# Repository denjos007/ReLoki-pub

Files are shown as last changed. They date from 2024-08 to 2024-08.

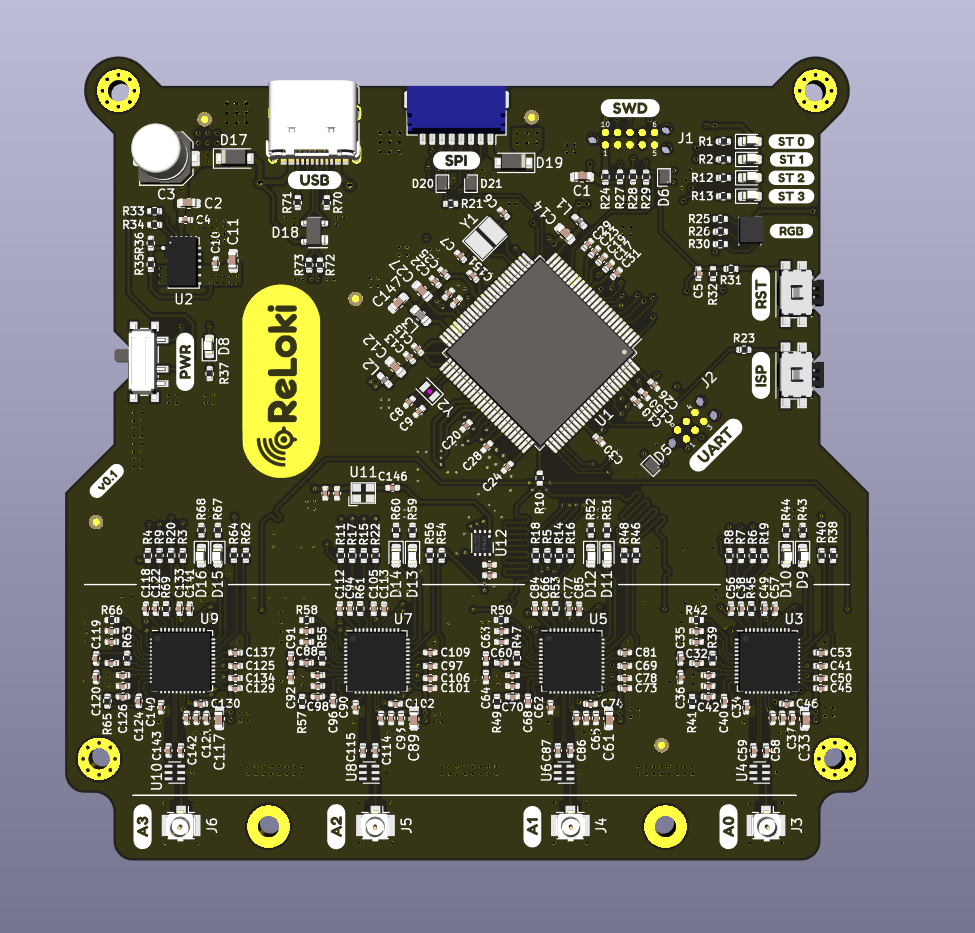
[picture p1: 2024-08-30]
hardware/ReLoki_ECAD/Print_OP/ReLoki_ECAD_PCB_3D-v0_1_0.png

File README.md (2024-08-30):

# ReLoki-pub

ReLoki  is a Infrastructre-free UWB based relative localization system. It uses a combination of TWR and Geometric AoA for full 3D localizattion and message transfer between participating agents. 

This repository will contain the hardware schematics to get ReLoki operational. 

# Hardware

The files to fabricate the PCB for ReLoki are in hardware folder.
1. ReLoki_ECAD: ReLoki Controller PCB 
2. UWB_Antenna_Circular: Individual circular antenna
3. UWB_Antenna_SqArray: UWB antenna in the uniform circular array configuration
4. 3D Parts: 3D printed parts for the RTA Antenna array.

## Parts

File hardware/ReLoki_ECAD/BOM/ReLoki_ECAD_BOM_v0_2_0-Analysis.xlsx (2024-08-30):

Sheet: ReLoki_ECAD_BOM_v0_2_0
Ref | Value | Footprint | Vendor | Link | Price/unit | Qnty | Buffer | N.boards | Total Qty | Total Price | Remarks | Received
C1, | 10u | Capacitor_SMD:C_0603_1608Metric | Taiyo Yuden | https://www.mouser.com/ProductDetail/Taiyo-Yuden/JMK107ABJ106MA-T?qs=vF%252B8ahGVilcKzRI4EvLHOA%3D%3D | $0.11 | 1 |  | 1 | 1 | $0.11
C2, | 4u7 35V | Capacitor_SMD:C_0603_1608Metric | Murata Electronics | https://www.mouser.com/ProductDetail/Murata-Electronics/GRM188R6YA475KE15D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 | $0.33 | 1 |  | 1 | 1 | $0.33
C3, | 47uF 35V | Capacitor_SMD:C_Elec_5x5.8 | United Chemi Con | https://www.mouser.com/ProductDetail/United-Chemi-Con/EMZR350ARA470ME61G?qs=y6ZabgHbY%252BwapqGfn3nqNQ%3D%3D | $0.58 | 1 |  | 1 | 1 | $0.58
C4, | 10n 35V | Capacitor_SMD:C_0402_1005Metric | TDK | https://www.mouser.com/ProductDetail/TDK/CGA2B3X7R1V103K050BB?qs=NRhsANhppD9oCsWh2mTIKA%3D%3D | $0.10 | 1 |  | 1 | 1 | $0.10
C5, C10, C18, C21, C23, C28, C29, C31, C34, C62, C90, C118, C150, C151, C153, C154, | 10n | Capacitor_SMD:C_0402_1005Metric | TDK | https://www.mouser.com/ProductDetail/TDK/CGA2B3X7R1V103K050BB?qs=NRhsANhppD9oCsWh2mTIKA%3D%3D | $0.10 | 16 |  | 1 | 16 | $1.60
C6, C7, | 8p | Capacitor_SMD:C_0402_1005Metric | Kemet | https://www.mouser.com/ProductDetail/KEMET/CBR04C809B3GAC?qs=kpVq%2FgIAs518pFNfJF4O5w%3D%3D | $0.21 | 2 |  | 1 | 2 | $0.42
C8, C9, | 22p | Capacitor_SMD:C_0402_1005Metric | Kemet | https://www.mouser.com/ProductDetail/KEMET/CBR04C220J5GACAUTO?qs=By6Nw2ByBD1qU5yzrYCnBg%3D%3D | $0.21 | 2 |  | 1 | 2 | $0.42
C11, C12, C147, | 22u | Capacitor_SMD:C_0603_1608Metric | Murata Electronics | https://www.mouser.com/ProductDetail/Murata-Electronics/GRM188R61A226ME15D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 | $0.22 | 3 |  | 1 | 3 | $0.66
C13, C16, C19, C20, C24, C25, C26, C30, C36, C37, C38, C41, C44, C45, C46, C47, C48, C49, C50, C51, C53, C54, C56, C57, C64, C65, C66, C69, C72, C73, C74, C75, C76, C77, C78, C79, C81, C82, C84, C85, C92, C93, C94, C97, C100, C101, C102, C103, C104, C105, C106, C107, C109, C110, C112, C113, C120, C121, C122, C125, C128, C129, C130, C131, C132, C133, C134, C135, C137, C138, C140, C141, C144, C148, C149, C152, | 0u1 | Capacitor_SMD:C_0402_1005Metric | Kemet | https://www.mouser.com/ProductDetail/KEMET/C0402C104K4RACTU?qs=DBJr%252BvBUjU54jK7d4uAeew%3D%3D | $0.11 | 76 |  | 1 | 76 | $8.36
C14, | 4u7 | Capacitor_SMD:C_0603_1608Metric | Taiyo Yuden | https://www.mouser.com/ProductDetail/Taiyo-Yuden/LMK107BJ475KA-T?qs=PzICbMaShUfCoRlxZeLF0g%3D%3D | $0.19 | 1 |  | 1 | 1 | $0.19
C15, C17, C22, | 47p | Capacitor_SMD:C_0402_1005Metric | Kemet | https://www.mouser.com/ProductDetail/KEMET/C0402C470K3RACAUTO?qs=gt1LBUVyoHlYXEU%252BlOISDw%3D%3D | $0.12 | 3 |  | 1 | 3 | $0.36
C27, | 2u2 | Capacitor_SMD:C_0603_1608Metric | Taiyo Yuden | https://www.mouser.com/ProductDetail/Taiyo-Yuden/EMK107ABJ225KA8T?qs=hWgE7mdIu5Tcg5OpvamJ9g%3D%3D | $0.18 | 1 |  | 1 | 1 | $0.18
C32, C60, C88, C116, | 1p2 | Capacitor_SMD:C_0402_1005Metric | Kemet | https://www.mouser.com/ProductDetail/KEMET/CBR04C129B5GACAUTO?qs=By6Nw2ByBD1LE0W42y%2F8KA%3D%3D | $0.19 | 4 |  | 1 | 4 | $0.76 | PLL capacitor; Use C0G as dielectric
C33, C61, C89, C117, | 47u | Capacitor_SMD:C_0603_1608Metric | Murata Electronics | https://www.mouser.com/ProductDetail/Murata-Electronics/GRM188R60J476ME01D?qs=pUKx8fyJudCK31TI9jwJqA%3D%3D | $0.46 | 4 |  | 1 | 4 | $1.84
C35, C63, C91, C119, | 27p | Capacitor_SMD:C_0402_1005Metric | Murata Electronics | https://www.mouser.com/ProductDetail/Murata-Electronics/GJM1555C1H270FB01D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 | $0.17 | 4 |  | 1 | 4 | $0.68 | PLL capacitor; Use C0G as dielectric
C39, C52, C67, C80, C95, C108, C123, C136, | 10p | Capacitor_SMD:C_0402_1005Metric | Kemet | https://www.mouser.com/ProductDetail/KEMET/C0402C100K5RACAUTO?qs=hzBznG4dWXWvk2ClWTGJYg%3D%3D | $0.10 | 8 |  | 1 | 8 | $0.80
C40, C68, C96, C124, | 18p | Capacitor_SMD:C_0402_1005Metric | Murata Electronics | https://www.mouser.com/ProductDetail/Murata-Electronics/GJM1555C1H180FB01D?qs=pwh76yelNxAjV3lxNx675g%3D%3D | $0.17 | 4 |  | 1 | 4 | $0.68 | PLL capacitor; Use C0G as dielectric
C42, C70, C98, C126, | 820p | Capacitor_SMD:C_0402_1005Metric | Murata Electronics | https://www.mouser.com/ProductDetail/Murata-Electronics/GRT1555C1H821FA02D?qs=hd1VzrDQEGhtXTRtEGJzcQ%3D%3D | $0.10 | 4 |  | 1 | 4 | $0.40 | PLL capacitor; Use C0G as dielectric
C43, C55, C71, C83, C99, C111, C127, C139, | 330p | Capacitor_SMD:C_0402_1005Metric | Taiyo Yuden | https://www.mouser.com/ProductDetail/Taiyo-Yuden/HMR105B7331MV-F?qs=DPoM0jnrROXTQ7AM%2FqSNWQ%3D%3D | $0.11 | 8 |  | 1 | 8 | $0.88
C58, C59, C86, C87, C114, C115, C142, C143, | 12p | Capacitor_SMD:C_0402_1005Metric | Kemet | https://www.mouser.com/ProductDetail/KEMET/CBR04C120J5GACAUTO?qs=By6Nw2ByBD1Q0psqJYzcFg%3D%3D | $0.21 | 8 |  | 1 | 8 | $1.68 | RF Capacitor; Use High Q capacitor
C145, | 0n1 | Capacitor_SMD:C_0402_1005Metric | Kemet | https://www.mouser.com/ProductDetail/KEMET/C0402C101K3RACAUTO?qs=DuoOggApuK%2FQ6tIpLsntww%3D%3D | $0.04 | 1 |  | 1 | 1 | $0.04
C146, | 1n | Capacitor_SMD:C_0402_1005Metric | Murata Electronics | https://www.mouser.com/ProductDetail/Murata-Electronics/GCM1555C1H102FA16D?qs=QzBtWTOodeXpE1CTmLdqWQ%3D%3D | $0.17 | 1 |  | 1 | 1 | $0.17 | Clock DC reject capacitor; Use C0G as dielectric
D1, D2, D3, D4, D9, D11, D13, D15, | LED_G | LED_SMD:LED_0603_1608Metric | Wurth Elektronik | https://www.mouser.com/ProductDetail/Wurth-Elektronik/150060VS75000?qs=LlUlMxKIyB1Q1Bi5mQ%2FKLw%3D%3D | $0.16 | 8 |  | 1 | 8 | $1.28
D5, D6, D20, D21, | PESD3V3L4UF | Package_TO_SOT_SMD:SOT-886 | Nexperia | https://www.mouser.com/ProductDetail/Nexperia/PESD3V3L4UF115?qs=LOCUfHb8d9tNJS4807IAKw%3D%3D | $0.48 | 4 |  | 1 | 4 | $1.92
D7, | LED_ABGR | LED_SMD:LED_Cree-PLCC4_2x2mm_CW | Cree | https://www.mouser.com/ProductDetail/Cree-LED/CLMVC-FKA-CLBDGL7LBB79353?qs=fSnNYG2PaKLnACIKsEWrKA%3D%3D | $0.18 | 1 |  | 1 | 1 | $0.18
D8, | LED_R | LED_SMD:LED_0603_1608Metric | Wurth Elektronik | https://www.mouser.com/ProductDetail/Wurth-Elektronik/150060RS75000?qs=LlUlMxKIyB3QnmZ3fw%2FVCA%3D%3D | $0.16 | 1 |  | 1 | 1 | $0.16
D10, D12, D14, D16, | LED_Y | LED_SMD:LED_0603_1608Metric | Wurth Elektronik | https://www.mouser.com/ProductDetail/Wurth-Elektronik/150060YS75000?qs=LlUlMxKIyB0nKmwefHgtZw%3D%3D | $0.16 | 4 |  | 1 | 4 | $0.64
D17, D19, | D_Schottky | Diode_SMD:D_SOD-123F | Nexperia | https://www.mouser.com/ProductDetail/Nexperia/PMEG3020EH115?qs=LOCUfHb8d9sEqW1%2FaaOfTw%3D%3D | $0.44 | 2 |  | 1 | 2 | $0.88
D18, | PRTR5V0U2X | Package_TO_SOT_SMD:SOT-143 | Nexperia | https://www.mouser.com/ProductDetail/Nexperia/PRTR5V0U2X215?qs=LOCUfHb8d9sDkgY4cRj8Lw%3D%3D | $0.53 | 1 |  | 1 | 1 | $0.53
J3, J4, J5, J6, | Uf.l | Connector_Coaxial:U.FL_Hirose_U.FL-R-SMT-1_Vertical | Hirose | https://www.mouser.com/ProductDetail/Hirose-Connector/U.FL-R-SMT-140?qs=PABxe4V6HDrVNWAmh6WKgw%3D%3D | $1.04 | 8 |  | 1 | 8 | $8.32
J7, | USB_C_Receptacle_USB2.0 | Connector_USB:USB_C_Receptacle_XKB_U262-16XN-4BVC11 | GCT | https://www.mouser.com/ProductDetail/GCT/USB4105-GF-A?qs=KUoIvG%2F9IlY%2FMLlBMpStpA%3D%3D | $0.81 | 1 |  | 1 | 1 | $0.81
J8, | JST_SH_SM08B | Connector_JST:JST_SH_SM08B-SRSS-TB_1x08-1MP_P1.00mm_Horizontal | JST | DNP (Local Stock Available) | $0.88 | 1 |  | 1 | 1 | $0.88
L1, L2, | Ferrite | Inductor_SMD:L_0402_1005Metric_Pad0.77x0.64mm_HandSolder | Laird | https://www.mouser.com/ProductDetail/Laird-Performance-Materials/MI0603J601R-10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 | $0.21 | 2 |  | 1 | 2 | $0.42 | Preferred MI0603J601R-10
L3, | 4.7u | Inductor_SMD:L_0603_1608Metric | Murata Electronics | https://www.mouser.com/ProductDetail/Murata-Electronics/LQM18PH4R7MFRL?qs=rkhjVJ6%2F3EI1lKcr9JG66A%3D%3D | $0.45 | 1 |  | 1 | 1 | $0.45
R1, R2, R12, R13, R25, R37, R43, R44, R51, R52, R59, R60, R67, R68, | 270R | Resistor_SMD:R_0402_1005Metric | Panasonic | https://www.mouser.com/ProductDetail/Panasonic/ERJ-2GEJ271X | $0.10 | 19 |  | 1 | 19 | $1.90
R3, R4, R5, R6, R7, R8, R9, R10, R11, R14, R15, R16, R17, R18, R19, R20, R21, R22, R24, | 0R | Resistor_SMD:R_0402_1005Metric | Panasonic | https://www.mouser.com/ProductDetail/Panasonic/ERJ-2GE0R00X?qs=sGAEpiMZZMvdGkrng054t8ugkoYZivkgZAstS7FxYdI%3D | $0.10 | 19 |  | 1 | 19 | $1.90
R23, | 2k2 | Resistor_SMD:R_0402_1005Metric | Panasonic | https://www.mouser.com/ProductDetail/Panasonic/ERJ-2RKF2201X?qs=sGAEpiMZZMvdGkrng054t8AJgcdMkx7xLDqgTrDrCxE%3D | $0.10 | 1 |  | 1 | 1 | $0.10
R26, | 80R | Resistor_SMD:R_0402_1005Metric | Panasonic | https://www.mouser.com/ProductDetail/Panasonic/ERJ-2RKF80R6X?qs=sGAEpiMZZMvdGkrng054t8AJgcdMkx7xczhHERSBWmA%3D | $0.10 | 1 |  | 1 | 1 | $0.10
R27, R28, R29, R38, R46, R54, R62, R76, R77, | 10K | Resistor_SMD:R_0402_1005Metric | Panasonic | https://www.mouser.com/ProductDetail/Panasonic/ERJ-2RKF1002X?qs=sGAEpiMZZMvdGkrng054t8ugkoYZivkgyTBPpPnizTM%3D | $0.10 | 9 |  | 1 | 9 | $0.90
R30, | 60R | Resistor_SMD:R_0402_1005Metric | Panasonic | https://www.mouser.com/ProductDetail/Panasonic/ERJ-2RKF60R4X?qs=sGAEpiMZZMvdGkrng054t8AJgcdMkx7xUvDRJja01bU%3D | $0.10 | 1 |  | 1 | 1 | $0.10
R31, | 100R | Resistor_SMD:R_0402_1005Metric | Panasonic | https://www.mouser.com/ProductDetail/Panasonic/ERJ-2RKF1000X | $0.10 | 1 |  | 1 | 1 | $0.10
R32, R74, R75, | 100K | Resistor_SMD:R_0402_1005Metric | Panasonic | https://www.mouser.com/ProductDetail/Panasonic/ERJ-2RKF1003X | $0.10 | 3 |  | 1 | 3 | $0.30
R33, | 55K | Resistor_SMD:R_0402_1005Metric | Panasonic | https://www.mouser.com/ProductDetail/Panasonic/ERJ-2RKF5492X?qs=sGAEpiMZZMvdGkrng054t8AJgcdMkx7x0kySjptXP2k%3D | $0.10 | 1 |  | 1 | 1 | $0.10
R34, | 62K | Resistor_SMD:R_0402_1005Metric | Panasonic | https://www.mouser.com/ProductDetail/Panasonic/ERA-2AED623X | $0.22 | 1 |  | 1 | 1 | $0.22
R35, | 75K | Resistor_SMD:R_0402_1005Metric | Panasonic | https://www.mouser.com/ProductDetail/Panasonic/ERA-2AED753X | $0.22 | 1 |  | 1 | 1 | $0.22
R36, | 24K | Resistor_SMD:R_0402_1005Metric | Panasonic | https://www.mouser.com/ProductDetail/Panasonic/ERA-2AED243X | $0.22 | 1 |  | 1 | 1 | $0.22
R41, R49, R57, R65, | 270R 1% | Resistor_SMD:R_0402_1005Metric | Panasonic | https://www.mouser.com/ProductDetail/Panasonic/ERA-2ARB271X | $0.82 | 4 |  | 1 | 4 | $3.28 | PLL Resistor; Use higher tolerence
R39, R47, R55, R63, | 16k 1% | Resistor_SMD:R_0402_1005Metric | Panasonic | https://www.mouser.com/ProductDetail/Panasonic/ERA-2ARB163X | $0.76 | 4 |  | 1 | 4 | $3.04 | PLL Resistor; Use higher tolerence
R42, R50, R58, R66, | 11K 1% | Resistor_SMD:R_0402_1005Metric | Panasonic | https://www.mouser.com/ProductDetail/Panasonic/ERA-2ARB113X | $0.82 | 4 |  | 1 | 4 | $3.28 | PLL Resistor; Use higher tolerence
R70, R71, | 5.1K | Resistor_SMD:R_0402_1005Metric | Panasonic | https://www.mouser.com/ProductDetail/Panasonic/ERJ-2RKF5101X?qs=sGAEpiMZZMvdGkrng054t8AJgcdMkx7xIXmurKOGv8o%3D | $0.10 | 2 |  | 1 | 2 | $0.20
R72, R73, | 33R | Resistor_SMD:R_0402_1005Metric | Panasonic | https://www.mouser.com/ProductDetail/Panasonic/ERJ-2RKF33R0X | $0.10 | 2 |  | 1 | 2 | $0.20
R78, R79, R80, R81, R82, | 30R | Resistor_SMD:R_0402_1005Metric | Panasonic | https://www.mouser.com/ProductDetail/Panasonic/ERJ-S02F30R0X?qs=Zyl8A9hlmJrZ4c5s5myrJA%3D%3D | $0.50 | 5 |  | 1 | 5 | $2.50
SW1, SW2, | SW_Push | Button_Switch_SMD:Panasonic_EVQPUL_EVQPUC | Panasonic | DNP (Local Stock Available) | DNP | 2 |  | 1 | 2 | $0.00
SW3, | SW_SPDT | Button_Switch_SMD:SW_SPDT_PCM12 | Panasonic | DNP (Local Stock Available) | DNP | 1 |  | 1 | 1 | $0.00
U1, | LPC55S69JBD100 | Package_QFP_U:HLQFP-100_14x14mm_P0.5mm | NXP | DNP (Local Stock Available) | $10.95 | 1 |  | 1 | 1 | $10.95
U2, | MPM3610 | Package_DFN_QFN_U:MPM3610_QFN-20_5x3mm | MPS | https://www.mouser.com/ProductDetail/Monolithic-Power-Systems-MPS/MPM3610AGQV-Z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 | $2.84 | 1 |  | 1 | 1 | $2.84
U3, U5, U7, U9, | DW1000 | Package_DFN_QFN:QFN-48-1EP_6x6mm_P0.4mm_EP4.2x4.2mm_ThermalVias | Decawave | DNP (Local Stock Available) | $8.78 | 4 |  | 1 | 4 | $35.12
U4, U6, U8, U10, | HHM1595A1 | RF_U:HHM1595A1 | TDK | https://www.mouser.com/ProductDetail/TDK/HHM1595A1?qs=CQ%2FIPMfstfij2T2%252BDRqDhg%3D%3D | $0.53 | 4 |  | 1 | 4 | $2.12
U11, | ATX-13 | Oscillator_U:Oscillator_SMD_Abracon_ATX13-4Pin_2.0x1.6mm | Abracon | https://www.mouser.com/ProductDetail/ABRACON/ATX-13-F-38.400MHz-F05-T?qs=iLbezkQI%252BshZJhENXwm%252B3g%3D%3D | $3.48 | 1 |  | 1 | 1 | $3.48
U12, | SN74AUP1G74RSER | Package_DFN_QFN_U:UQFN-8-1.55x1.55mm_P0.5mm | Texas Instruments | https://www.mouser.com/ProductDetail/Texas-Instruments/SN74AUP1G74RSER?qs=EuM%2FBx4ov4RGFdXbpZrTyw%3D%3D | $0.62 | 1 |  | 1 | 1 | $0.62
U13, U14, | PL133-37 | Package_TO_SOT_SMD:SOT-23-6 | Microchip | https://www.mouser.com/ProductDetail/Microchip-Technology-Atmel/PL133-37TC?qs=kh6iOki%2FeLHkQC7CE79YnA%3D%3D | $0.73 | 2 |  | 1 | 2 | $1.46
Y1, | 16MHz | Crystal_U:Crystal_SMD_Kyocera_CX3225G-2Pin_3.2x2.5mm | Kyocera | https://www.mouser.com/ProductDetail/KYOCERA-AVX/CX3225GA16000D0PTVCC?qs=k8ubvZJoN9Dbjg7lrNet2Q%3D%3D | $0.88 | 1 |  | 1 | 1 | $0.88
Y2, | 32.768kHz | Crystal:Crystal_SMD_2012-2Pin_2.0x1.2mm | ECS | https://www.mouser.com/ProductDetail/ECS/ECS-.327-12.5-12R-TR?qs=fAHHVMwC%252BbjIsh0rr7Av6w%3D%3D | $0.65 | 1 |  | 1 | 1 | $0.65
ANT1 | AH086M555003-T | ~ | Taiyo Yuden | https://www.mouser.com/ProductDetail/Taiyo-Yuden/AH086M555003-T?qs=I6KAKw0tg2yFCZ22SDTD%252Bg%3D%3D | $6.42 | 4 |  | 1 | 4 | $25.68
ANT2 | FXUWB20.07.0100C | ~ | TAOGLAS | https://www.mouser.com/ProductDetail/Taoglas/FXUWB20.07.0100C?qs=rrS6PyfT74cvleDgfnNojg%3D%3D | $7.95 | 4 |  | 1 | 4 | $31.80
J9, J10, J11, J12 | Uf.l Cable | ~ | Hirose | https://www.mouser.com/ProductDetail/Hirose-Connector/U.FL-2LPHF6-068N1T-A-120?qs=uwxL4vQweFN2eJ9voIBidg%3D%3D | $5.07 | 4 |  | 1 | 4 | $20.28
 |  |  |  |  | Total Parts |  |  |  |  | $192.25
 |  |  |  |  | PCB |  |  |  |  | 33.59
 | ` |  |  |  |  |  |  |  |  | $225.84

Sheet: 1 antenna
Ref | Value | Cmp name | Footprint | Description | Vendor | Link | Price/unit | Qnty | Buffer | N.boards | Total Qty | Total Price | Remarks | Received
C1, | 10u | C_Small | Capacitor_SMD:C_0603_1608Metric | Unpolarized capacitor, small symbol | Taiyo Yuden | https://www.mouser.com/ProductDetail/Taiyo-Yuden/JMK107ABJ106MA-T?qs=vF%252B8ahGVilcKzRI4EvLHOA%3D%3D | $0.11 | 1 |  | 1 | 1 | $0.11
C2, | 4u7 35V | C_Small | Capacitor_SMD:C_0603_1608Metric | Unpolarized capacitor, small symbol | Murata Electronics | https://www.mouser.com/ProductDetail/Murata-Electronics/GRM188R6YA475KE15D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 | $0.33 | 1 |  | 1 | 1 | $0.33
C3, | 47uF 35V | C_Polarized_Small | Capacitor_SMD:C_Elec_5x5.8 | Polarized capacitor, small symbol | United Chemi Con | https://www.mouser.com/ProductDetail/United-Chemi-Con/EMZR350ARA470ME61G?qs=y6ZabgHbY%252BwapqGfn3nqNQ%3D%3D | $0.58 | 1 |  | 1 | 1 | $0.58
C4, | 10n 35V | C_Small | Capacitor_SMD:C_0402_1005Metric | Unpolarized capacitor, small symbol | TDK | https://www.mouser.com/ProductDetail/TDK/CGA2B3X7R1V103K050BB?qs=NRhsANhppD9oCsWh2mTIKA%3D%3D | $0.10 | 1 |  | 1 | 1 | $0.10
C5, C10, C18, C21, C23, C28, C29, C31, C34, C62, C90, C118, C150, C151, C153, C154, | 10n | C_Small | Capacitor_SMD:C_0402_1005Metric | Unpolarized capacitor, small symbol | TDK | https://www.mouser.com/ProductDetail/TDK/CGA2B3X7R1V103K050BB?qs=NRhsANhppD9oCsWh2mTIKA%3D%3D | $0.10 | 10 |  | 1 | 10 | $1.00
C6, C7, | 8p | C_Small | Capacitor_SMD:C_0402_1005Metric | Unpolarized capacitor, small symbol | Kemet | https://www.mouser.com/ProductDetail/KEMET/CBR04C809B3GAC?qs=kpVq%2FgIAs518pFNfJF4O5w%3D%3D | $0.21 | 2 |  | 1 | 2 | $0.42
C8, C9, | 22p | C_Small | Capacitor_SMD:C_0402_1005Metric | Unpolarized capacitor, small symbol | Kemet | https://www.mouser.com/ProductDetail/KEMET/CBR04C220J5GACAUTO?qs=By6Nw2ByBD1qU5yzrYCnBg%3D%3D | $0.21 | 2 |  | 1 | 2 | $0.42
C11, C12, C147, | 22u | C_Small | Capacitor_SMD:C_0603_1608Metric | Unpolarized capacitor, small symbol | Murata Electronics | https://www.mouser.com/ProductDetail/Murata-Electronics/GRM188R61A226ME15D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 | $0.22 | 3 |  | 1 | 3 | $0.66
C13, C16, C19, C20, C24, C25, C26, C30, C36, C37, C38, C41, C44, C45, C46, C47, C48, C49, C50, C51, C53, C54, C56, C57, C64, C65, C66, C69, C72, C73, C74, C75, C76, C77, C78, C79, C81, C82, C84, C85, C92, C93, C94, C97, C100, C101, C102, C103, C104, C105, C106, C107, C109, C110, C112, C113, C120, C121, C122, C125, C128, C129, C130, C131, C132, C133, C134, C135, C137, C138, C140, C141, C144, C148, C149, C152, | 0u1 | C_Small | Capacitor_SMD:C_0402_1005Metric | Unpolarized capacitor, small symbol | Kemet | https://www.mouser.com/ProductDetail/KEMET/C0402C104K4RACTU?qs=DBJr%252BvBUjU54jK7d4uAeew%3D%3D | $0.11 | 25 |  | 1 | 25 | $2.75
C14, | 4u7 | C_Small | Capacitor_SMD:C_0603_1608Metric | Unpolarized capacitor, small symbol | Taiyo Yuden | https://www.mouser.com/ProductDetail/Taiyo-Yuden/LMK107BJ475KA-T?qs=PzICbMaShUfCoRlxZeLF0g%3D%3D | $0.19 | 1 |  | 1 | 1 | $0.19
C15, C17, C22, | 47p | C_Small | Capacitor_SMD:C_0402_1005Metric | Unpolarized capacitor, small symbol | Kemet | https://www.mouser.com/ProductDetail/KEMET/C0402C470K3RACAUTO?qs=gt1LBUVyoHlYXEU%252BlOISDw%3D%3D | $0.12 | 3 |  | 1 | 3 | $0.36
C27, | 2u2 | C_Small | Capacitor_SMD:C_0603_1608Metric | Unpolarized capacitor, small symbol | Taiyo Yuden | https://www.mouser.com/ProductDetail/Taiyo-Yuden/EMK107ABJ225KA8T?qs=hWgE7mdIu5Tcg5OpvamJ9g%3D%3D | $0.18 | 1 |  | 1 | 1 | $0.18
C32, C60, C88, C116, | 1p2 | C_Small | Capacitor_SMD:C_0402_1005Metric | Unpolarized capacitor, small symbol | Kemet | https://www.mouser.com/ProductDetail/KEMET/CBR04C129B5GACAUTO?qs=By6Nw2ByBD1LE0W42y%2F8KA%3D%3D | $0.19 | 1 |  | 1 | 1 | $0.19 | PLL capacitor; Use C0G as dielectric
C33, C61, C89, C117, | 47u | C_Small | Capacitor_SMD:C_0603_1608Metric | Unpolarized capacitor, small symbol | Murata Electronics | https://www.mouser.com/ProductDetail/Murata-Electronics/GRM188R60J476ME01D?qs=pUKx8fyJudCK31TI9jwJqA%3D%3D | $0.46 | 1 |  | 1 | 1 | $0.46
C35, C63, C91, C119, | 27p | C_Small | Capacitor_SMD:C_0402_1005Metric | Unpolarized capacitor, small symbol | Murata Electronics | https://www.mouser.com/ProductDetail/Murata-Electronics/GJM1555C1H270FB01D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 | $0.17 | 1 |  | 1 | 1 | $0.17 | PLL capacitor; Use C0G as dielectric
C39, C52, C67, C80, C95, C108, C123, C136, | 10p | C_Small | Capacitor_SMD:C_0402_1005Metric | Unpolarized capacitor, small symbol | Kemet | https://www.mouser.com/ProductDetail/KEMET/C0402C100K5RACAUTO?qs=hzBznG4dWXWvk2ClWTGJYg%3D%3D | $0.10 | 2 |  | 1 | 2 | $0.20
C40, C68, C96, C124, | 18p | C_Small | Capacitor_SMD:C_0402_1005Metric | Unpolarized capacitor, small symbol | Murata Electronics | https://www.mouser.com/ProductDetail/Murata-Electronics/GJM1555C1H180FB01D?qs=pwh76yelNxAjV3lxNx675g%3D%3D | $0.17 | 1 |  | 1 | 1 | $0.17 | PLL capacitor; Use C0G as dielectric
C42, C70, C98, C126, | 820p | C_Small | Capacitor_SMD:C_0402_1005Metric | Unpolarized capacitor, small symbol | Murata Electronics | https://www.mouser.com/ProductDetail/Murata-Electronics/GRT1555C1H821FA02D?qs=hd1VzrDQEGhtXTRtEGJzcQ%3D%3D | $0.10 | 1 |  | 1 | 1 | $0.10 | PLL capacitor; Use C0G as dielectric
C43, C55, C71, C83, C99, C111, C127, C139, | 330p | C_Small | Capacitor_SMD:C_0402_1005Metric | Unpolarized capacitor, small symbol | Taiyo Yuden | https://www.mouser.com/ProductDetail/Taiyo-Yuden/HMR105B7331MV-F?qs=DPoM0jnrROXTQ7AM%2FqSNWQ%3D%3D | $0.11 | 2 |  | 1 | 2 | $0.22
C58, C59, C86, C87, C114, C115, C142, C143, | 12p | C_Small | Capacitor_SMD:C_0402_1005Metric | Unpolarized capacitor, small symbol | Kemet | https://www.mouser.com/ProductDetail/KEMET/CBR04C120J5GACAUTO?qs=By6Nw2ByBD1Q0psqJYzcFg%3D%3D | $0.21 | 2 |  | 1 | 2 | $0.42 | RF Capacitor; Use High Q capacitor
C145, | 0n1 | C_Small | Capacitor_SMD:C_0402_1005Metric | Unpolarized capacitor, small symbol | Kemet | https://www.mouser.com/ProductDetail/KEMET/C0402C101K3RACAUTO?qs=DuoOggApuK%2FQ6tIpLsntww%3D%3D | $0.04 | 1 |  | 1 | 1 | $0.04
C146, | 1n | C_Small | Capacitor_SMD:C_0402_1005Metric | Unpolarized capacitor, small symbol | Murata Electronics | https://www.mouser.com/ProductDetail/Murata-Electronics/GCM1555C1H102FA16D?qs=QzBtWTOodeXpE1CTmLdqWQ%3D%3D | $0.17 | 1 |  | 1 | 1 | $0.17 | Clock DC reject capacitor; Use C0G as dielectric
D1, D2, D3, D4, D9, D11, D13, D15, | LED_G | LED_Small | LED_SMD:LED_0603_1608Metric | Light emitting diode, small symbol | Wurth Elektronik | https://www.mouser.com/ProductDetail/Wurth-Elektronik/150060VS75000?qs=LlUlMxKIyB1Q1Bi5mQ%2FKLw%3D%3D | $0.16 | 8 |  | 1 | 8 | $1.28
D5, D6, D20, D21, | PESD3V3L4UF | PESD3V3L4UF | Package_TO_SOT_SMD:SOT-886 | Low capacitance unidirectional quadruple ESD protection diode array, 3.3V, Common Anode, SOT-886 | Nexperia | https://www.mouser.com/ProductDetail/Nexperia/PESD3V3L4UF115?qs=LOCUfHb8d9tNJS4807IAKw%3D%3D | $0.48 | 4 |  | 1 | 4 | $1.92
D7, | LED_ABGR | LED_ABGR | LED_SMD:LED_Cree-PLCC4_2x2mm_CW | RGB LED, anode/blue/green/red | Cree | https://www.mouser.com/ProductDetail/Cree-LED/CLMVC-FKA-CLBDGL7LBB79353?qs=fSnNYG2PaKLnACIKsEWrKA%3D%3D | $0.18 | 1 |  | 1 | 1 | $0.18
D8, | LED_R | LED_Small | LED_SMD:LED_0603_1608Metric | Light emitting diode, small symbol | Wurth Elektronik | https://www.mouser.com/ProductDetail/Wurth-Elektronik/150060RS75000?qs=LlUlMxKIyB3QnmZ3fw%2FVCA%3D%3D | $0.16 | 1 |  | 1 | 1 | $0.16
D10, D12, D14, D16, | LED_Y | LED_Small | LED_SMD:LED_0603_1608Metric | Light emitting diode, small symbol | Wurth Elektronik | https://www.mouser.com/ProductDetail/Wurth-Elektronik/150060YS75000?qs=LlUlMxKIyB0nKmwefHgtZw%3D%3D | $0.16 | 4 |  | 1 | 4 | $0.64
D17, D19, | D_Schottky | D_Schottky | Diode_SMD:D_SOD-123F | Schottky diode | Nexperia | https://www.mouser.com/ProductDetail/Nexperia/PMEG3020EH115?qs=LOCUfHb8d9sEqW1%2FaaOfTw%3D%3D | $0.44 | 2 |  | 1 | 2 | $0.88
D18, | PRTR5V0U2X | PRTR5V0U2X | Package_TO_SOT_SMD:SOT-143 | Ultra low capacitance double rail-to-rail ESD protection diode, SOT-143 | Nexperia | https://www.mouser.com/ProductDetail/Nexperia/PRTR5V0U2X215?qs=LOCUfHb8d9sDkgY4cRj8Lw%3D%3D | $0.53 | 1 |  | 1 | 1 | $0.53
J3, J4, J5, J6, | Uf.l | Conn_Coaxial | Connector_Coaxial:U.FL_Hirose_U.FL-R-SMT-1_Vertical | coaxial connector (BNC, SMA, SMB, SMC, Cinch/RCA, LEMO, ...) | Hirose | https://www.mouser.com/ProductDetail/Hirose-Connector/U.FL-R-SMT-140?qs=PABxe4V6HDrVNWAmh6WKgw%3D%3D | $1.04 | 2 |  | 1 | 2 | $2.08
J7, | USB_C_Receptacle_USB2.0 | USB_C_Receptacle_USB2.0 | Connector_USB:USB_C_Receptacle_XKB_U262-16XN-4BVC11 | USB 2.0-only Type-C Receptacle connector | GCT | https://www.mouser.com/ProductDetail/GCT/USB4105-GF-A?qs=KUoIvG%2F9IlY%2FMLlBMpStpA%3D%3D | $0.81 | 1 |  | 1 | 1 | $0.81
J8, | JST_SH_SM08B | Conn_01x08 | Connector_JST:JST_SH_SM08B-SRSS-TB_1x08-1MP_P1.00mm_Horizontal | Generic connector, single row, 01x08, script generated (kicad-library-utils/schlib/autogen/connector/) | JST | DNP (Local Stock Available) | $0.88 | 1 |  | 1 | 1 | $0.88
L1, L2, | Ferrite | L_Small | Inductor_SMD:L_0402_1005Metric_Pad0.77x0.64mm_HandSolder | Inductor, small symbol | Laird | https://www.mouser.com/ProductDetail/Laird-Performance-Materials/MI0603J601R-10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 | $0.21 | 2 |  | 1 | 2 | $0.42 | Preferred MI0603J601R-10
L3, | 4.7u | L_Small | Inductor_SMD:L_0603_1608Metric | Inductor, small symbol | Murata Electronics | https://www.mouser.com/ProductDetail/Murata-Electronics/LQM18PH4R7MFRL?qs=rkhjVJ6%2F3EI1lKcr9JG66A%3D%3D | $0.45 | 1 |  | 1 | 1 | $0.45
R1, R2, R12, R13, R25, R37, R43, R44, R51, R52, R59, R60, R67, R68, | 270R | R_Small | Resistor_SMD:R_0402_1005Metric | Resistor, small symbol | Panasonic | https://www.mouser.com/ProductDetail/Panasonic/ERJ-2GEJ271X | $0.10 | 13 |  | 1 | 13 | $1.30
R3, R4, R5, R6, R7, R8, R9, R10, R11, R14, R15, R16, R17, R18, R19, R20, R21, R22, R24, | 0R | R_Small | Resistor_SMD:R_0402_1005Metric | Resistor, small symbol | Panasonic | https://www.mouser.com/ProductDetail/Panasonic/ERJ-2GE0R00X?qs=sGAEpiMZZMvdGkrng054t8ugkoYZivkgZAstS7FxYdI%3D | $0.10 | 19 |  | 1 | 19 | $1.90
R23, | 2k2 | R_Small | Resistor_SMD:R_0402_1005Metric | Resistor, small symbol | Panasonic | https://www.mouser.com/ProductDetail/Panasonic/ERJ-2RKF2201X?qs=sGAEpiMZZMvdGkrng054t8AJgcdMkx7xLDqgTrDrCxE%3D | $0.10 | 1 |  | 1 | 1 | $0.10
R26, | 80R | R_Small | Resistor_SMD:R_0402_1005Metric | Resistor, small symbol | Panasonic | https://www.mouser.com/ProductDetail/Panasonic/ERJ-2RKF80R6X?qs=sGAEpiMZZMvdGkrng054t8AJgcdMkx7xczhHERSBWmA%3D | $0.10 | 1 |  | 1 | 1 | $0.10
R27, R28, R29, R38, R46, R54, R62, R76, R77, | 10K | R_Small | Resistor_SMD:R_0402_1005Metric | Resistor, small symbol | Panasonic | https://www.mouser.com/ProductDetail/Panasonic/ERJ-2RKF1002X?qs=sGAEpiMZZMvdGkrng054t8ugkoYZivkgyTBPpPnizTM%3D | $0.10 | 5 |  | 1 | 5 | $0.50
R30, | 60R | R_Small | Resistor_SMD:R_0402_1005Metric | Resistor, small symbol | Panasonic | https://www.mouser.com/ProductDetail/Panasonic/ERJ-2RKF60R4X?qs=sGAEpiMZZMvdGkrng054t8AJgcdMkx7xUvDRJja01bU%3D | $0.10 | 1 |  | 1 | 1 | $0.10
R31, | 100R | R_Small | Resistor_SMD:R_0402_1005Metric | Resistor, small symbol | Panasonic | https://www.mouser.com/ProductDetail/Panasonic/ERJ-2RKF1000X | $0.10 | 1 |  | 1 | 1 | $0.10
R32, R74, R75, | 100K | R_Small | Resistor_SMD:R_0402_1005Metric | Resistor, small symbol | Panasonic | https://www.mouser.com/ProductDetail/Panasonic/ERJ-2RKF1003X | $0.10 | 3 |  | 1 | 3 | $0.30
R33, | 55K | R_Small | Resistor_SMD:R_0402_1005Metric | Resistor, small symbol | Panasonic | https://www.mouser.com/ProductDetail/Panasonic/ERJ-2RKF5492X?qs=sGAEpiMZZMvdGkrng054t8AJgcdMkx7x0kySjptXP2k%3D | $0.10 | 1 |  | 1 | 1 | $0.10
R34, | 62K | R_Small | Resistor_SMD:R_0402_1005Metric | Resistor, small symbol | Panasonic | https://www.mouser.com/ProductDetail/Panasonic/ERA-2AED623X | $0.22 | 1 |  | 1 | 1 | $0.22
R35, | 75K | R_Small | Resistor_SMD:R_0402_1005Metric | Resistor, small symbol | Panasonic | https://www.mouser.com/ProductDetail/Panasonic/ERA-2AED753X | $0.22 | 1 |  | 1 | 1 | $0.22
R36, | 24K | R_Small | Resistor_SMD:R_0402_1005Metric | Resistor, small symbol | Panasonic | https://www.mouser.com/ProductDetail/Panasonic/ERA-2AED243X | $0.22 | 1 |  | 1 | 1 | $0.22
R41, R49, R57, R65, | 270R 1% | R_Small | Resistor_SMD:R_0402_1005Metric | Resistor, small symbol | Panasonic | https://www.mouser.com/ProductDetail/Panasonic/ERA-2ARB271X | $0.82 | 1 |  | 1 | 1 | $0.82 | PLL Resistor; Use higher tolerence
R39, R47, R55, R63, | 16k 1% | R_Small | Resistor_SMD:R_0402_1005Metric | Resistor, small symbol | Panasonic | https://www.mouser.com/ProductDetail/Panasonic/ERA-2ARB163X | $0.76 | 1 |  | 1 | 1 | $0.76 | PLL Resistor; Use higher tolerence
R42, R50, R58, R66, | 11K 1% | R_Small | Resistor_SMD:R_0402_1005Metric | Resistor, small symbol | Panasonic | https://www.mouser.com/ProductDetail/Panasonic/ERA-2ARB113X | $0.82 | 1 |  | 1 | 1 | $0.82 | PLL Resistor; Use higher tolerence
R70, R71, | 5.1K | R_Small | Resistor_SMD:R_0402_1005Metric | Resistor, small symbol | Panasonic | https://www.mouser.com/ProductDetail/Panasonic/ERJ-2RKF5101X?qs=sGAEpiMZZMvdGkrng054t8AJgcdMkx7xIXmurKOGv8o%3D | $0.10 | 2 |  | 1 | 2 | $0.20
R72, R73, | 33R | R_Small | Resistor_SMD:R_0402_1005Metric | Resistor, small symbol | Panasonic | https://www.mouser.com/ProductDetail/Panasonic/ERJ-2RKF33R0X | $0.10 | 2 |  | 1 | 2 | $0.20
R78, R79, R80, R81, R82, | 30R | R_Small | Resistor_SMD:R_0402_1005Metric | Resistor, small symbol | Panasonic | https://www.mouser.com/ProductDetail/Panasonic/ERJ-S02F30R0X?qs=Zyl8A9hlmJrZ4c5s5myrJA%3D%3D | $0.50 | 5 |  | 1 | 5 | $2.50
SW1, SW2, | SW_Push | SW_Push | Button_Switch_SMD:Panasonic_EVQPUL_EVQPUC | Push button switch, generic, two pins | Panasonic | DNP (Local Stock Available) | DNP | 2 |  | 1 | 2 | $0.00
SW3, | SW_SPDT | SW_SPDT | Button_Switch_SMD:SW_SPDT_PCM12 | Switch, single pole double throw | Panasonic | DNP (Local Stock Available) | DNP | 1 |  | 1 | 1 | $0.00
U1, | LPC55S69JBD100 | LPC55S69JBD100 | Package_QFP_U:HLQFP-100_14x14mm_P0.5mm | ARM Cortex-M33 based microcontroller for embedded applications. 320 KB of on-chip SRAM, 640 KB on-chip flash. | NXP | DNP (Local Stock Available) | $10.95 | 1 |  | 1 | 1 | $10.95
U2, | MPM3610 | MPM3610 | Package_DFN_QFN_U:MPM3610_QFN-20_5x3mm | 4.5 - 21V Buck Converter with integrated inductor and capacitors | MPS | https://www.mouser.com/ProductDetail/Monolithic-Power-Systems-MPS/MPM3610AGQV-Z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 | $2.84 | 1 |  | 1 | 1 | $2.84
U3, U5, U7, U9, | DW1000 | DW1000 | Package_DFN_QFN:QFN-48-1EP_6x6mm_P0.4mm_EP4.2x4.2mm_ThermalVias | fully integrated single chip Ultra Wideband (UWB) low-power low-cost transceiver IC compliant to IEEE802.15.4-2011 | Decawave | DNP (Local Stock Available) | $8.78 | 1 |  | 1 | 1 | $8.78
U4, U6, U8, U10, | HHM1595A1 | HHM1595A1 | RF_U:HHM1595A1 |  | TDK | https://www.mouser.com/ProductDetail/TDK/HHM1595A1?qs=CQ%2FIPMfstfij2T2%252BDRqDhg%3D%3D | $0.53 | 4 |  | 1 | 4 | $2.12
U11, | ATX-13 | ATX-13 | Oscillator_U:Oscillator_SMD_Abracon_ATX13-4Pin_2.0x1.6mm |  | Abracon | https://www.mouser.com/ProductDetail/ABRACON/ATX-13-F-38.400MHz-F05-T?qs=iLbezkQI%252BshZJhENXwm%252B3g%3D%3D | $3.48 | 1 |  | 1 | 1 | $3.48
U12, | SN74AUP1G74RSER | SN74AUP1G74RSER | Package_DFN_QFN_U:UQFN-8-1.55x1.55mm_P0.5mm |  | Texas Instruments | https://www.mouser.com/ProductDetail/Texas-Instruments/SN74AUP1G74RSER?qs=EuM%2FBx4ov4RGFdXbpZrTyw%3D%3D | $0.62 | 1 |  | 1 | 1 | $0.62
U13, U14, | PL133-37 | PL133-37 | Package_TO_SOT_SMD:SOT-23-6 | Low-Power, 1.62V to 3.63V, 1 MHz to 150 MHz, Inverting 1:3 Fanout Buffer IC | Microchip | https://www.mouser.com/ProductDetail/Microchip-Technology-Atmel/PL133-37TC?qs=kh6iOki%2FeLHkQC7CE79YnA%3D%3D | $0.73 | 2 |  | 1 | 2 | $1.46
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

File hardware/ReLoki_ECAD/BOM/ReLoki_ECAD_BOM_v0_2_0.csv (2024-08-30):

Source: | /Users/joseph/Library/CloudStorage/OneDrive-GeorgeMasonUniversity-O365Production/Classwork/Research/Project_BlimpSquad/Projects/Multiagent_RelativeLocalization/hardware/ReLoki_ECAD/ReLoki_ECAD.kicad_sch
Date: | Thursday, November 17, 2022 at 06:54:04 PM
Tool: | Eeschema (6.0.8-1)-1
Generator: | /Applications/KiCad/KiCad.app/Contents/SharedSupport/plugins/bom_csv_grouped_by_value_with_fp.py
Component Count: | 338
Ref | Qnty | Value | Cmp name | Footprint | Description | Vendor
C1, | 1 | 10u | C_Small | Capacitor_SMD:C_0603_1608Metric | Unpolarized capacitor, small symbol
C2, | 1 | 4u7 35V | C_Small | Capacitor_SMD:C_0603_1608Metric | Unpolarized capacitor, small symbol
C3, | 1 | 47uF 35V | C_Polarized_Small | Capacitor_SMD:C_Elec_5x5.8 | Polarized capacitor, small symbol
C4, | 1 | 10n 35V | C_Small | Capacitor_SMD:C_0402_1005Metric | Unpolarized capacitor, small symbol
C5, C10, C18, C21, C23, C28, C29, C31, C34, C62, C90, C118, C150, C151, C153, C154, | 16 | 10n | C_Small | Capacitor_SMD:C_0402_1005Metric | Unpolarized capacitor, small symbol
C6, C7, | 2 | 8p | C_Small | Capacitor_SMD:C_0402_1005Metric | Unpolarized capacitor, small symbol
C8, C9, | 2 | 22p | C_Small | Capacitor_SMD:C_0402_1005Metric | Unpolarized capacitor, small symbol
C11, C12, C147, | 3 | 22u | C_Small | Capacitor_SMD:C_0603_1608Metric | Unpolarized capacitor, small symbol
C13, C16, C19, C20, C24, C25, C26, C30, C36, C37, C38, C41, C44, C45, C46, C47, C48, C49, C50, C51, C53, C54, C56, C57, C64, C65, C66, C69, C72, C73, C74, C75, C76, C77, C78, C79, C81, C82, C84, C85, C92, C93, C94, C97, C100, C101, C102, C103, C104, C105, C106, C107, C109, C110, C112, C113, C120, C121, C122, C125, C128, C129, C130, C131, C132, C133, C134, C135, C137, C138, C140, C141, C144, C148, C149, C152, | 76 | 0u1 | C_Small | Capacitor_SMD:C_0402_1005Metric | Unpolarized capacitor, small symbol
C14, | 1 | 4u7 | C_Small | Capacitor_SMD:C_0603_1608Metric | Unpolarized capacitor, small symbol
C15, C17, C22, | 3 | 47p | C_Small | Capacitor_SMD:C_0402_1005Metric | Unpolarized capacitor, small symbol
C27, | 1 | 2u2 | C_Small | Capacitor_SMD:C_0603_1608Metric | Unpolarized capacitor, small symbol
C32, C60, C88, C116, | 4 | 1p2 | C_Small | Capacitor_SMD:C_0402_1005Metric | Unpolarized capacitor, small symbol
C33, C61, C89, C117, | 4 | 47u | C_Small | Capacitor_SMD:C_0603_1608Metric | Unpolarized capacitor, small symbol
C35, C63, C91, C119, | 4 | 27p | C_Small | Capacitor_SMD:C_0402_1005Metric | Unpolarized capacitor, small symbol
C39, C52, C67, C80, C95, C108, C123, C136, | 8 | 10p | C_Small | Capacitor_SMD:C_0402_1005Metric | Unpolarized capacitor, small symbol
C40, C68, C96, C124, | 4 | 18p | C_Small | Capacitor_SMD:C_0402_1005Metric | Unpolarized capacitor, small symbol
C42, C70, C98, C126, | 4 | 820p | C_Small | Capacitor_SMD:C_0402_1005Metric | Unpolarized capacitor, small symbol
C43, C55, C71, C83, C99, C111, C127, C139, | 8 | 330p | C_Small | Capacitor_SMD:C_0402_1005Metric | Unpolarized capacitor, small symbol
C58, C59, C86, C87, C114, C115, C142, C143, | 8 | 12p | C_Small | Capacitor_SMD:C_0402_1005Metric | Unpolarized capacitor, small symbol
C145, | 1 | 0n1 | C_Small | Capacitor_SMD:C_0402_1005Metric | Unpolarized capacitor, small symbol
C146, | 1 | 1n | C_Small | Capacitor_SMD:C_0402_1005Metric | Unpolarized capacitor, small symbol
D1, D2, D3, D4, D9, D11, D13, D15, | 8 | LED_G | LED_Small | LED_SMD:LED_0603_1608Metric | Light emitting diode, small symbol
D5, D6, D20, D21, | 4 | PESD3V3L4UF | PESD3V3L4UF | Package_TO_SOT_SMD:SOT-886 | Low capacitance unidirectional quadruple ESD protection diode array, 3.3V, Common Anode, SOT-886
D7, | 1 | LED_ABGR | LED_ABGR | LED_SMD:LED_Cree-PLCC4_2x2mm_CW | RGB LED, anode/blue/green/red
D8, | 1 | LED_R | LED_Small | LED_SMD:LED_0603_1608Metric | Light emitting diode, small symbol
D10, D12, D14, D16, | 4 | LED_Y | LED_Small | LED_SMD:LED_0603_1608Metric | Light emitting diode, small symbol
D17, D19, | 2 | D_Schottky | D_Schottky | Diode_SMD:D_SOD-123F | Schottky diode
D18, | 1 | PRTR5V0U2X | PRTR5V0U2X | Package_TO_SOT_SMD:SOT-143 | Ultra low capacitance double rail-to-rail ESD protection diode, SOT-143
FID1, FID2, FID3, FID4, FID5, FID6, FID7, FID8, | 8 | Fiducial | Fiducial | Fiducial:Fiducial_0.75mm_Mask1.5mm | Fiducial Marker
H1, H2, H3, H4, | 4 | MountingHole | MountingHole | MountingHole:MountingHole_2.2mm_M2_Pad_Via | Mounting Hole without connection
H5, H6, | 2 | MountingHole | MountingHole | MountingHole:MountingHole_2.2mm_M2_Pad | Mounting Hole without connection
J1, | 1 | TC2050 | Conn_02x05_Odd_Even | Tag-Connect:TC2050-IDC-NL | Generic connector, double row, 02x05, odd/even pin numbering scheme (row 1 odd numbers, row 2 even numbers), script generated (kicad-library-utils/schlib/autogen/connector/)
J2, | 1 | TC2030 | Conn_02x03_Counter_Clockwise | Tag-Connect:TC2030-IDC-NL | Generic connector, double row, 02x03, counter clockwise pin numbering scheme (similar to DIP package numbering), script generated (kicad-library-utils/schlib/autogen/connector/)
J3, J4, J5, J6, | 4 | Uf.l | Conn_Coaxial | Connector_Coaxial:U.FL_Hirose_U.FL-R-SMT-1_Vertical | coaxial connector (BNC, SMA, SMB, SMC, Cinch/RCA, LEMO, ...)
J7, | 1 | USB_C_Receptacle_USB2.0 | USB_C_Receptacle_USB2.0 | Connector_USB:USB_C_Receptacle_XKB_U262-16XN-4BVC11 | USB 2.0-only Type-C Receptacle connector
J8, | 1 | JST_SH_SM08B | Conn_01x08 | Connector_JST:JST_SH_SM08B-SRSS-TB_1x08-1MP_P1.00mm_Horizontal | Generic connector, single row, 01x08, script generated (kicad-library-utils/schlib/autogen/connector/)
L1, L2, | 2 | Ferrite | L_Small | Inductor_SMD:L_0402_1005Metric_Pad0.77x0.64mm_HandSolder | Inductor, small symbol
L3, | 1 | 4.7u | L_Small | Inductor_SMD:L_0603_1608Metric | Inductor, small symbol
R1, R2, R12, R13, R37, R41, R43, R44, R49, R51, R52, R57, R59, R60, R65, R67, R68, | 17 | 270R | R_Small | Resistor_SMD:R_0402_1005Metric | Resistor, small symbol
R3, R4, R5, R6, R7, R8, R9, R10, R11, R14, R15, R16, R17, R18, R19, R20, R21, R22, R24, | 19 | 0R | R_Small | Resistor_SMD:R_0402_1005Metric | Resistor, small symbol
R23, | 1 | 2k2 | R_Small | Resistor_SMD:R_0402_1005Metric | Resistor, small symbol
R25, | 1 | 280R | R_Small | Resistor_SMD:R_0402_1005Metric | Resistor, small symbol
R26, | 1 | 80R | R_Small | Resistor_SMD:R_0402_1005Metric | Resistor, small symbol
R27, R28, R29, R38, R46, R54, R62, R76, R77, | 9 | 10K | R_Small | Resistor_SMD:R_0402_1005Metric | Resistor, small symbol
R30, | 1 | 60R | R_Small | Resistor_SMD:R_0402_1005Metric | Resistor, small symbol
R31, | 1 | 100R | R_Small | Resistor_SMD:R_0402_1005Metric | Resistor, small symbol
R32, R74, R75, | 3 | 100K | R_Small | Resistor_SMD:R_0402_1005Metric | Resistor, small symbol
R33, | 1 | 55K | R_Small | Resistor_SMD:R_0402_1005Metric | Resistor, small symbol
R34, | 1 | 62K | R_Small | Resistor_SMD:R_0402_1005Metric | Resistor, small symbol
R35, | 1 | 75K | R_Small | Resistor_SMD:R_0402_1005Metric | Resistor, small symbol
R36, | 1 | 24K | R_Small | Resistor_SMD:R_0402_1005Metric | Resistor, small symbol
R39, R47, R55, R63, | 4 | 16k | R_Small | Resistor_SMD:R_0402_1005Metric | Resistor, small symbol
R40, R45, R48, R53, R56, R61, R64, R69, | 8 | 10K DNP | R_Small | Resistor_SMD:R_0402_1005Metric | Resistor, small symbol
R42, R50, R58, R66, | 4 | 11K 1% | R_Small | Resistor_SMD:R_0402_1005Metric | Resistor, small symbol
R70, R71, | 2 | 5.1K | R_Small | Resistor_SMD:R_0402_1005Metric | Resistor, small symbol
R72, R73, | 2 | 33R | R_Small | Resistor_SMD:R_0402_1005Metric | Resistor, small symbol
R78, R79, R80, R81, R82, | 5 | 30R | R_Small | Resistor_SMD:R_0402_1005Metric | Resistor, small symbol
R83, R84, R85, R86, R87, | 5 | 0R DNP | R_Small | Capacitor_SMD:C_0805_2012Metric | Resistor, small symbol
SW1, SW2, | 2 | SW_Push | SW_Push | Button_Switch_SMD:Panasonic_EVQPUL_EVQPUC | Push button switch, generic, two pins
SW3, | 1 | SW_SPDT | SW_SPDT | Button_Switch_SMD:SW_SPDT_PCM12 | Switch, single pole double throw
TP1, TP2, TP3, TP4, TP5, TP6, TP7, TP8, TP9, TP10, TP11, TP12, TP13, TP14, TP15, TP16, TP17, TP18, TP19, TP20, TP21, TP22, TP23, TP24, TP25, TP26, TP27, TP28, TP29, TP30, TP31, TP32, | 32 | TestPoint | TestPoint | TestPoint:TestPoint_Pad_D1.0mm | test point
U1, | 1 | LPC55S69JBD100 | LPC55S69JBD100 | Package_QFP_U:HLQFP-100_14x14mm_P0.5mm | ARM Cortex-M33 based microcontroller for embedded applications. 320 KB of on-chip SRAM, 640 KB on-chip flash.
U2, | 1 | MPM3610 | MPM3610 | Package_DFN_QFN_U:MPM3610_QFN-20_5x3mm | 4.5 - 21V Buck Converter with integrated inductor and capacitors
U3, U5, U7, U9, | 4 | DW1000 | DW1000 | Package_DFN_QFN:QFN-48-1EP_6x6mm_P0.4mm_EP4.2x4.2mm_ThermalVias | fully integrated single chip Ultra Wideband (UWB) low-power low-cost transceiver IC compliant to IEEE802.15.4-2011
U4, U6, U8, U10, | 4 | HHM1595A1 | HHM1595A1 | RF_U:HHM1595A1
U11, | 1 | ATX-13 | ATX-13 | Oscillator_U:Oscillator_SMD_Abracon_ATX13-4Pin_2.0x1.6mm
U12, | 1 | SN74AUP1G74RSER | SN74AUP1G74RSER | Package_DFN_QFN_U:UQFN-8-1.55x1.55mm_P0.5mm
U13, U14, | 2 | PL133-37 | PL133-37 | Package_TO_SOT_SMD:SOT-23-6 | Low-Power, 1.62V to 3.63V, 1 MHz to 150 MHz, Inverting 1:3 Fanout Buffer IC
Y1, | 1 | 16MHz | Crystal_Small | Crystal_U:Crystal_SMD_Kyocera_CX3225G-2Pin_3.2x2.5mm | Two pin crystal, small symbol
Y2, | 1 | 32.768kHz | Crystal_Small | Crystal:Crystal_SMD_2012-2Pin_2.0x1.2mm | Two pin crystal, small symbol

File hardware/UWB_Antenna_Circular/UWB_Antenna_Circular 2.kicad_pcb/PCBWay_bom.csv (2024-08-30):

designator | quantity | value | pack | mpn | mount_type
TP1, TP2 | 2 | TestPoint | TestPoint_Pad_2.0x2.0mm |  | tht
TP3 | 1 | TestPoint | TestPoint_Pad_1.0x1.0mm |  | tht
kibuzzard-66101274 | 1 | G*** | kibuzzard-66101274 |  | tht

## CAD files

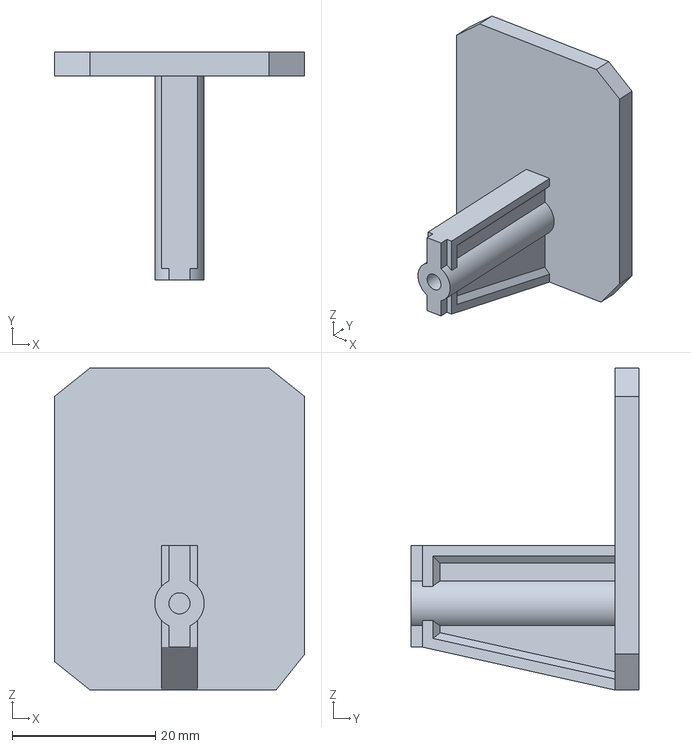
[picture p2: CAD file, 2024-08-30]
hardware/3D Parts/ReLoki_RTA_AntennaTopHolder.3mf
35.0 x 31.9 x 45.0 mm

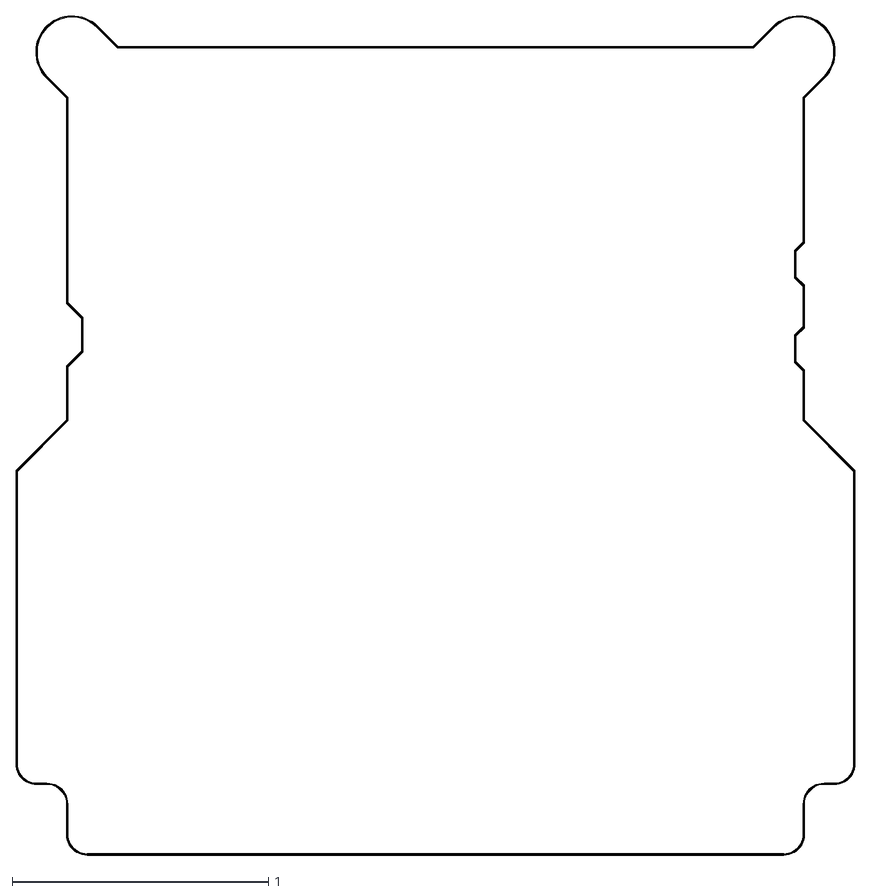
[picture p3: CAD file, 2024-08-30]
hardware/ReLoki_ECAD/FreeCad_OP/ReLoki_ECAD-Edge_Cuts.dxf
3.27 x 3.27

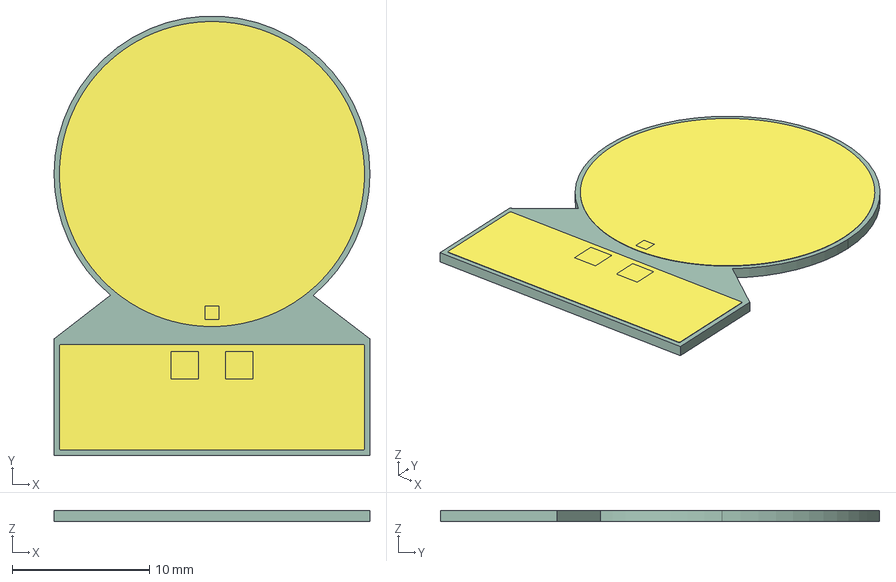
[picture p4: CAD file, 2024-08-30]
hardware/UWB_Antenna_Circular/UWB_Antenna_Circular.step
23.0 x 32.0 x 0.835 mm
UWB_Antenna_Circular_track_1
UWB_Antenna_Circular_track_2
UWB_Antenna_Circular_pad_1
UWB_Antenna_Circular_pad_2
UWB_Antenna_Circular_pad_3
UWB_Antenna_Circular_PCB

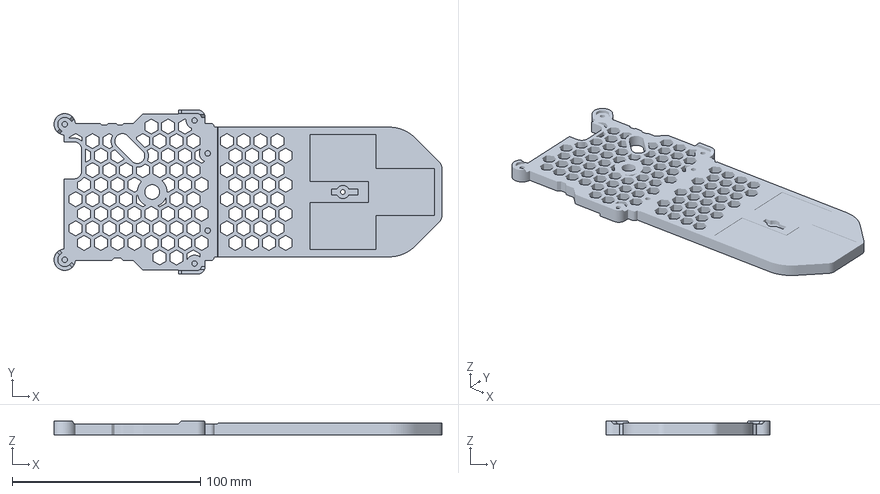
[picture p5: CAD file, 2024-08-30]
hardware/3D Parts/ReLoki_RTA_AntennaBase.3mf
206.2 x 87.3 x 7.60 mm

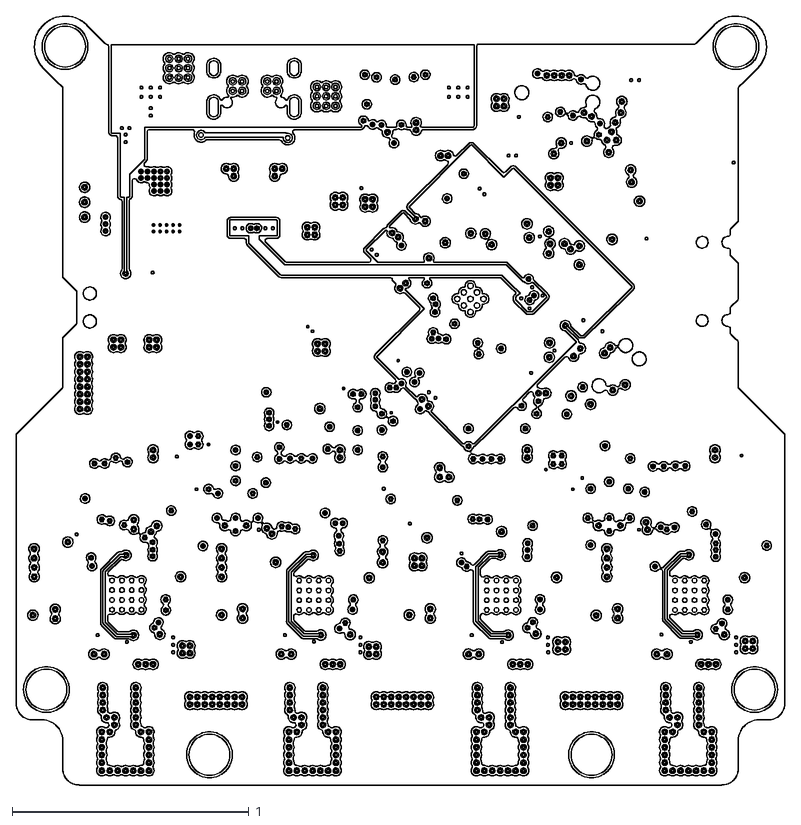
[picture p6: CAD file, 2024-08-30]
hardware/ReLoki_ECAD/FreeCad_OP/ReLoki_ECAD-In2_Cu.dxf
3.25 x 3.25

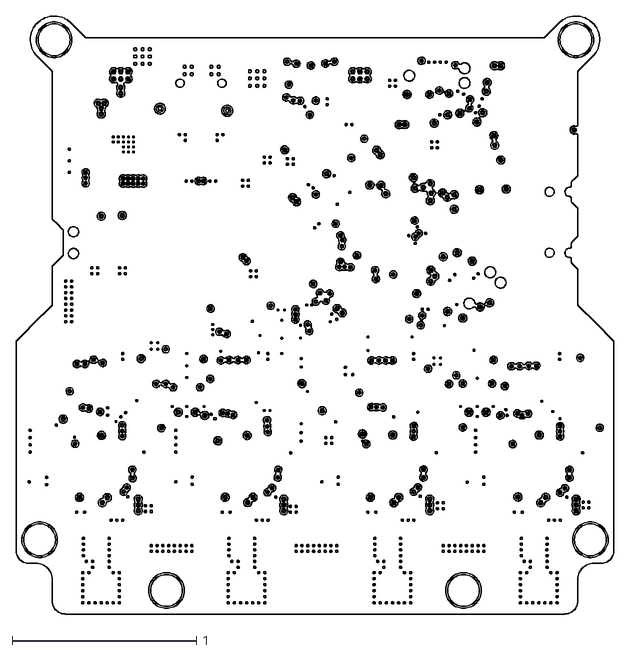
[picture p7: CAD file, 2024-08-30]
hardware/ReLoki_ECAD/FreeCad_OP/ReLoki_ECAD-In1_Cu.dxf
3.25 x 3.25

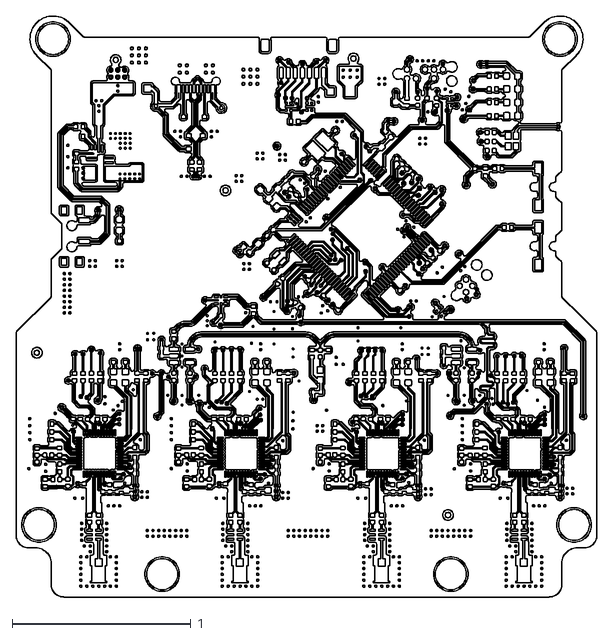
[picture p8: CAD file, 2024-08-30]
hardware/ReLoki_ECAD/FreeCad_OP/ReLoki_ECAD-F_Cu.dxf
3.25 x 3.25

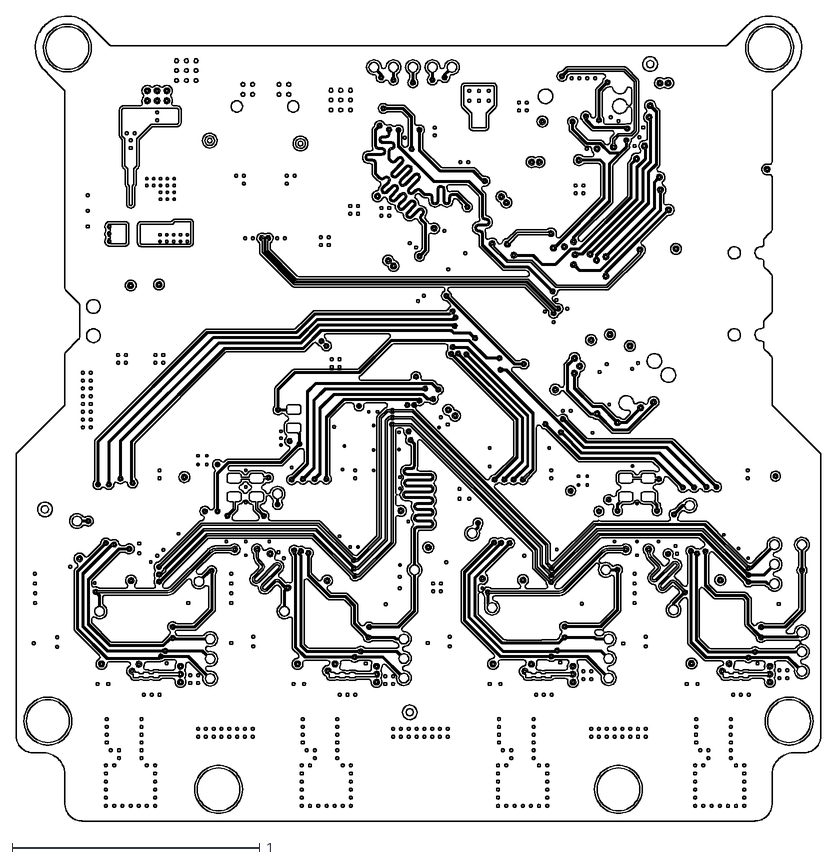
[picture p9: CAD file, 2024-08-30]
hardware/ReLoki_ECAD/FreeCad_OP/ReLoki_ECAD-B_Cu.dxf
3.25 x 3.25

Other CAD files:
hardware/ReLoki_ECAD/FreeCad_OP/ReLoki_ECAD-B_Mask.dxf
hardware/ReLoki_ECAD/FreeCad_OP/ReLoki_ECAD-B_Paste.dxf
hardware/ReLoki_ECAD/FreeCad_OP/ReLoki_ECAD-B_Silkscreen.dxf
hardware/ReLoki_ECAD/FreeCad_OP/ReLoki_ECAD-F_Mask.dxf
hardware/ReLoki_ECAD/FreeCad_OP/ReLoki_ECAD-F_Paste.dxf
hardware/ReLoki_ECAD/FreeCad_OP/ReLoki_ECAD-F_Silkscreen.dxf

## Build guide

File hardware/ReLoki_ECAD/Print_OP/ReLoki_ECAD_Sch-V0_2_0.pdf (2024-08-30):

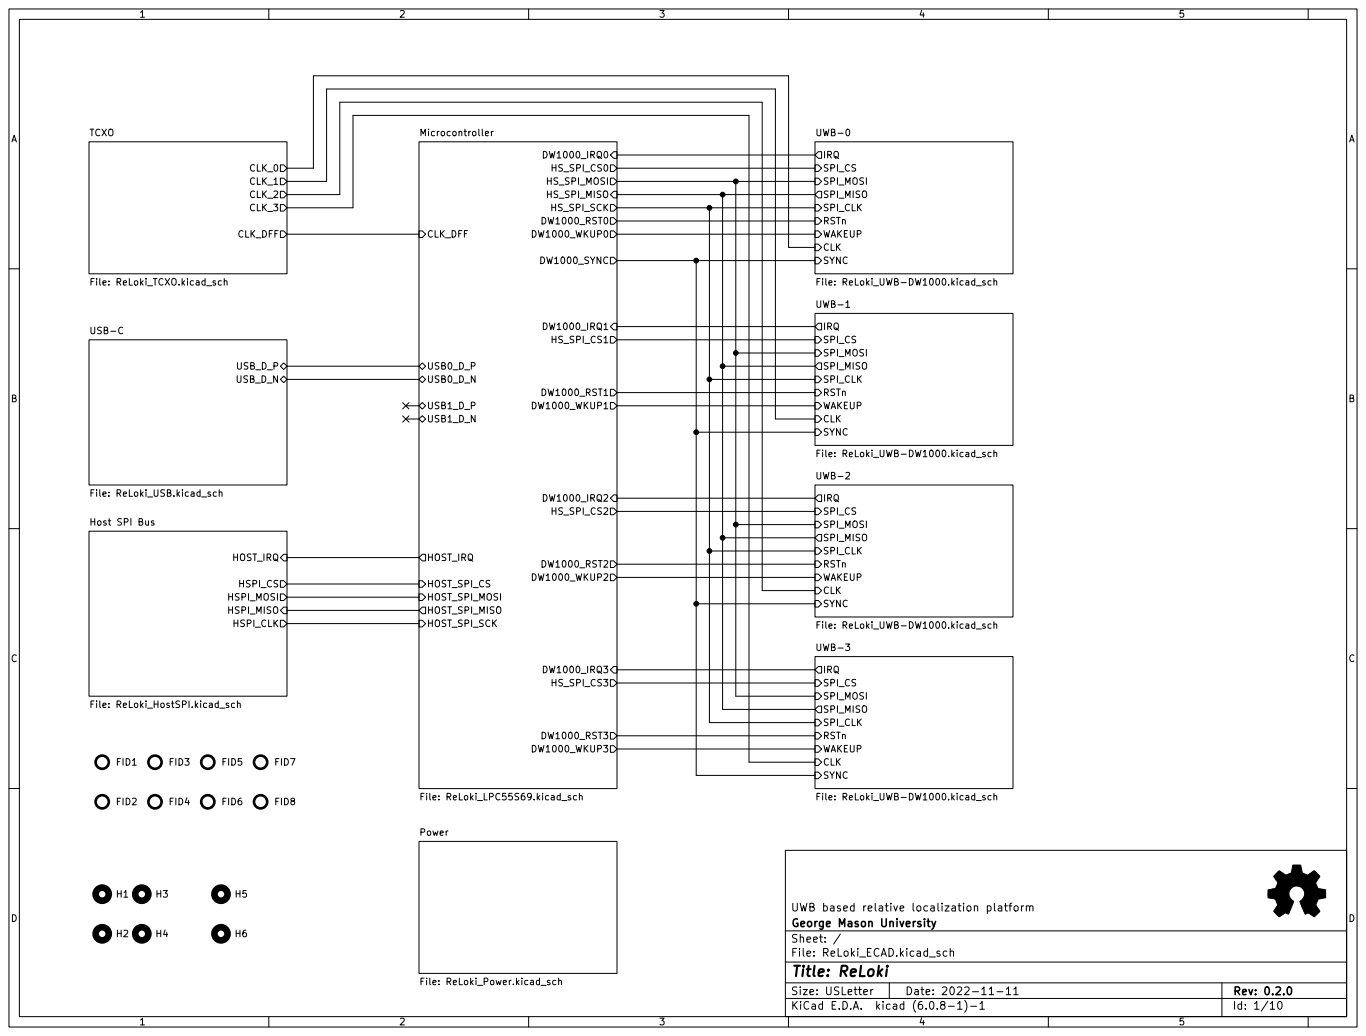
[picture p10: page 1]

IRQ
SPI_CS CLK RSTn SYNC WAKEUP

SPI_MOSI UWB-2 File: ReLoki_UWB-DW1000.kicad_sch

Host SPI Bus File: ReLoki_HostSPI.kicad_sch

SPI_MOSI UWB-3 File: ReLoki_UWB-DW1000.kicad_sch

UWB based relative localization platform
File: ReLoki_ECAD.kicad_sch Sheet: / George Mason University

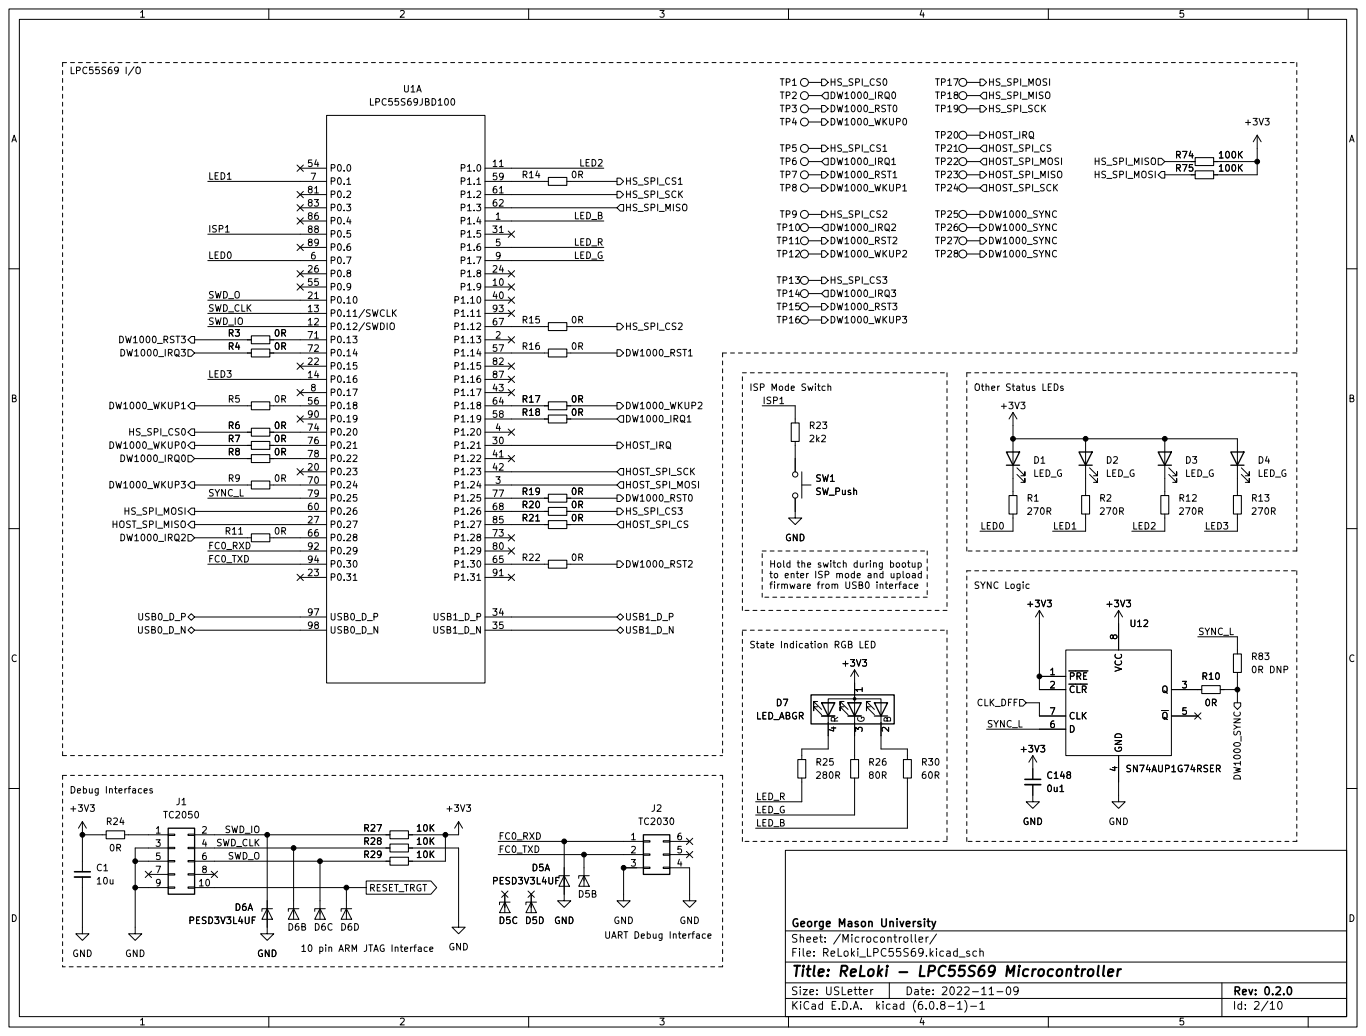
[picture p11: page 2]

Hold the switch during bootup
to enter ISP mode and upload
firmware from USB0 interface State Indication RGB LED

5 | | SWD_O 6

9 | PESD3V3L4UF GND | | 10 pin ARM JTAG Interface

File: ReLoki_LPC55S69.kicad_sch Sheet: /Microcontroller/ George Mason University

Id: 2/10 Title: ReLoki - LPC55S69 Microcontroller

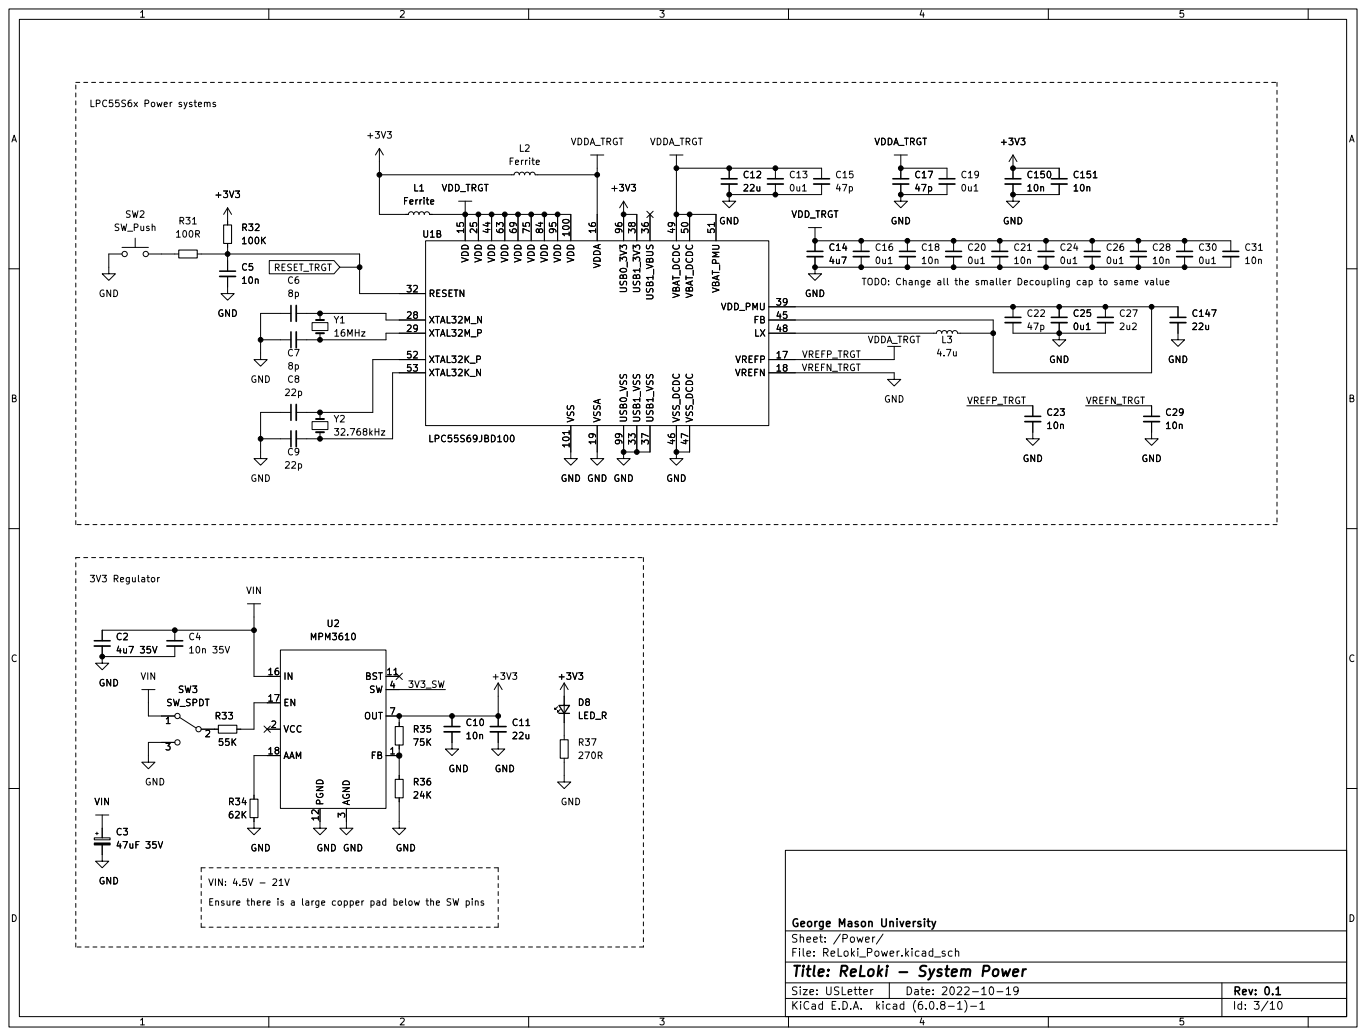
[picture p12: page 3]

TODO: Change all the smaller Decoupling cap to same value

3 SW 4 OUT 7 U2 MPM3610 GND GND GND

Ensure there is a large copper pad below the SW pins VIN: 4.5V - 21V

File: ReLoki_Power.kicad_sch Sheet: /Power/ George Mason University

Id: 3/10 Title: ReLoki - System Power

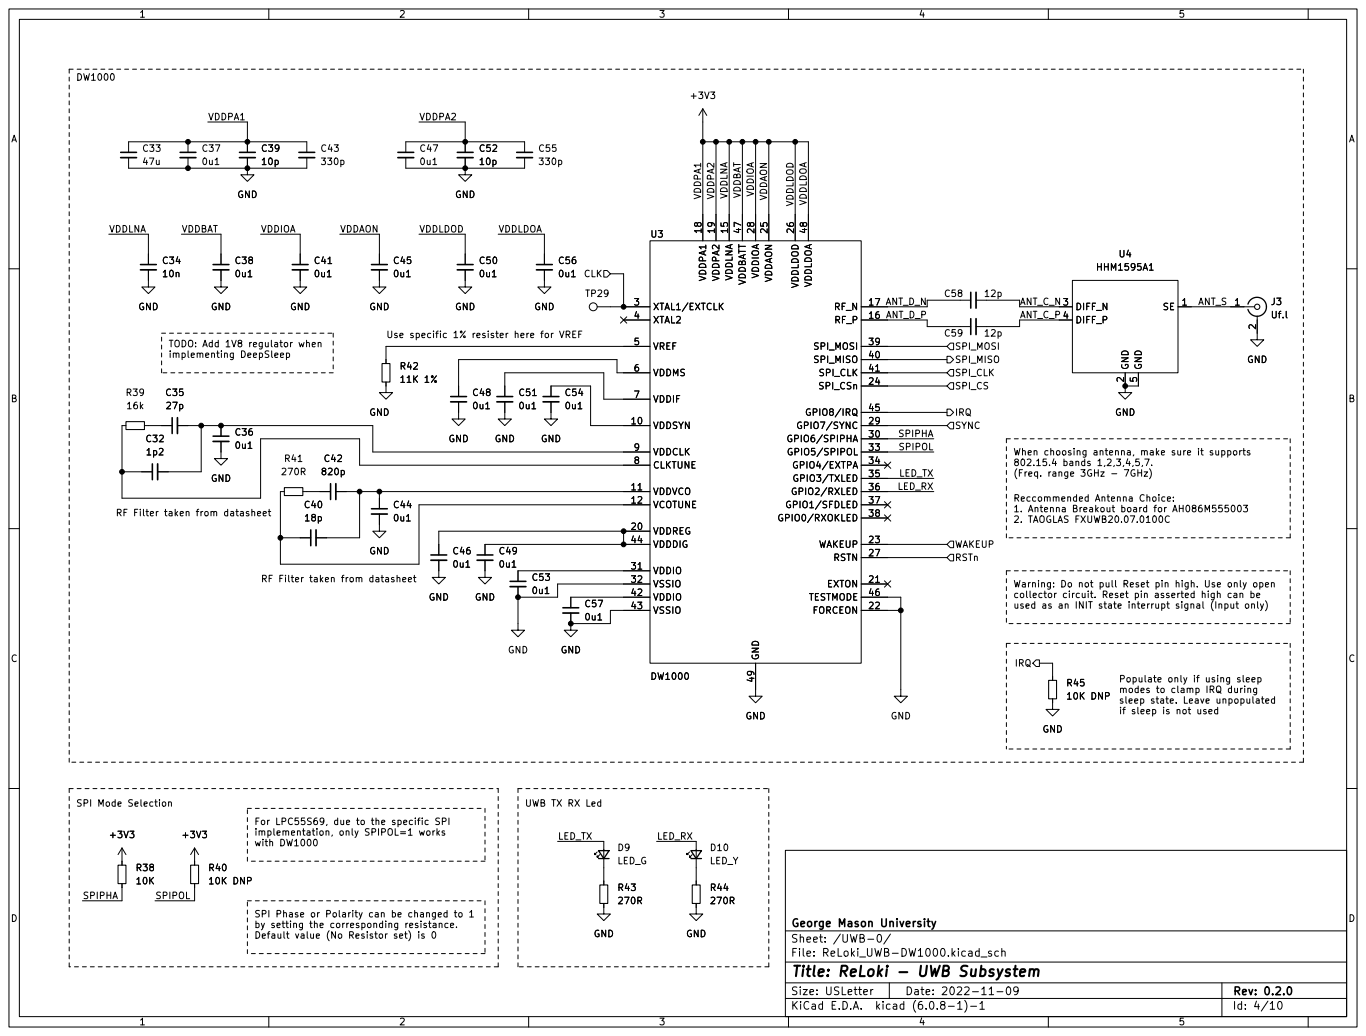
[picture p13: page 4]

Use specific 1% resister here for VREF UWB TX RX Led For LPC55S69, due to the specific SPI

TODO: Add 1V8 regulator when

When choosing antenna, make sure it supports 802.15.4 bands 1,2,3,4,5,7. (Freq. range 3GHz - 7GHz) C57

collector circuit. Reset pin asserted high can be
used as an INIT state interrupt signal (Input only)

modes to clamp IRQ during
sleep state. Leave unpopulated

implementation, only SPIPOL=1 works with DW1000

SPI Phase or Polarity can be changed to 1
by setting the corresponding resistance.
Default value (No Resistor set) is 0

File: ReLoki_UWB-DW1000.kicad_sch Sheet: /UWB-0/ George Mason University

Id: 4/10 Title: ReLoki - UWB Subsystem

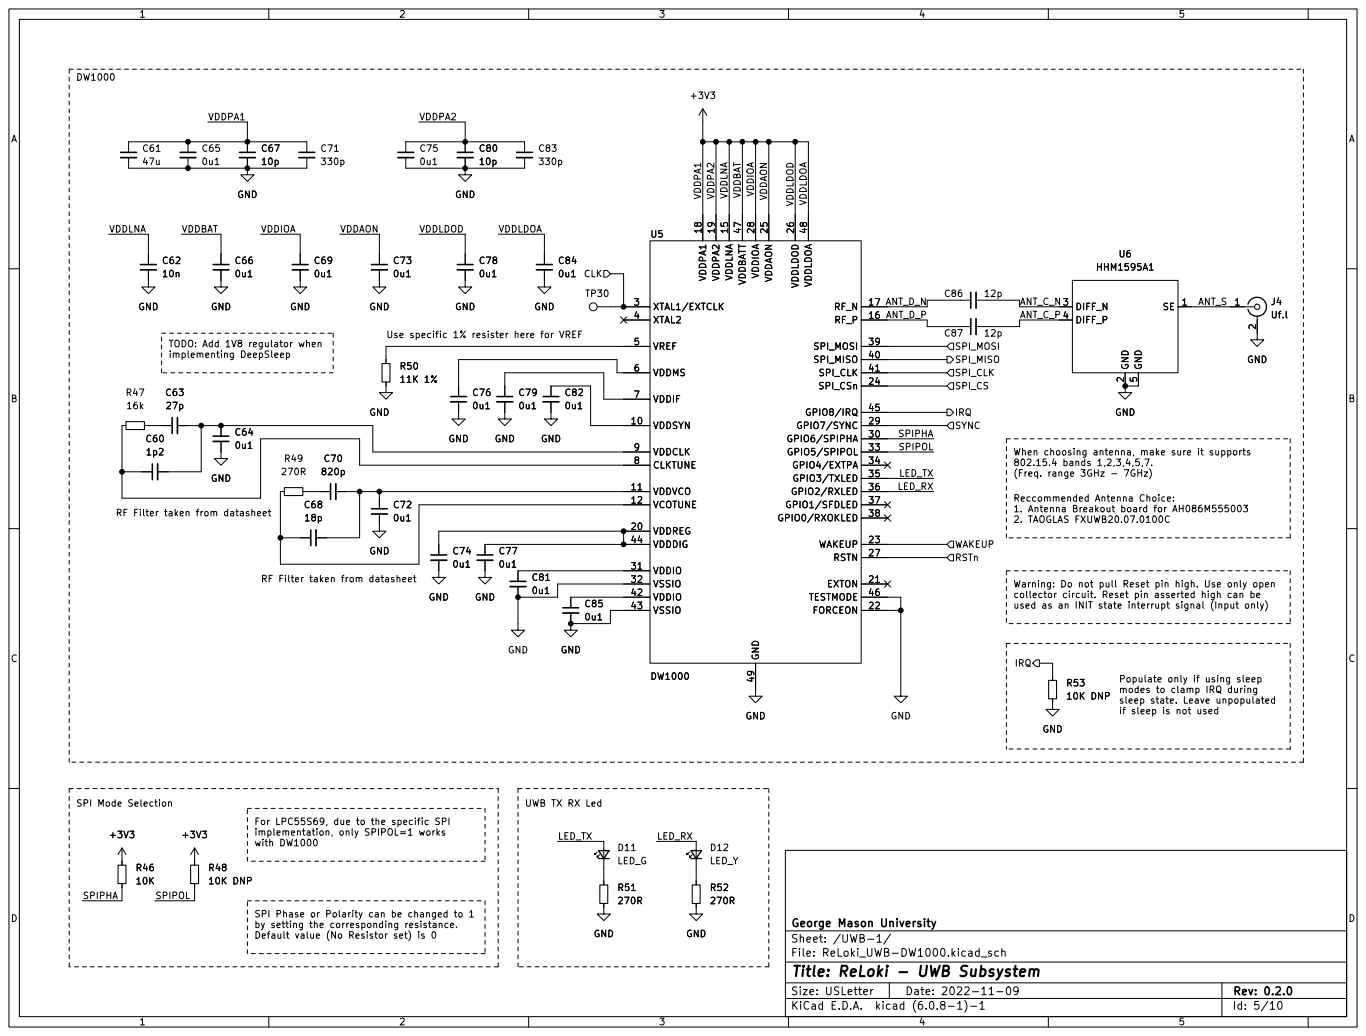
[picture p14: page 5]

Use specific 1% resister here for VREF UWB TX RX Led For LPC55S69, due to the specific SPI

When choosing antenna, make sure it supports 802.15.4 bands 1,2,3,4,5,7. (Freq. range 3GHz - 7GHz)

if sleep is not used RF Filter taken from datasheet

Warning: Do not pull Reset pin high. Use only open
collector circuit. Reset pin asserted high can be
used as an INIT state interrupt signal (Input only)

Populate only if using sleep
modes to clamp IRQ during
sleep state. Leave unpopulated

implementation, only SPIPOL=1 works with DW1000

SPI Phase or Polarity can be changed to 1
by setting the corresponding resistance.
Default value (No Resistor set) is 0

File: ReLoki_UWB-DW1000.kicad_sch Sheet: /UWB-1/ George Mason University

Id: 5/10 Title: ReLoki - UWB Subsystem

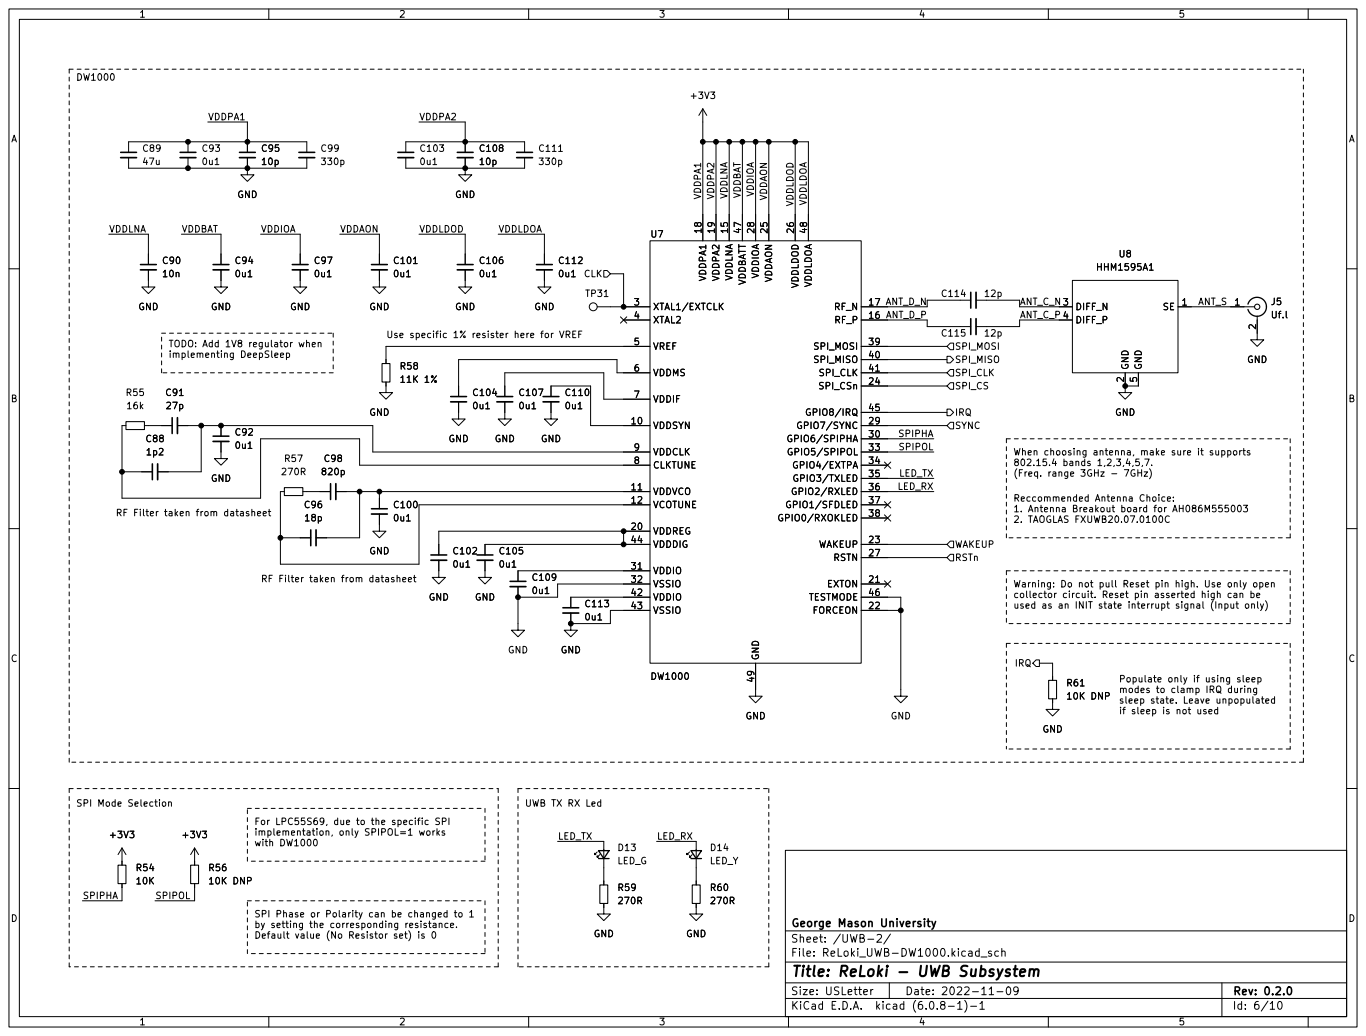
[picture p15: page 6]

Use specific 1% resister here for VREF UWB TX RX Led For LPC55S69, due to the specific SPI

When choosing antenna, make sure it supports 802.15.4 bands 1,2,3,4,5,7. (Freq. range 3GHz - 7GHz)

if sleep is not used RF Filter taken from datasheet

Warning: Do not pull Reset pin high. Use only open
collector circuit. Reset pin asserted high can be
used as an INIT state interrupt signal (Input only)

Populate only if using sleep
modes to clamp IRQ during
sleep state. Leave unpopulated

implementation, only SPIPOL=1 works with DW1000

SPI Phase or Polarity can be changed to 1
by setting the corresponding resistance.
Default value (No Resistor set) is 0

File: ReLoki_UWB-DW1000.kicad_sch Sheet: /UWB-2/ George Mason University

Id: 6/10 Title: ReLoki - UWB Subsystem

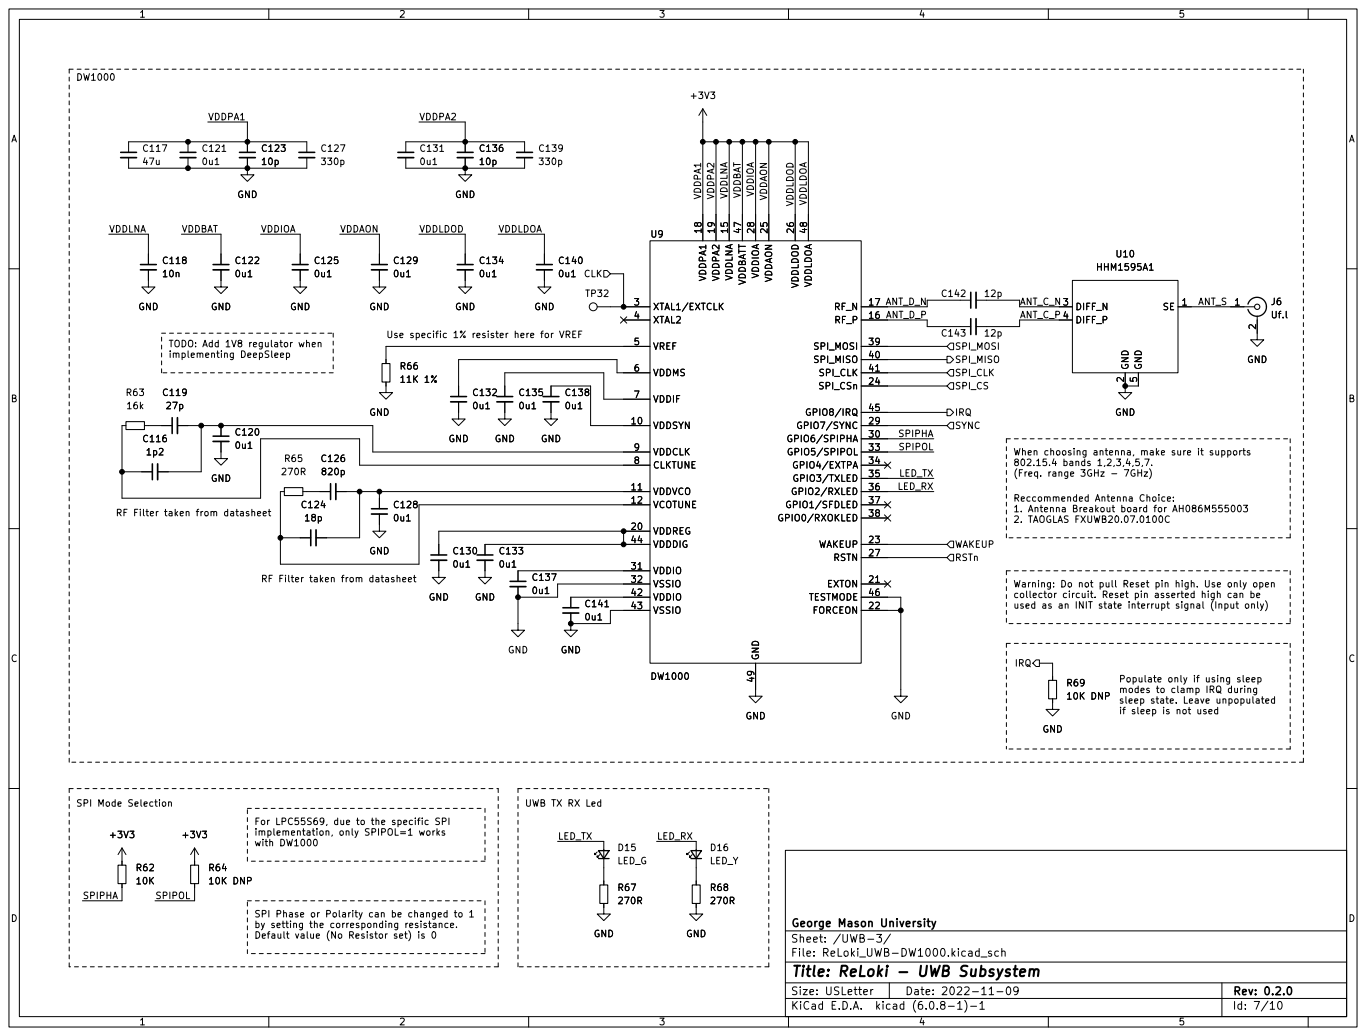
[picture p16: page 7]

Warning: Do not pull Reset pin high. Use only open
collector circuit. Reset pin asserted high can be
used as an INIT state interrupt signal (Input only)

Populate only if using sleep
modes to clamp IRQ during
sleep state. Leave unpopulated

implementation, only SPIPOL=1 works with DW1000 SPI Mode Selection

For LPC55S69, due to the specific SPI

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

File: ReLoki_UWB-DW1000.kicad_sch Sheet: /UWB-3/ George Mason University

Id: 7/10 Title: ReLoki - UWB Subsystem

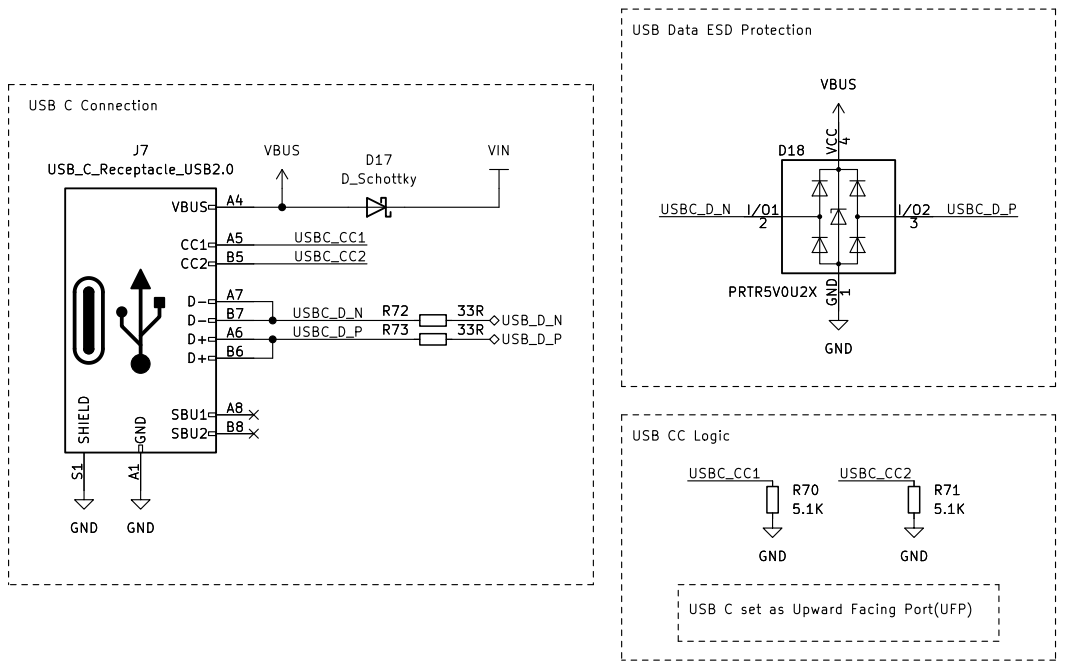
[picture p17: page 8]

3 VCC4 R70
File: ReLoki_USB.kicad_sch Sheet: /USB-C/ Geroge Mason University R70
5.1K GND

Id: 8/10 Title: ReLoki - USB Device Interface

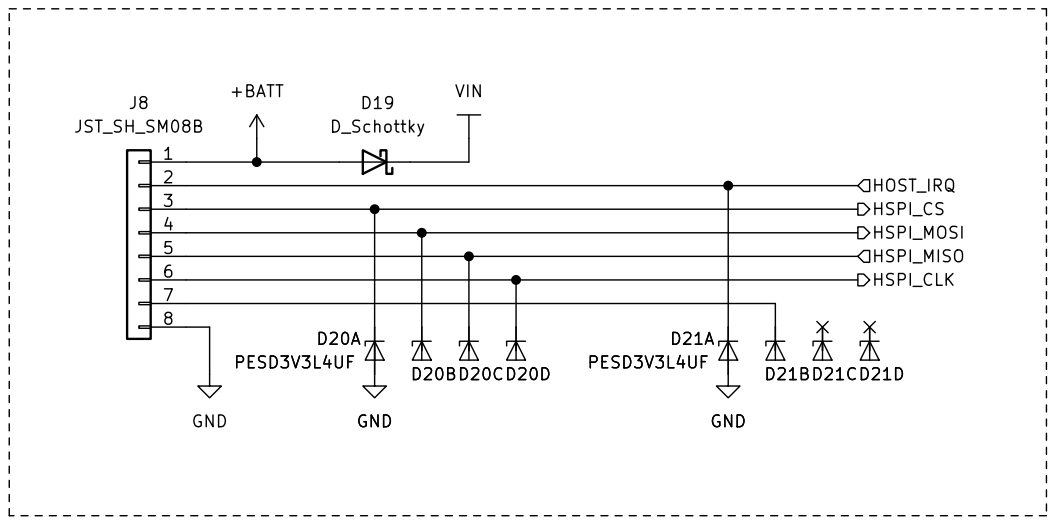
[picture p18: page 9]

5 | HSPI_CS D20A

7 | | | D21D GND
8 | | PESD3V3L4UF D20B D20C D20D | D21B D21C GND | D21D GND

File: ReLoki_HostSPI.kicad_sch Sheet: /Host SPI Bus/ George Mason University D20C

Id: 9/10 Title: ReLoki - Host SPI Slave Interface

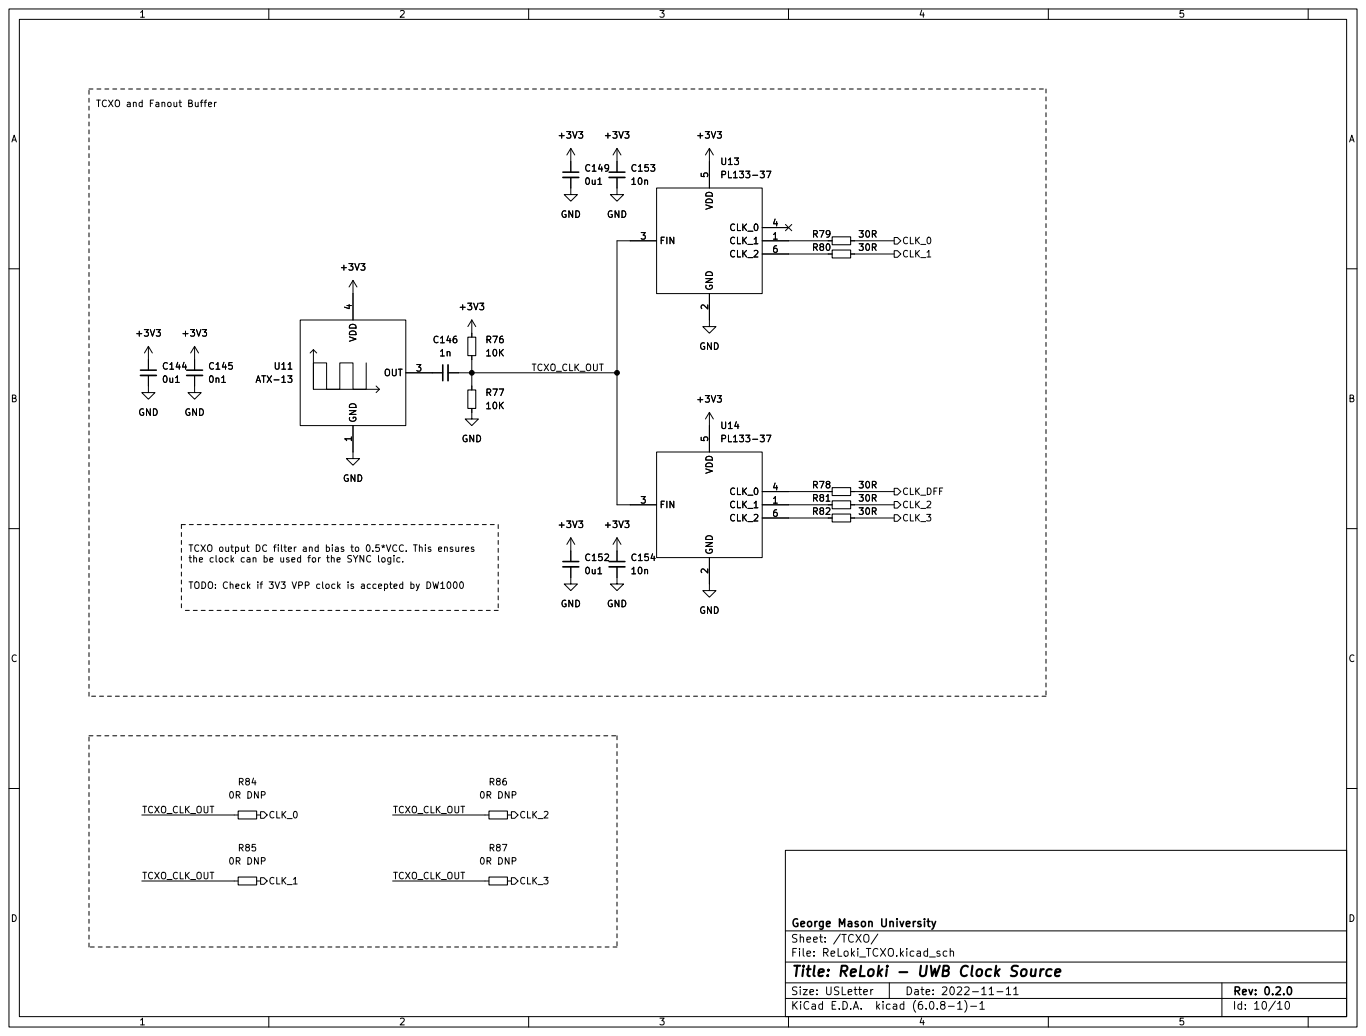
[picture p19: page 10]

TCXO output DC filter and bias to 0.5*VCC. This ensures
the clock can be used for the SYNC logic.

TODO: Check if 3V3 VPP clock is accepted by DW1000

File: ReLoki_TCXO.kicad_sch Sheet: /TCXO/ George Mason University

Id: 10/10 Title: ReLoki - UWB Clock Source

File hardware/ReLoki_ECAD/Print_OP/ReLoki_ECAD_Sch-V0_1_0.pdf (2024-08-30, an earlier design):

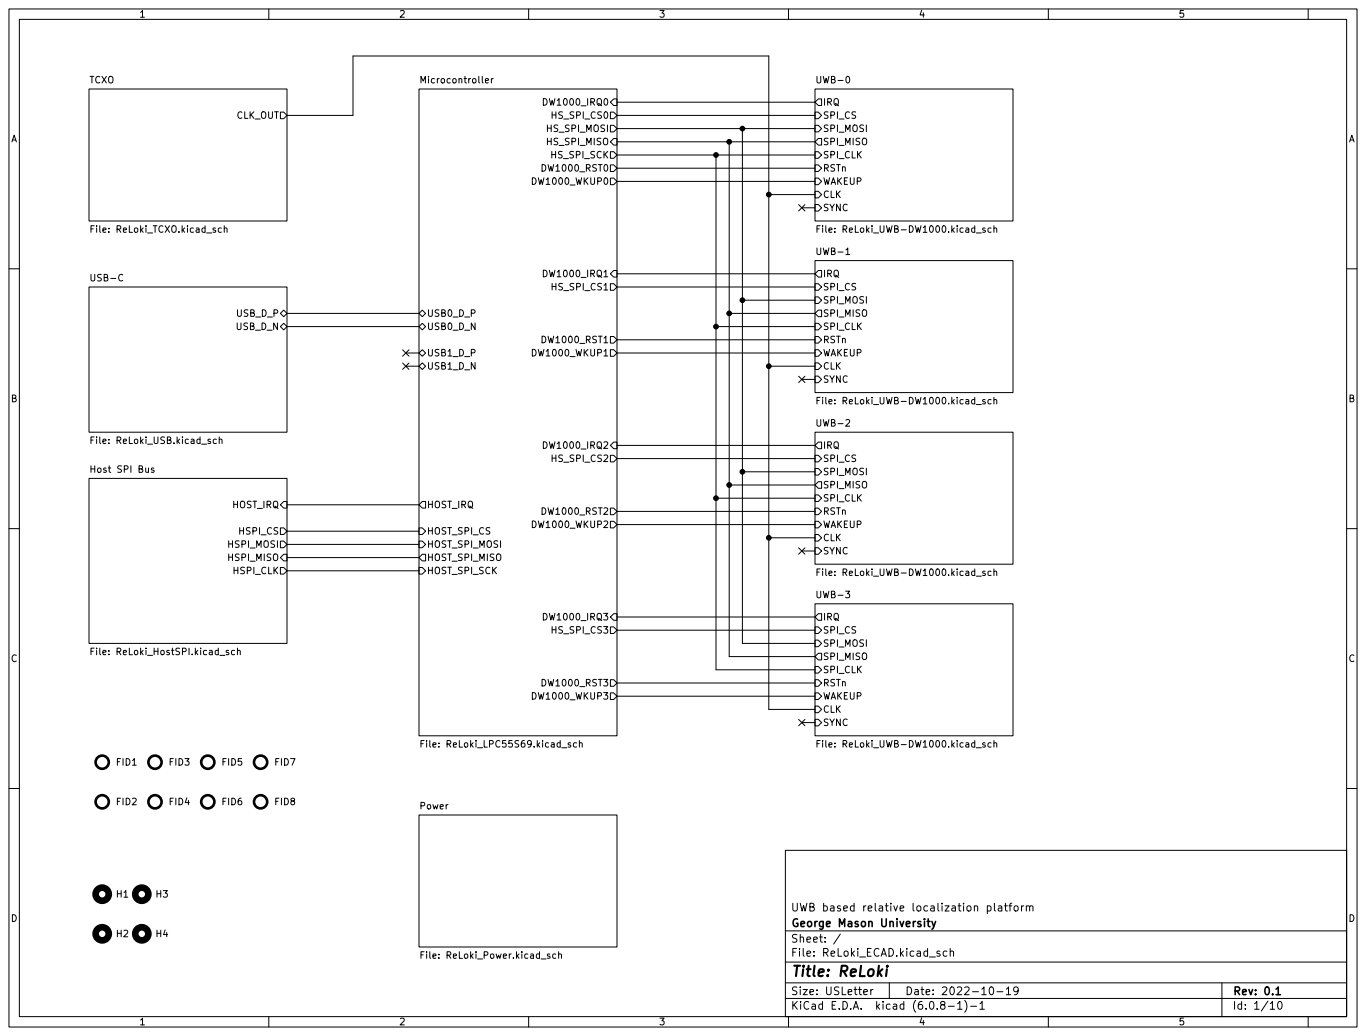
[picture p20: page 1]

UWB-0 File: ReLoki_UWB-DW1000.kicad_sch
SPI_CS CLK RSTn SYNC WAKEUP
SPI_MOSI SPI_MISO

IRQ

Host SPI Bus File: ReLoki_HostSPI.kicad_sch USB_D_P USB_D_N

SPI_MOSI UWB-2 File: ReLoki_UWB-DW1000.kicad_sch

SPI_MOSI UWB-3 File: ReLoki_UWB-DW1000.kicad_sch Power File: ReLoki_Power.kicad_sch

UWB based relative localization platform
File: ReLoki_ECAD.kicad_sch Sheet: / George Mason University

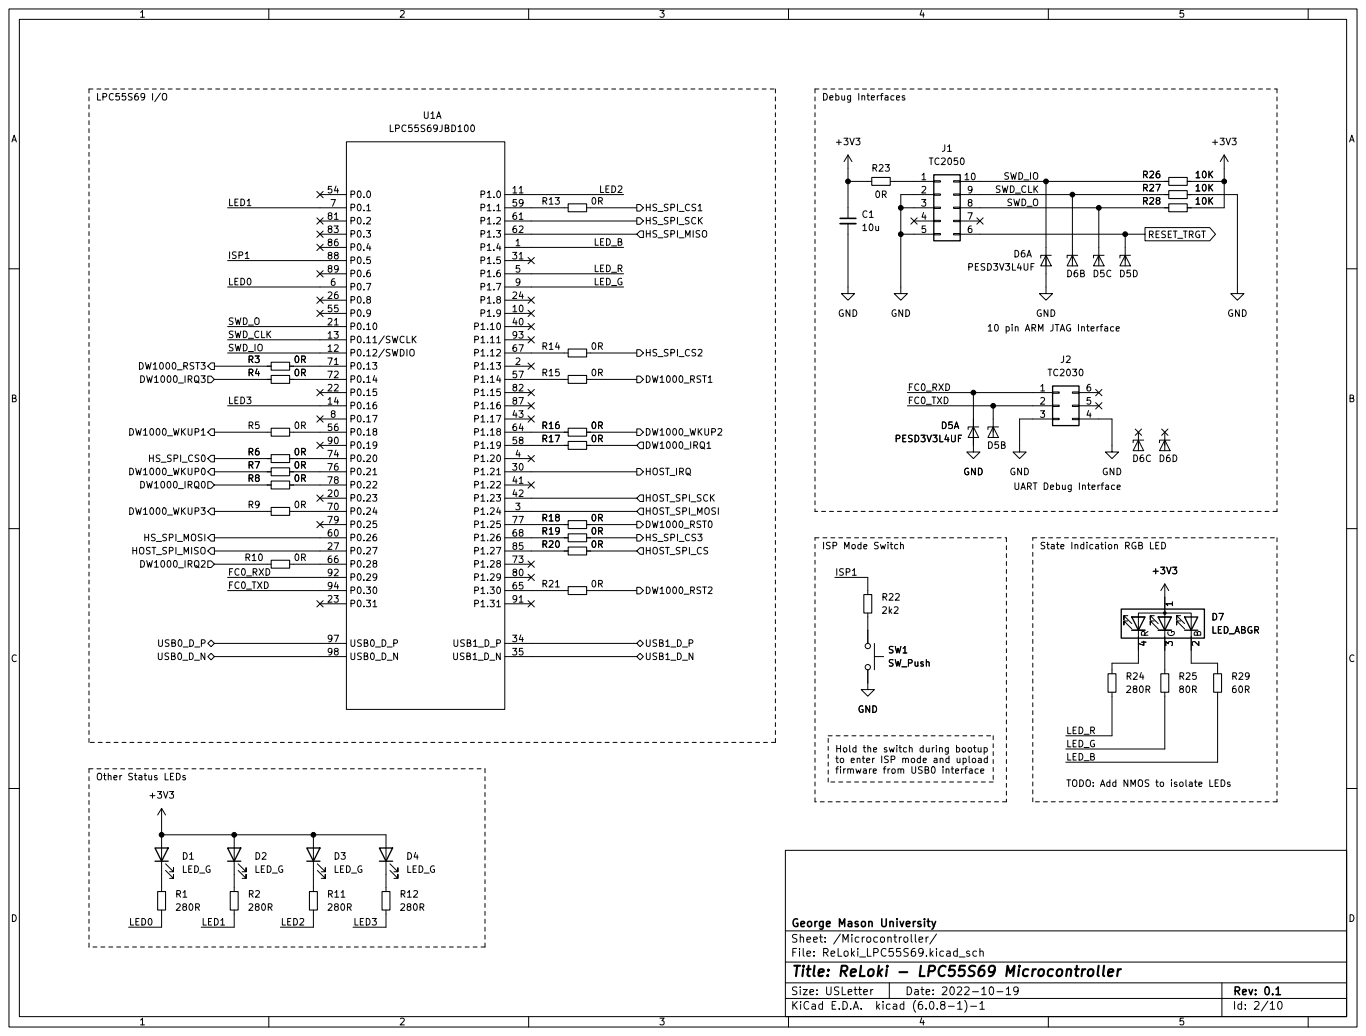
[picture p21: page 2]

Debug Interfaces Other Status LEDs

10 pin ARM JTAG Interface

Hold the switch during bootup
to enter ISP mode and upload

Id: 2/10 Title: ReLoki - LPC55S69 Microcontroller

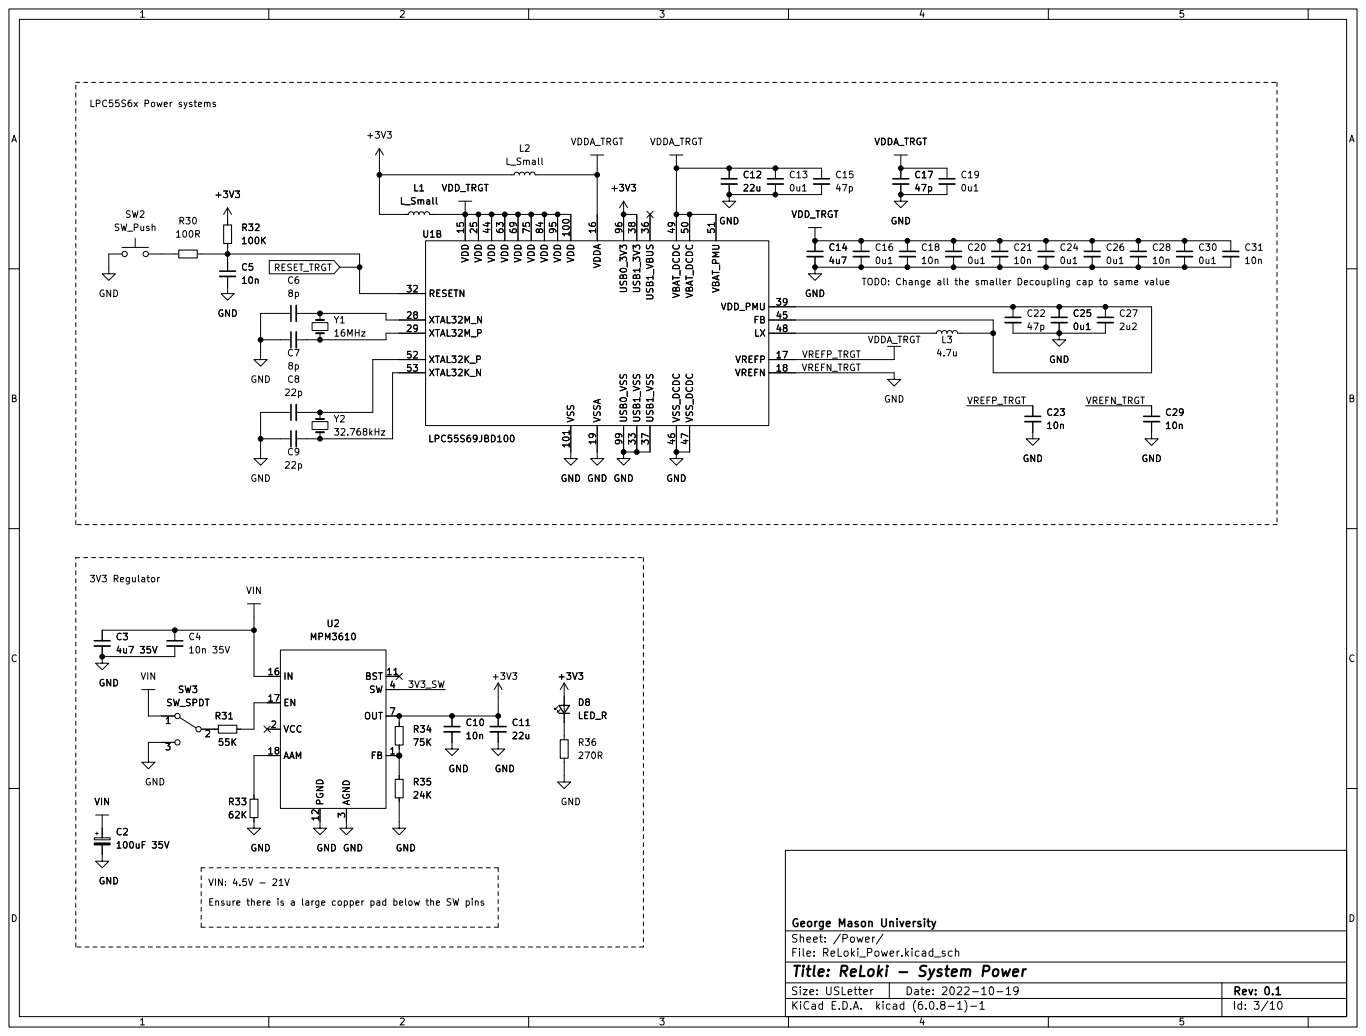
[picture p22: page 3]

TODO: Change all the smaller Decoupling cap to same value GND

File: ReLoki_Power.kicad_sch Sheet: /Power/ George Mason University VINGND

Ensure there is a large copper pad below the SW pins VIN: 4.5V - 21V

Id: 3/10 Title: ReLoki - System Power

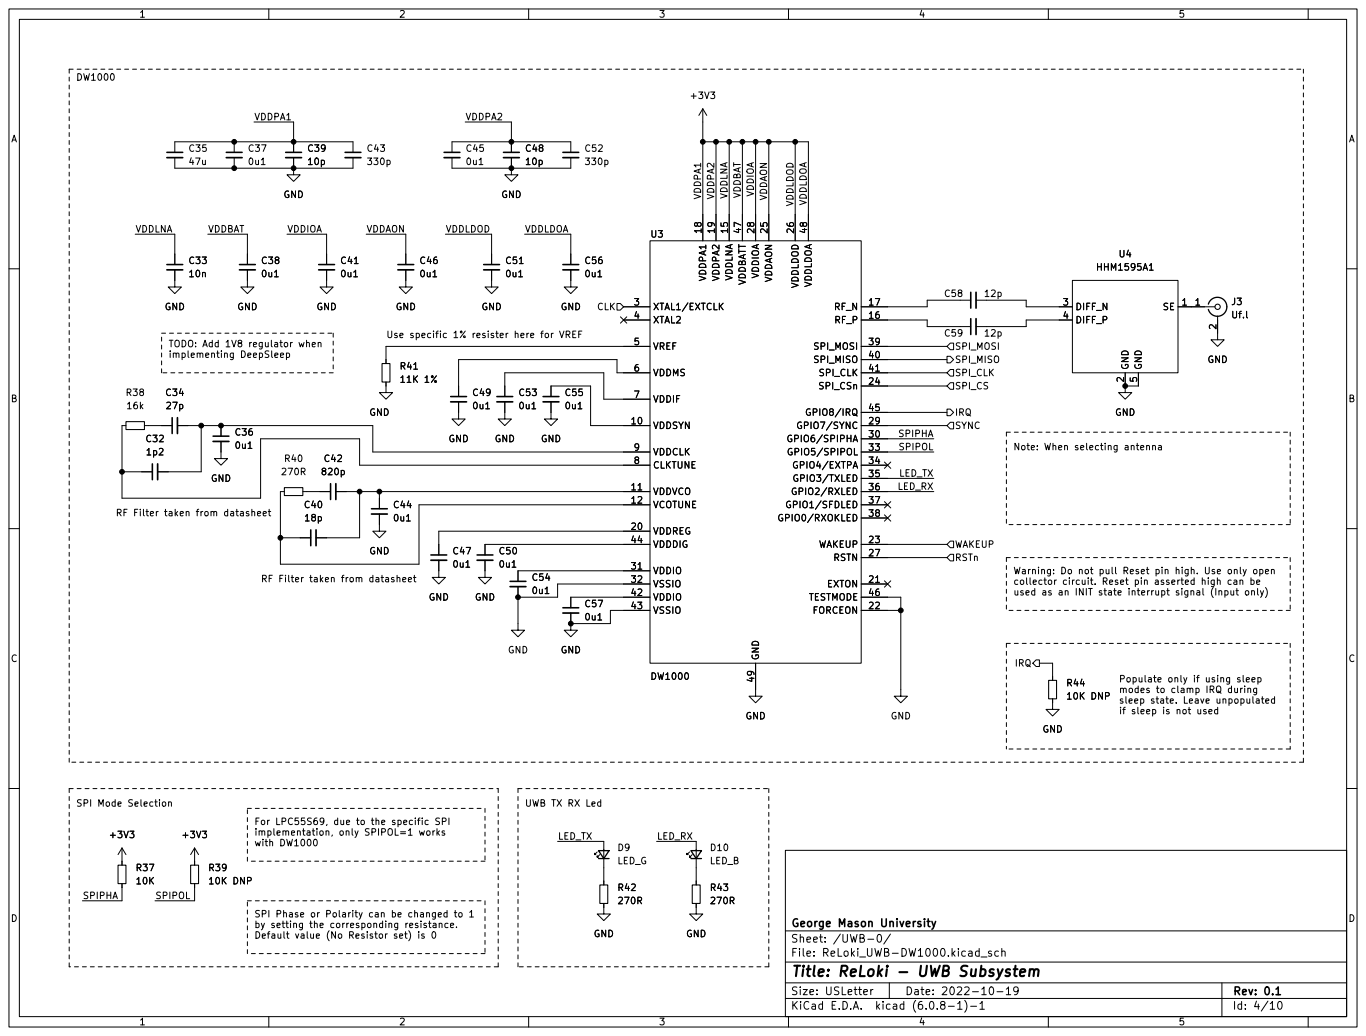
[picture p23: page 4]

TODO: Add 1V8 regulator when

Warning: Do not pull Reset pin high. Use only open
collector circuit. Reset pin asserted high can be

used as an INIT state interrupt signal (Input only) UWB TX RX Led

Populate only if using sleep
modes to clamp IRQ during
sleep state. Leave unpopulated
if sleep is not used

implementation, only SPIPOL=1 works with DW1000 SPI Mode Selection

For LPC55S69, due to the specific SPI

SPI Phase or Polarity can be changed to 1
by setting the corresponding resistance.
Default value (No Resistor set) is 0

File: ReLoki_UWB-DW1000.kicad_sch Sheet: /UWB-0/ George Mason University

Id: 4/10 Title: ReLoki - UWB Subsystem

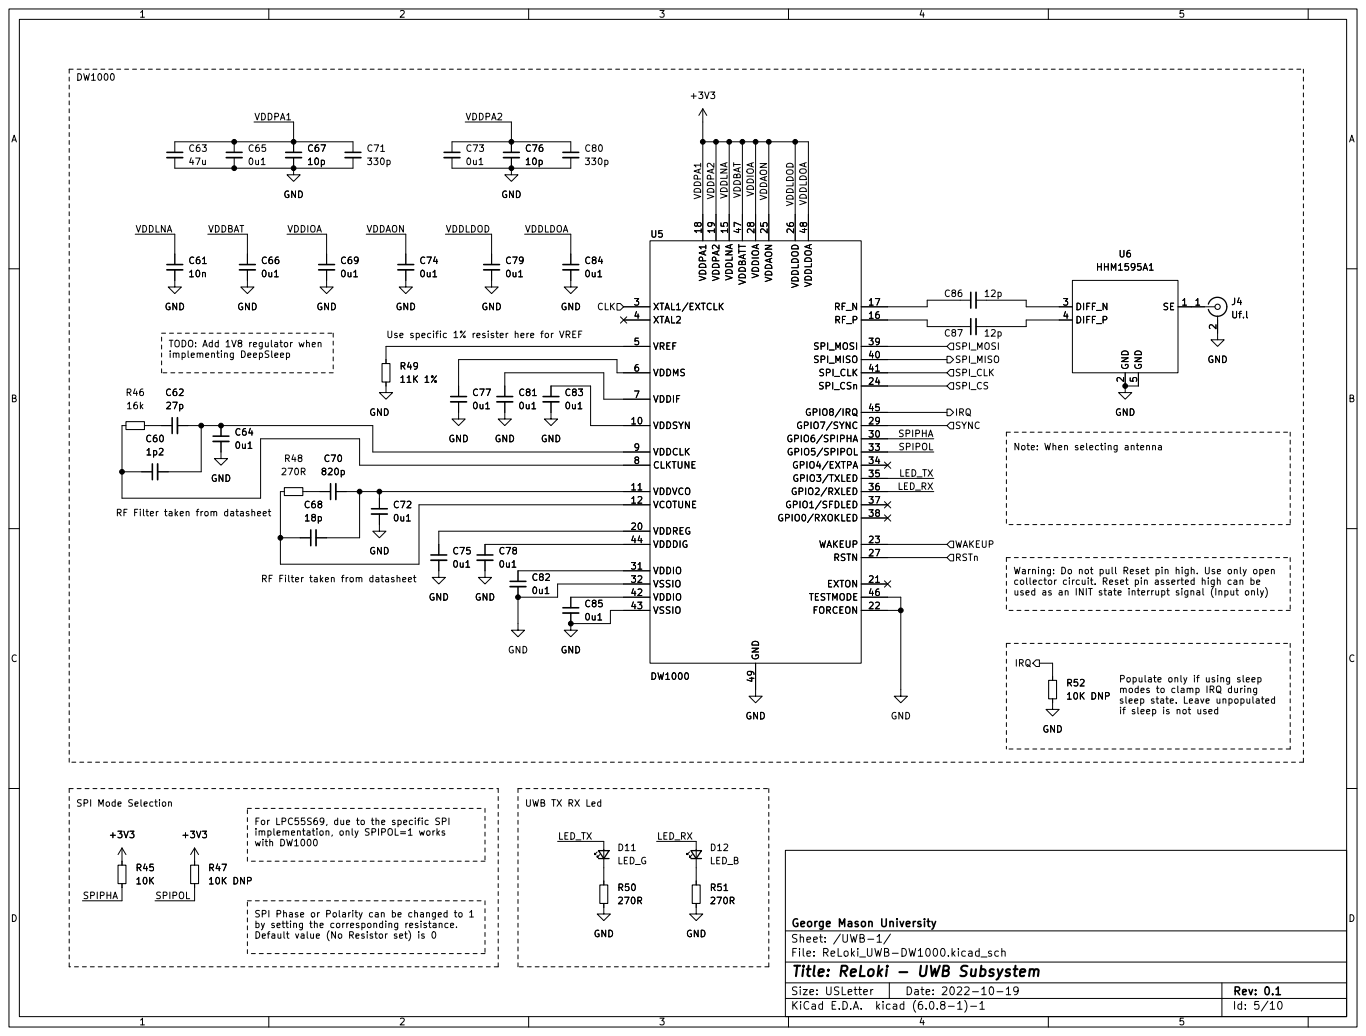
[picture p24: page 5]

TODO: Add 1V8 regulator when

Warning: Do not pull Reset pin high. Use only open
collector circuit. Reset pin asserted high can be

used as an INIT state interrupt signal (Input only) UWB TX RX Led

Populate only if using sleep
modes to clamp IRQ during
sleep state. Leave unpopulated
if sleep is not used

implementation, only SPIPOL=1 works with DW1000 SPI Mode Selection

For LPC55S69, due to the specific SPI

SPI Phase or Polarity can be changed to 1
by setting the corresponding resistance.
Default value (No Resistor set) is 0

File: ReLoki_UWB-DW1000.kicad_sch Sheet: /UWB-1/ George Mason University

Id: 5/10 Title: ReLoki - UWB Subsystem

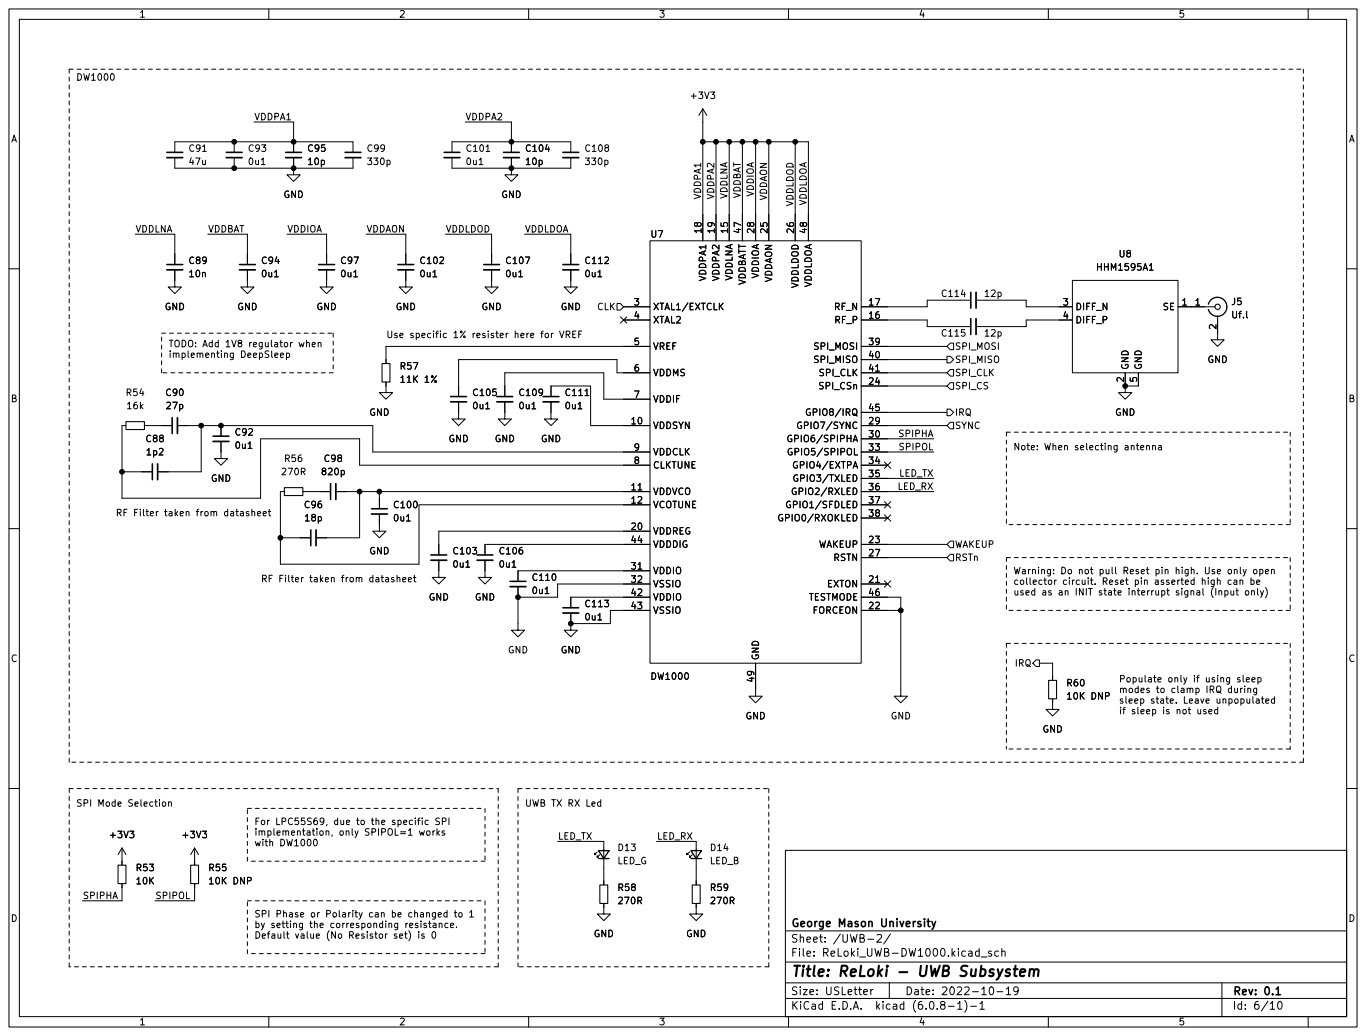
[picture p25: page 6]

TODO: Add 1V8 regulator when

Warning: Do not pull Reset pin high. Use only open
collector circuit. Reset pin asserted high can be

used as an INIT state interrupt signal (Input only) UWB TX RX Led

Populate only if using sleep
modes to clamp IRQ during
sleep state. Leave unpopulated
if sleep is not used

implementation, only SPIPOL=1 works with DW1000 SPI Mode Selection

For LPC55S69, due to the specific SPI

SPI Phase or Polarity can be changed to 1
by setting the corresponding resistance.
Default value (No Resistor set) is 0

File: ReLoki_UWB-DW1000.kicad_sch Sheet: /UWB-2/ George Mason University

Id: 6/10 Title: ReLoki - UWB Subsystem

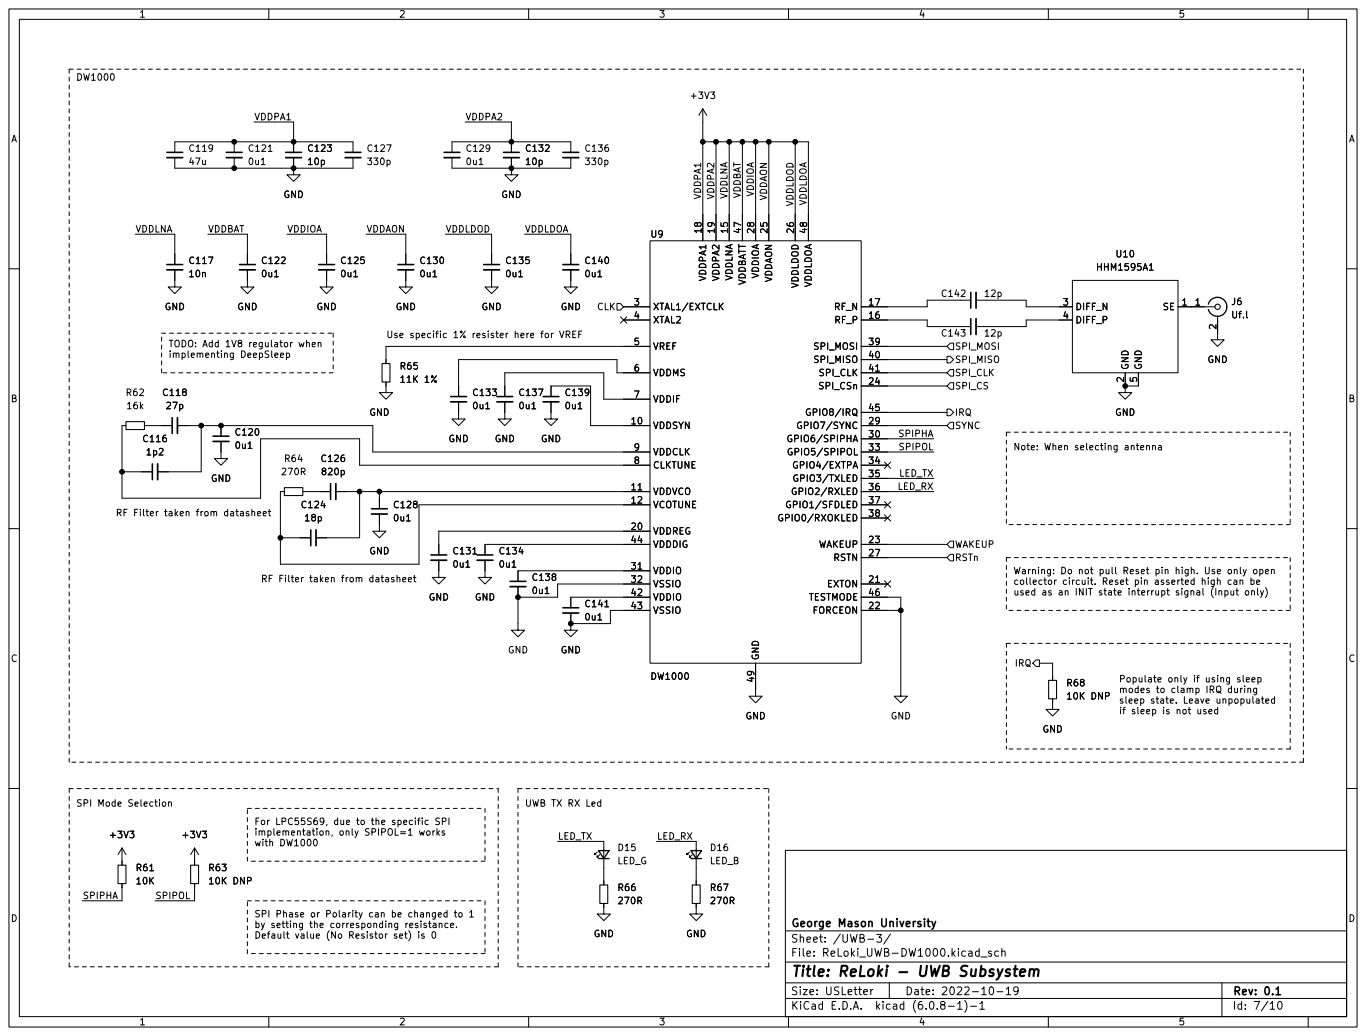
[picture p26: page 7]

TODO: Add 1V8 regulator when

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

used as an INIT state interrupt signal (Input only) UWB TX RX Led

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

implementation, only SPIPOL=1 works with DW1000 SPI Mode Selection

For LPC55S69, due to the specific SPI

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

File: ReLoki_UWB-DW1000.kicad_sch Sheet: /UWB-3/ George Mason University

Id: 7/10 Title: ReLoki - UWB Subsystem

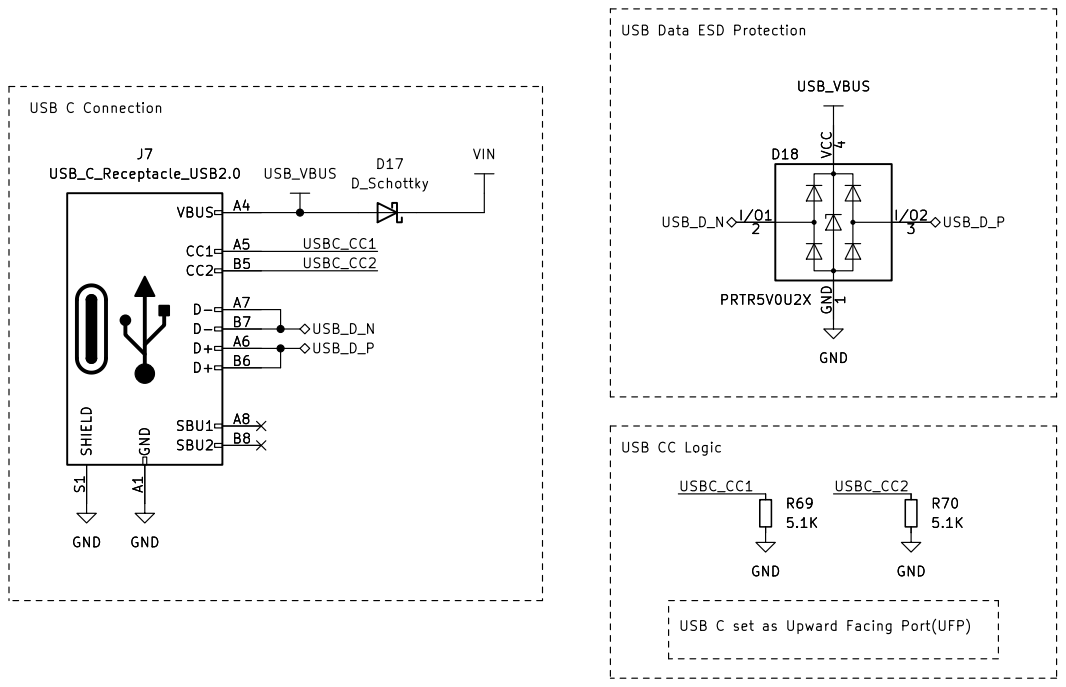
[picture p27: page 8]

File: ReLoki_USB.kicad_sch Sheet: /USB-C/ Geroge Mason University

Id: 8/10 Title: ReLoki - USB Device Interface


File: ReLoki_HostSPI.kicad_sch Sheet: /Host SPI Bus/ George Mason University D20A
PESD3V3L4UF D20B D20C GND

Id: 9/10 Title: ReLoki - Host SPI Slave Interface

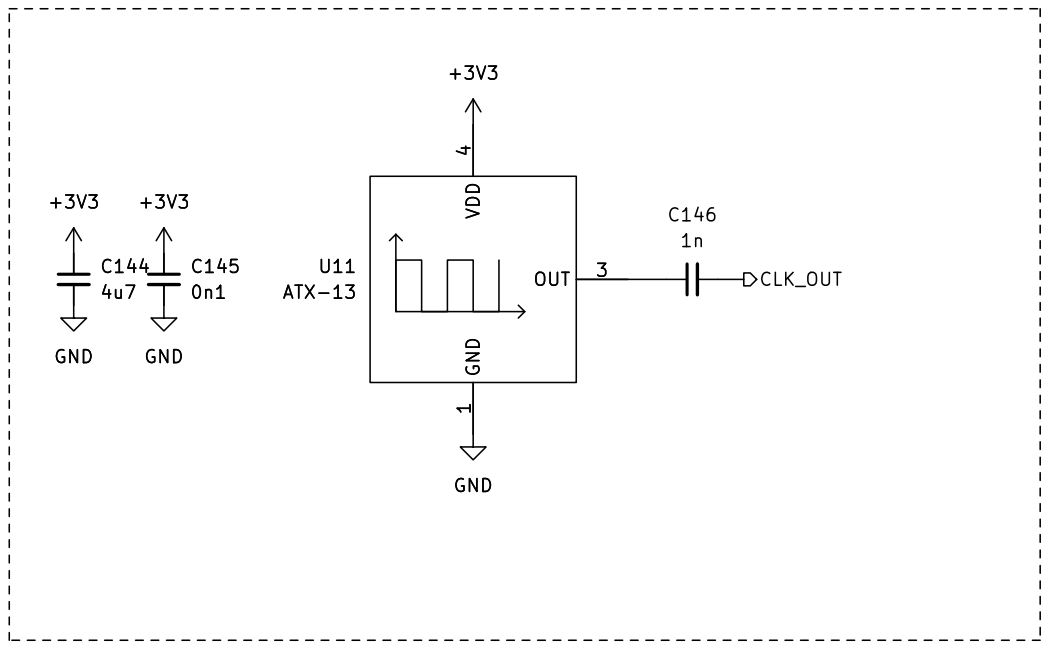
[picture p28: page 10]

4 U11 ATX-13 GND GND GND

File: ReLoki_TCXO.kicad_sch Sheet: /TCXO/ George Mason University GND

Id: 10/10 Title: ReLoki - UWB Clock Source

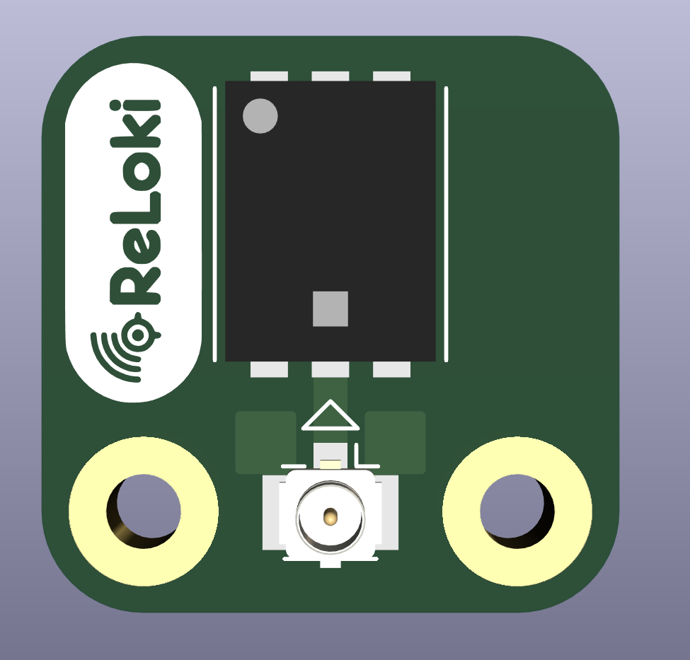
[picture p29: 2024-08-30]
hardware/ReLoki_ECAD/Print_OP/ReLoki_UWBBreakout_PCB.png

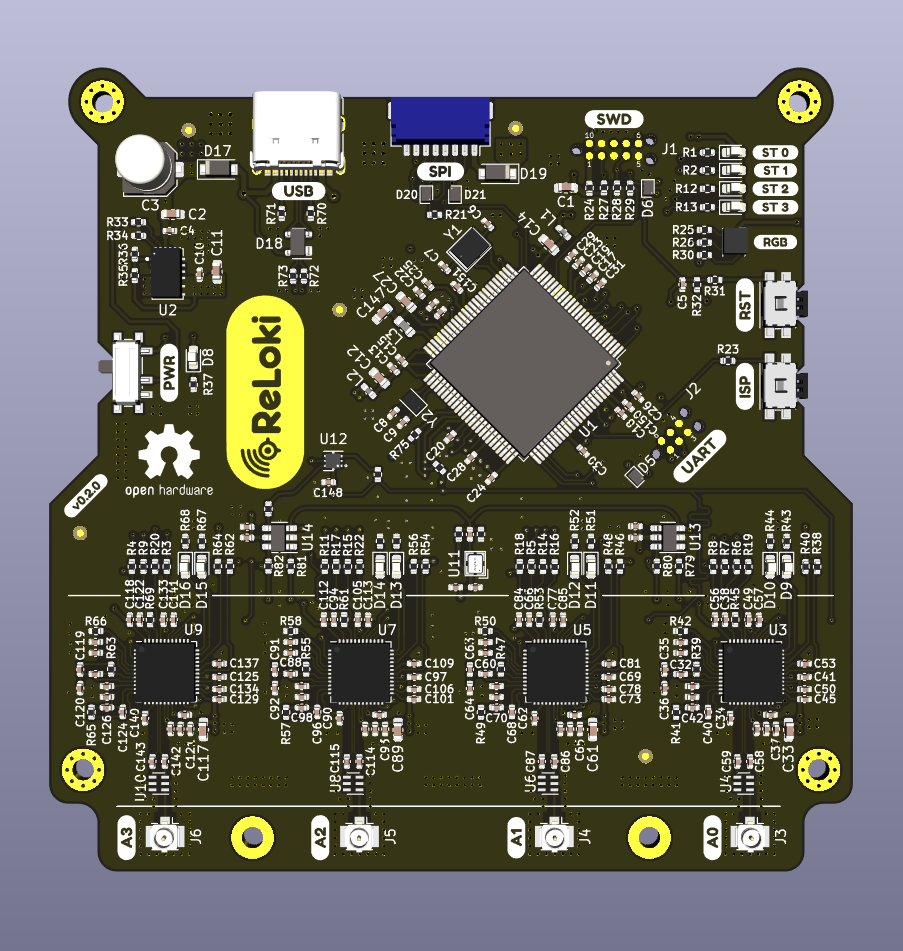
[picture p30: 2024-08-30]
hardware/ReLoki_ECAD/Print_OP/ReLoki_ECAD_PCB_3D-v0_2_0.png

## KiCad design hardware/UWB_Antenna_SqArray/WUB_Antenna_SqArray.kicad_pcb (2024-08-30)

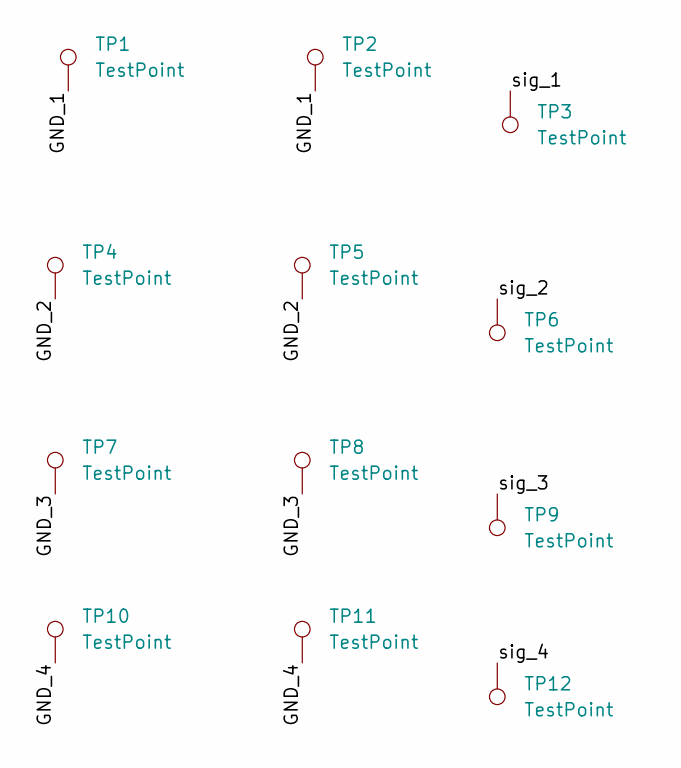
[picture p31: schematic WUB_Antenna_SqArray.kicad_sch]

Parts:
TP1, TP2, TP4, TP5, TP7, TP8, TP10, TP11: TestPoint; TestPoint_Pad_2.0x2.0mm
TP3, TP6, TP9, TP12: TestPoint; TestPoint_Pad_1.0x1.0mm

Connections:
/GND_1: TP1.1, TP2.1
/GND_2: TP4.1, TP5.1
/GND_3: TP7.1, TP8.1
/GND_4: TP10.1, TP11.1
/sig_1: TP3.1
/sig_2: TP6.1
/sig_3: TP9.1
/sig_4: TP12.1

Board: 2 copper layers, 16 parts (2 on the bottom side), 4 nets, no tracks yet.

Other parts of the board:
kibuzzard-664B60AC: G***; kibuzzard-664B60AC
kibuzzard-6643D5B9: G***; kibuzzard-6643D5B9
kibuzzard-6643D605: G***; kibuzzard-6643D605
kibuzzard-6643D800: G***; kibuzzard-6643D800

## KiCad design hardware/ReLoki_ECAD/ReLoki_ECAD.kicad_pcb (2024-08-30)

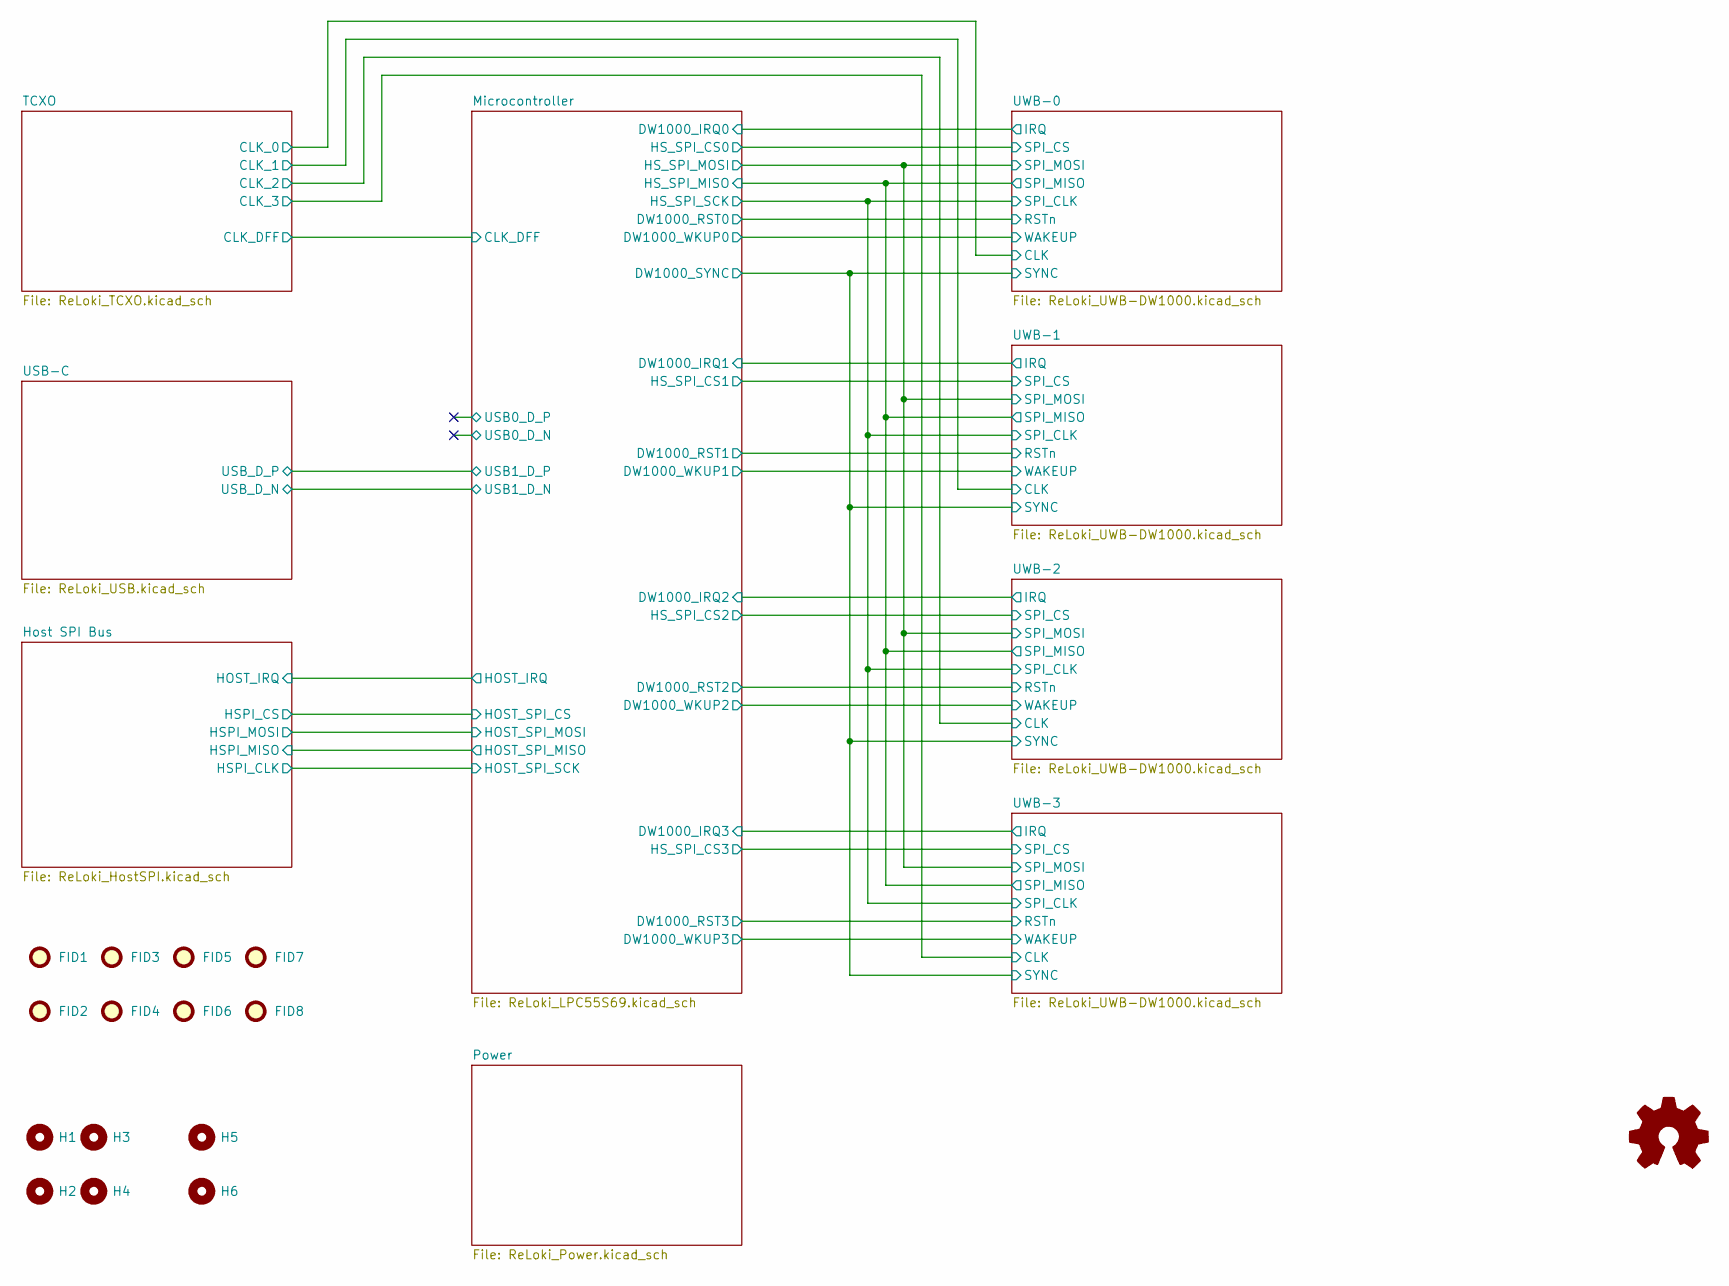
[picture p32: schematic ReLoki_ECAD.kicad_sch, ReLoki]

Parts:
FID1, FID2, FID3, FID4, FID5, FID6, FID7, FID8: Fiducial; Fiducial_0.75mm_Mask1.5mm
H1, H2, H3, H4: MountingHole; MountingHole_2.2mm_M2_Pad_Via
H5, H6: MountingHole; MountingHole_2.2mm_M2_Pad

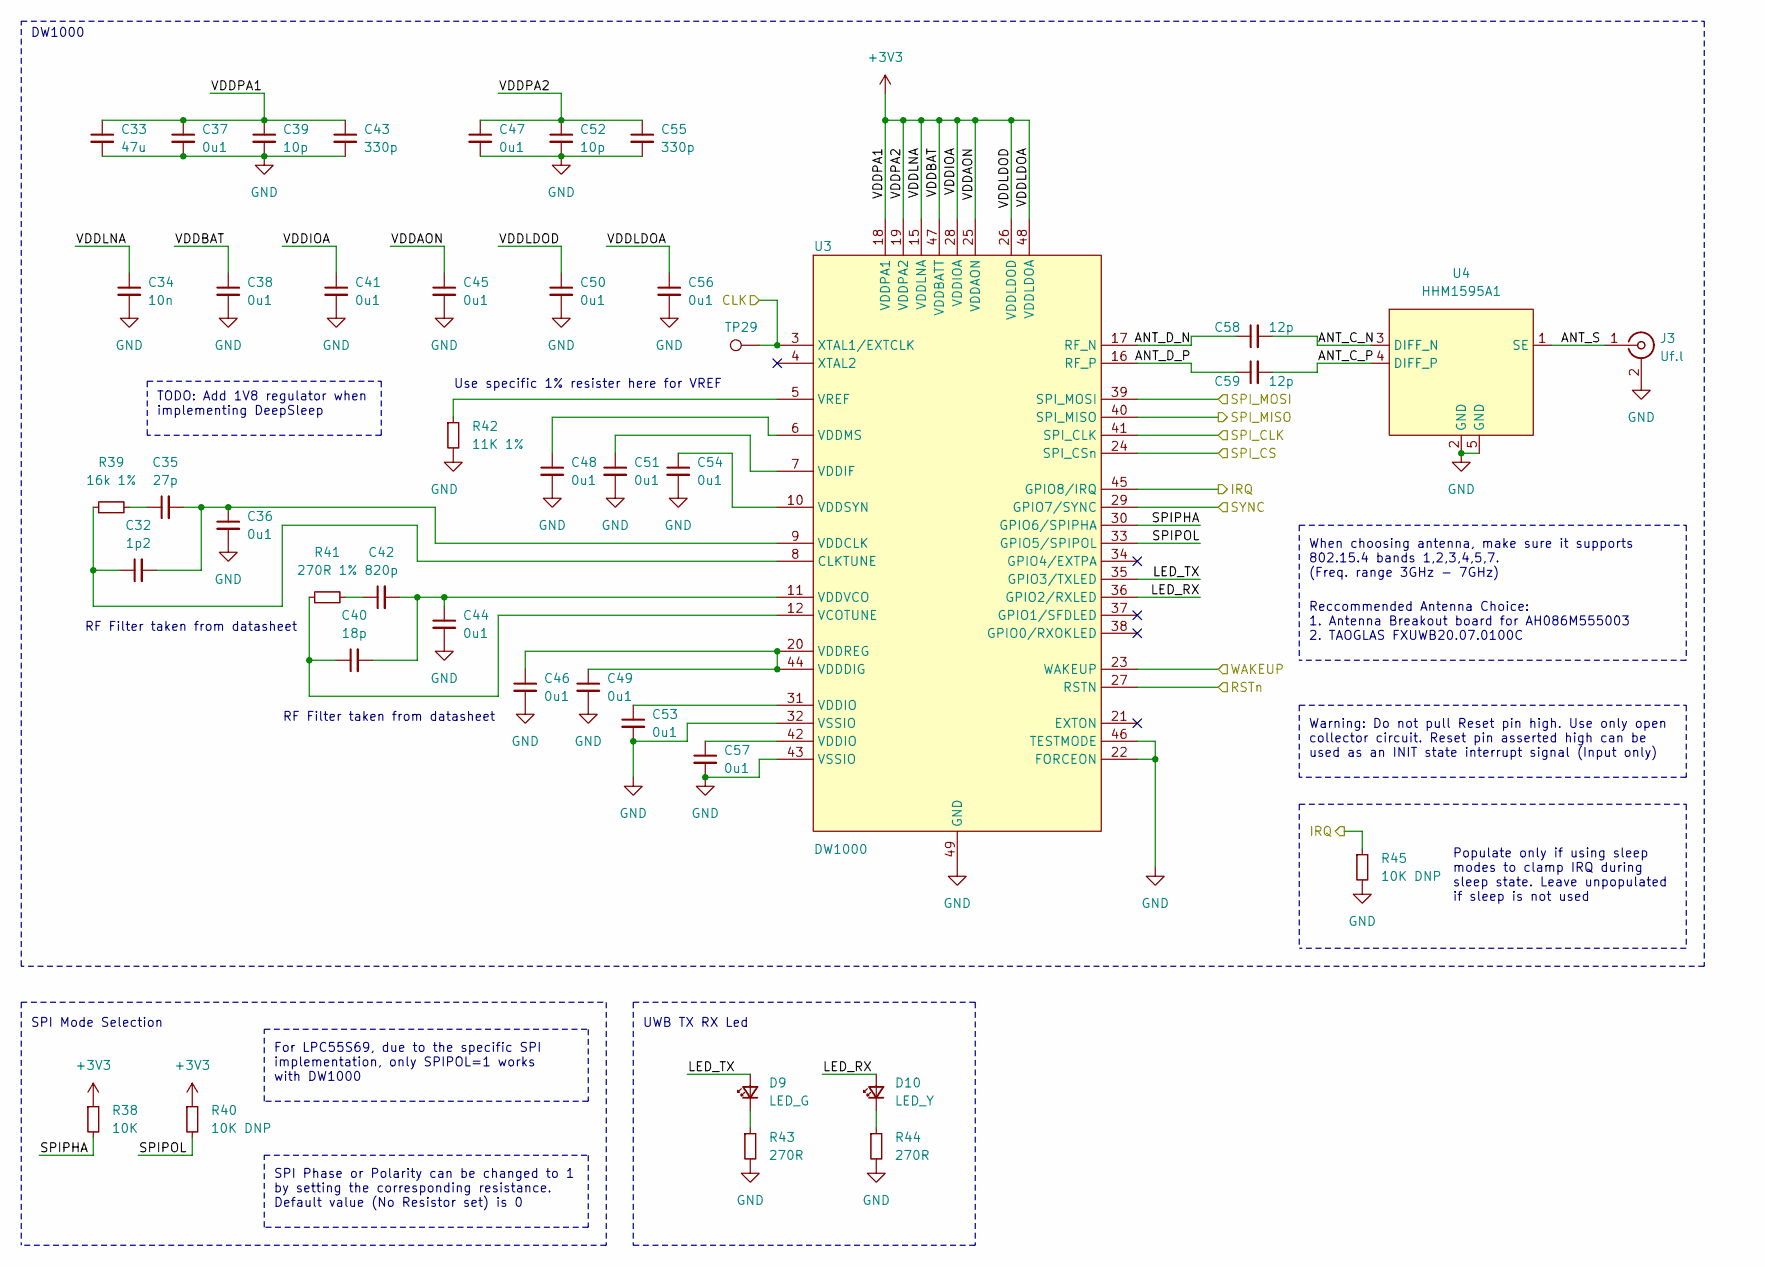
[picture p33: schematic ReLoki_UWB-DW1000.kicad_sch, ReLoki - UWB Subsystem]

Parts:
C32: 1p2; C_0402_1005Metric
C33: 47u; C_0603_1608Metric
C34: 10n; C_0402_1005Metric
C35: 27p; C_0402_1005Metric
C36, C37, C38, C41, C44, C45, C46, C47, C48, C49, C50, C51, C53, C54, C56, C57: 0u1; C_0402_1005Metric
C39, C52: 10p; C_0402_1005Metric
C40: 18p; C_0402_1005Metric
C42: 820p; C_0402_1005Metric
C43, C55: 330p; C_0402_1005Metric
C58, C59: 12p; C_0402_1005Metric
D9: LED_G; LED_0603_1608Metric
D10: LED_Y; LED_0603_1608Metric
J3: Uf.l; U.FL_Hirose_U.FL-R-SMT-1_Vertical
R38: 10K; R_0402_1005Metric
R39: 16k 1%; R_0402_1005Metric
R40, R45: 10K DNP; R_0402_1005Metric
R41: 270R 1%; R_0402_1005Metric
R42: 11K 1%; R_0402_1005Metric
R43, R44: 270R; R_0402_1005Metric
TP29: TestPoint; TestPoint_Pad_D1.0mm
U3: DW1000; QFN-48-1EP_6x6mm_P0.4mm_EP4.2x4.2mm_ThermalVias
U4: HHM1595A1

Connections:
+3V3: C33.1, C34.1, C37.1, C38.1, C39.1, C41.1, C43.1, C45.1, C47.1, C50.1, C52.1, C55.1, C56.1, R38.1, R40.1, U3.15 (VDDLNA), U3.18 (VDDPA1), U3.19 (VDDPA2), U3.25 (VDDAON), U3.26 (VDDLDOD), U3.28 (VDDIOA), U3.47 (VDDBATT), U3.48 (VDDLDOA); also elsewhere on the board
/Microcontroller/DW1000_IRQ0: R45.1, U3.45 (GPIO8/IRQ); also elsewhere on the board
/Microcontroller/DW1000_RST0: U3.27 (RSTN); also elsewhere on the board
/Microcontroller/DW1000_SYNC: U3.29 (GPIO7/SYNC); also elsewhere on the board
/Microcontroller/DW1000_WKUP0: U3.23 (WAKEUP); also elsewhere on the board
/Microcontroller/HS_SPI_CS0: U3.24 (SPI_CSn); also elsewhere on the board
/Microcontroller/HS_SPI_MISO: U3.40 (SPI_MISO); also elsewhere on the board
/Microcontroller/HS_SPI_MOSI: U3.39 (SPI_MOSI); also elsewhere on the board
/Microcontroller/HS_SPI_SCK: U3.41 (SPI_CLK); also elsewhere on the board
/TCXO/CLK_0: TP29.1, U3.3 (XTAL1/EXTCLK); also elsewhere on the board
/UWB-0/ANT_C_N: C58.2, U4.3 (DIFF_N)
/UWB-0/ANT_C_P: C59.2, U4.4 (DIFF_P)
/UWB-0/ANT_D_N: C58.1, U3.17 (RF_N)
/UWB-0/ANT_D_P: C59.1, U3.16 (RF_P)
/UWB-0/ANT_S: J3.1 (In), U4.1 (SE)
/UWB-0/LED_RX: D10.2 (A), U3.36 (GPIO2/RXLED)
/UWB-0/LED_TX: D9.2 (A), U3.35 (GPIO3/TXLED)
/UWB-0/SPIPHA: R38.2, U3.30 (GPIO6/SPIPHA)
/UWB-0/SPIPOL: R40.2, U3.33 (GPIO5/SPIPOL)
GND: C33.2, C34.2, C36.2, C37.2, C38.2, C39.2, C41.2, C43.2, C44.2, C45.2, C46.2, C47.2, C48.2, C49.2, C50.2, C51.2, C52.2, C53.2, C54.2, C55.2, C56.2, C57.2, J3.2 (Ext), R42.2, R43.2, R44.2, R45.2, U3.22 (FORCEON), U3.32 (VSSIO), U3.43 (VSSIO), U3.46 (TESTMODE), U3.49 (GND), U4.2 (GND), U4.5 (GND); also elsewhere on the board
unnamed: C32.1, R39.1, U3.8 (CLKTUNE)
unnamed: C32.2, C35.2, C36.1, U3.9 (VDDCLK)
unnamed: C35.1, R39.2
unnamed: C40.1, R41.1, U3.12 (VCOTUNE)
unnamed: C40.2, C42.2, C44.1, U3.11 (VDDVCO)
unnamed: C42.1, R41.2
unnamed: C46.1, C49.1, U3.20 (VDDREG), U3.44 (VDDDIG)
unnamed: C48.1, U3.6 (VDDMS)
unnamed: C51.1, U3.7 (VDDIF)
unnamed: C53.1, U3.31 (VDDIO)
unnamed: C54.1, U3.10 (VDDSYN)
unnamed: C57.1, U3.42 (VDDIO)
unnamed: D9.1 (K), R43.1
unnamed: D10.1 (K), R44.1
unnamed: R42.1, U3.5 (VREF)

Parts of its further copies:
C60, C88, C116: 1p2; C_0402_1005Metric
C61, C89, C117: 47u; C_0603_1608Metric
C62, C90, C118: 10n; C_0402_1005Metric
C63, C91, C119: 27p; C_0402_1005Metric
C64, C65, C66, C69, C72, C73, C74, C75, C76, C77, C78, C79, C81, C82, C84, C85, C92, C93, C94, C97, C100, C101, C102, C103, C104, C105, C106, C107, C109, C110, C112, C113, C120, C121, C122, C125, C128, C129, C130, C131, C132, C133, C134, C135, C137, C138, C140, C141: 0u1; C_0402_1005Metric
C67, C80, C95, C108, C123, C136: 10p; C_0402_1005Metric
C68, C96, C124: 18p; C_0402_1005Metric
C70, C98, C126: 820p; C_0402_1005Metric
C71, C83, C99, C111, C127, C139: 330p; C_0402_1005Metric
C86, C87, C114, C115, C142, C143: 12p; C_0402_1005Metric
D11, D13, D15: LED_G; LED_0603_1608Metric
D12, D14, D16: LED_Y; LED_0603_1608Metric
J4, J5, J6: Uf.l; U.FL_Hirose_U.FL-R-SMT-1_Vertical
R46, R54, R62: 10K; R_0402_1005Metric
R47, R55, R63: 16k 1%; R_0402_1005Metric
R48, R53, R56, R61, R64, R69: 10K DNP; R_0402_1005Metric
R49, R57, R65: 270R 1%; R_0402_1005Metric
R50, R58, R66: 11K 1%; R_0402_1005Metric
R51, R52, R59, R60, R67, R68: 270R; R_0402_1005Metric
TP30, TP31, TP32: TestPoint; TestPoint_Pad_D1.0mm
U5, U7, U9: DW1000; QFN-48-1EP_6x6mm_P0.4mm_EP4.2x4.2mm_ThermalVias
U6, U8, U10: HHM1595A1

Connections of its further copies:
+3V3: C61.1, C62.1, C65.1, C66.1, C67.1, C69.1, C71.1, C73.1, C75.1, C78.1, C80.1, C83.1, C84.1, C89.1, C90.1, C93.1, C94.1, C95.1, C97.1, C99.1, C101.1, C103.1, C106.1, C108.1, C111.1, C112.1, C117.1, C118.1, C121.1, C122.1, C123.1, C125.1, C127.1, C129.1, C131.1, C134.1, C136.1, C139.1, C140.1, R46.1, R48.1, R54.1, R56.1, R62.1, R64.1, U5.15 (VDDLNA), U5.18 (VDDPA1), U5.19 (VDDPA2), U5.25 (VDDAON), U5.26 (VDDLDOD), U5.28 (VDDIOA), U5.47 (VDDBATT), U5.48 (VDDLDOA), U7.15 (VDDLNA), U7.18 (VDDPA1), U7.19 (VDDPA2), U7.25 (VDDAON), U7.26 (VDDLDOD), U7.28 (VDDIOA), U7.47 (VDDBATT), U7.48 (VDDLDOA), U9.15 (VDDLNA), U9.18 (VDDPA1), U9.19 (VDDPA2), U9.25 (VDDAON), U9.26 (VDDLDOD), U9.28 (VDDIOA), U9.47 (VDDBATT), U9.48 (VDDLDOA); also elsewhere on the board
/Microcontroller/DW1000_IRQ1: R53.1, U5.45 (GPIO8/IRQ); also elsewhere on the board
/Microcontroller/DW1000_IRQ2: R61.1, U7.45 (GPIO8/IRQ); also elsewhere on the board
/Microcontroller/DW1000_IRQ3: R69.1, U9.45 (GPIO8/IRQ); also elsewhere on the board
/Microcontroller/DW1000_RST1: U5.27 (RSTN); also elsewhere on the board
/Microcontroller/DW1000_RST2: U7.27 (RSTN); also elsewhere on the board
/Microcontroller/DW1000_RST3: U9.27 (RSTN); also elsewhere on the board
/Microcontroller/DW1000_SYNC: U5.29 (GPIO7/SYNC), U7.29 (GPIO7/SYNC), U9.29 (GPIO7/SYNC); also elsewhere on the board
/Microcontroller/DW1000_WKUP1: U5.23 (WAKEUP); also elsewhere on the board
/Microcontroller/DW1000_WKUP2: U7.23 (WAKEUP); also elsewhere on the board
/Microcontroller/DW1000_WKUP3: U9.23 (WAKEUP); also elsewhere on the board
/Microcontroller/HS_SPI_CS1: U5.24 (SPI_CSn); also elsewhere on the board
/Microcontroller/HS_SPI_CS2: U7.24 (SPI_CSn); also elsewhere on the board
/Microcontroller/HS_SPI_CS3: U9.24 (SPI_CSn); also elsewhere on the board
/Microcontroller/HS_SPI_MISO: U5.40 (SPI_MISO), U7.40 (SPI_MISO), U9.40 (SPI_MISO); also elsewhere on the board
/Microcontroller/HS_SPI_MOSI: U5.39 (SPI_MOSI), U7.39 (SPI_MOSI), U9.39 (SPI_MOSI); also elsewhere on the board
/Microcontroller/HS_SPI_SCK: U5.41 (SPI_CLK), U7.41 (SPI_CLK), U9.41 (SPI_CLK); also elsewhere on the board
/TCXO/CLK_1: TP30.1, U5.3 (XTAL1/EXTCLK); also elsewhere on the board
/TCXO/CLK_2: TP31.1, U7.3 (XTAL1/EXTCLK); also elsewhere on the board
/TCXO/CLK_3: TP32.1, U9.3 (XTAL1/EXTCLK); also elsewhere on the board
/UWB-1/ANT_C_N: C86.2, U6.3 (DIFF_N)
/UWB-1/ANT_C_P: C87.2, U6.4 (DIFF_P)
/UWB-1/ANT_D_N: C86.1, U5.17 (RF_N)
/UWB-1/ANT_D_P: C87.1, U5.16 (RF_P)
/UWB-1/ANT_S: J4.1 (In), U6.1 (SE)
/UWB-1/LED_RX: D12.2 (A), U5.36 (GPIO2/RXLED)
/UWB-1/LED_TX: D11.2 (A), U5.35 (GPIO3/TXLED)
/UWB-1/SPIPHA: R46.2, U5.30 (GPIO6/SPIPHA)
/UWB-1/SPIPOL: R48.2, U5.33 (GPIO5/SPIPOL)
/UWB-2/ANT_C_N: C114.2, U8.3 (DIFF_N)
/UWB-2/ANT_C_P: C115.2, U8.4 (DIFF_P)
/UWB-2/ANT_D_N: C114.1, U7.17 (RF_N)
/UWB-2/ANT_D_P: C115.1, U7.16 (RF_P)
/UWB-2/ANT_S: J5.1 (In), U8.1 (SE)
/UWB-2/LED_RX: D14.2 (A), U7.36 (GPIO2/RXLED)
/UWB-2/LED_TX: D13.2 (A), U7.35 (GPIO3/TXLED)
/UWB-2/SPIPHA: R54.2, U7.30 (GPIO6/SPIPHA)
/UWB-2/SPIPOL: R56.2, U7.33 (GPIO5/SPIPOL)
/UWB-3/ANT_C_N: C142.2, U10.3 (DIFF_N)
/UWB-3/ANT_C_P: C143.2, U10.4 (DIFF_P)
/UWB-3/ANT_D_N: C142.1, U9.17 (RF_N)
/UWB-3/ANT_D_P: C143.1, U9.16 (RF_P)
/UWB-3/ANT_S: J6.1 (In), U10.1 (SE)
/UWB-3/LED_RX: D16.2 (A), U9.36 (GPIO2/RXLED)
/UWB-3/LED_TX: D15.2 (A), U9.35 (GPIO3/TXLED)
/UWB-3/SPIPHA: R62.2, U9.30 (GPIO6/SPIPHA)
/UWB-3/SPIPOL: R64.2, U9.33 (GPIO5/SPIPOL)
GND: C61.2, C62.2, C64.2, C65.2, C66.2, C67.2, C69.2, C71.2, C72.2, C73.2, C74.2, C75.2, C76.2, C77.2, C78.2, C79.2, C80.2, C81.2, C82.2, C83.2, C84.2, C85.2, C89.2, C90.2, C92.2, C93.2, C94.2, C95.2, C97.2, C99.2, C100.2, C101.2, C102.2, C103.2, C104.2, C105.2, C106.2, C107.2, C108.2, C109.2, C110.2, C111.2, C112.2, C113.2, C117.2, C118.2, C120.2, C121.2, C122.2, C123.2, C125.2, C127.2, C128.2, C129.2, C130.2, C131.2, C132.2, C133.2, C134.2, C135.2, C136.2, C137.2, C138.2, C139.2, C140.2, C141.2, J4.2 (Ext), J5.2 (Ext), J6.2 (Ext), R50.2, R51.2, R52.2, R53.2, R58.2, R59.2, R60.2, R61.2, R66.2, R67.2, R68.2, R69.2, U5.22 (FORCEON), U5.32 (VSSIO), U5.43 (VSSIO), U5.46 (TESTMODE), U5.49 (GND), U6.2 (GND), U6.5 (GND), U7.22 (FORCEON), U7.32 (VSSIO), U7.43 (VSSIO), U7.46 (TESTMODE), U7.49 (GND), U8.2 (GND), U8.5 (GND), U9.22 (FORCEON), U9.32 (VSSIO), U9.43 (VSSIO), U9.46 (TESTMODE), U9.49 (GND), U10.2 (GND), U10.5 (GND); also elsewhere on the board
unnamed: C60.1, R47.1, U5.8 (CLKTUNE)
unnamed: C60.2, C63.2, C64.1, U5.9 (VDDCLK)
unnamed: C63.1, R47.2
unnamed: C68.1, R49.1, U5.12 (VCOTUNE)
unnamed: C68.2, C70.2, C72.1, U5.11 (VDDVCO)
unnamed: C70.1, R49.2
unnamed: C74.1, C77.1, U5.20 (VDDREG), U5.44 (VDDDIG)
unnamed: C76.1, U5.6 (VDDMS)
unnamed: C79.1, U5.7 (VDDIF)
unnamed: C81.1, U5.31 (VDDIO)
unnamed: C82.1, U5.10 (VDDSYN)
unnamed: C85.1, U5.42 (VDDIO)
unnamed: C88.1, R55.1, U7.8 (CLKTUNE)
unnamed: C88.2, C91.2, C92.1, U7.9 (VDDCLK)
unnamed: C91.1, R55.2
unnamed: C96.1, R57.1, U7.12 (VCOTUNE)
unnamed: C98.1, R57.2
unnamed: C96.2, C98.2, C100.1, U7.11 (VDDVCO)
unnamed: C102.1, C105.1, U7.20 (VDDREG), U7.44 (VDDDIG)
unnamed: C104.1, U7.6 (VDDMS)
unnamed: C107.1, U7.7 (VDDIF)
unnamed: C109.1, U7.31 (VDDIO)
unnamed: C110.1, U7.10 (VDDSYN)
unnamed: C113.1, U7.42 (VDDIO)
unnamed: C116.1, R63.1, U9.8 (CLKTUNE)
unnamed: C116.2, C119.2, C120.1, U9.9 (VDDCLK)
unnamed: C119.1, R63.2
unnamed: C124.1, R65.1, U9.12 (VCOTUNE)
unnamed: C124.2, C126.2, C128.1, U9.11 (VDDVCO)
unnamed: C126.1, R65.2
unnamed: C130.1, C133.1, U9.20 (VDDREG), U9.44 (VDDDIG)
unnamed: C132.1, U9.6 (VDDMS)
unnamed: C135.1, U9.7 (VDDIF)
unnamed: C137.1, U9.31 (VDDIO)
unnamed: C138.1, U9.10 (VDDSYN)
unnamed: C141.1, U9.42 (VDDIO)
unnamed: D11.1 (K), R51.1
unnamed: D12.1 (K), R52.1
unnamed: D13.1 (K), R59.1
unnamed: D14.1 (K), R60.1
unnamed: D15.1 (K), R67.1
unnamed: D16.1 (K), R68.1
unnamed: R50.1, U5.5 (VREF)
unnamed: R58.1, U7.5 (VREF)
unnamed: R66.1, U9.5 (VREF)

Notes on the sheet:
Use specific 1% resister here for VREF
RF Filter taken from datasheet
DW1000
When choosing antenna, make sure it supports 802.15.4 bands 1,2,3,4,5,7. (Freq. range 3GHz - 7GHz)
UWB TX RX Led
Reccommended Antenna Choice: 1. Antenna Breakout board for AH086M555003 2. TAOGLAS FXUWB20.07.0100C
SPI Phase or Polarity can be changed to 1 by setting the corresponding resistance. Default value (No Resistor set) is 0
Populate only if using sleep modes to clamp IRQ during sleep state. Leave unpopulated if sleep is not used
SPI Mode Selection
For LPC55S69, due to the specific SPI implementation, only SPIPOL=1 works with DW1000
Warning: Do not pull Reset pin high. Use only open collector circuit. Reset pin asserted high can be used as an INIT state interrupt signal (Input only)
TODO: Add 1V8 regulator when implementing DeepSleep

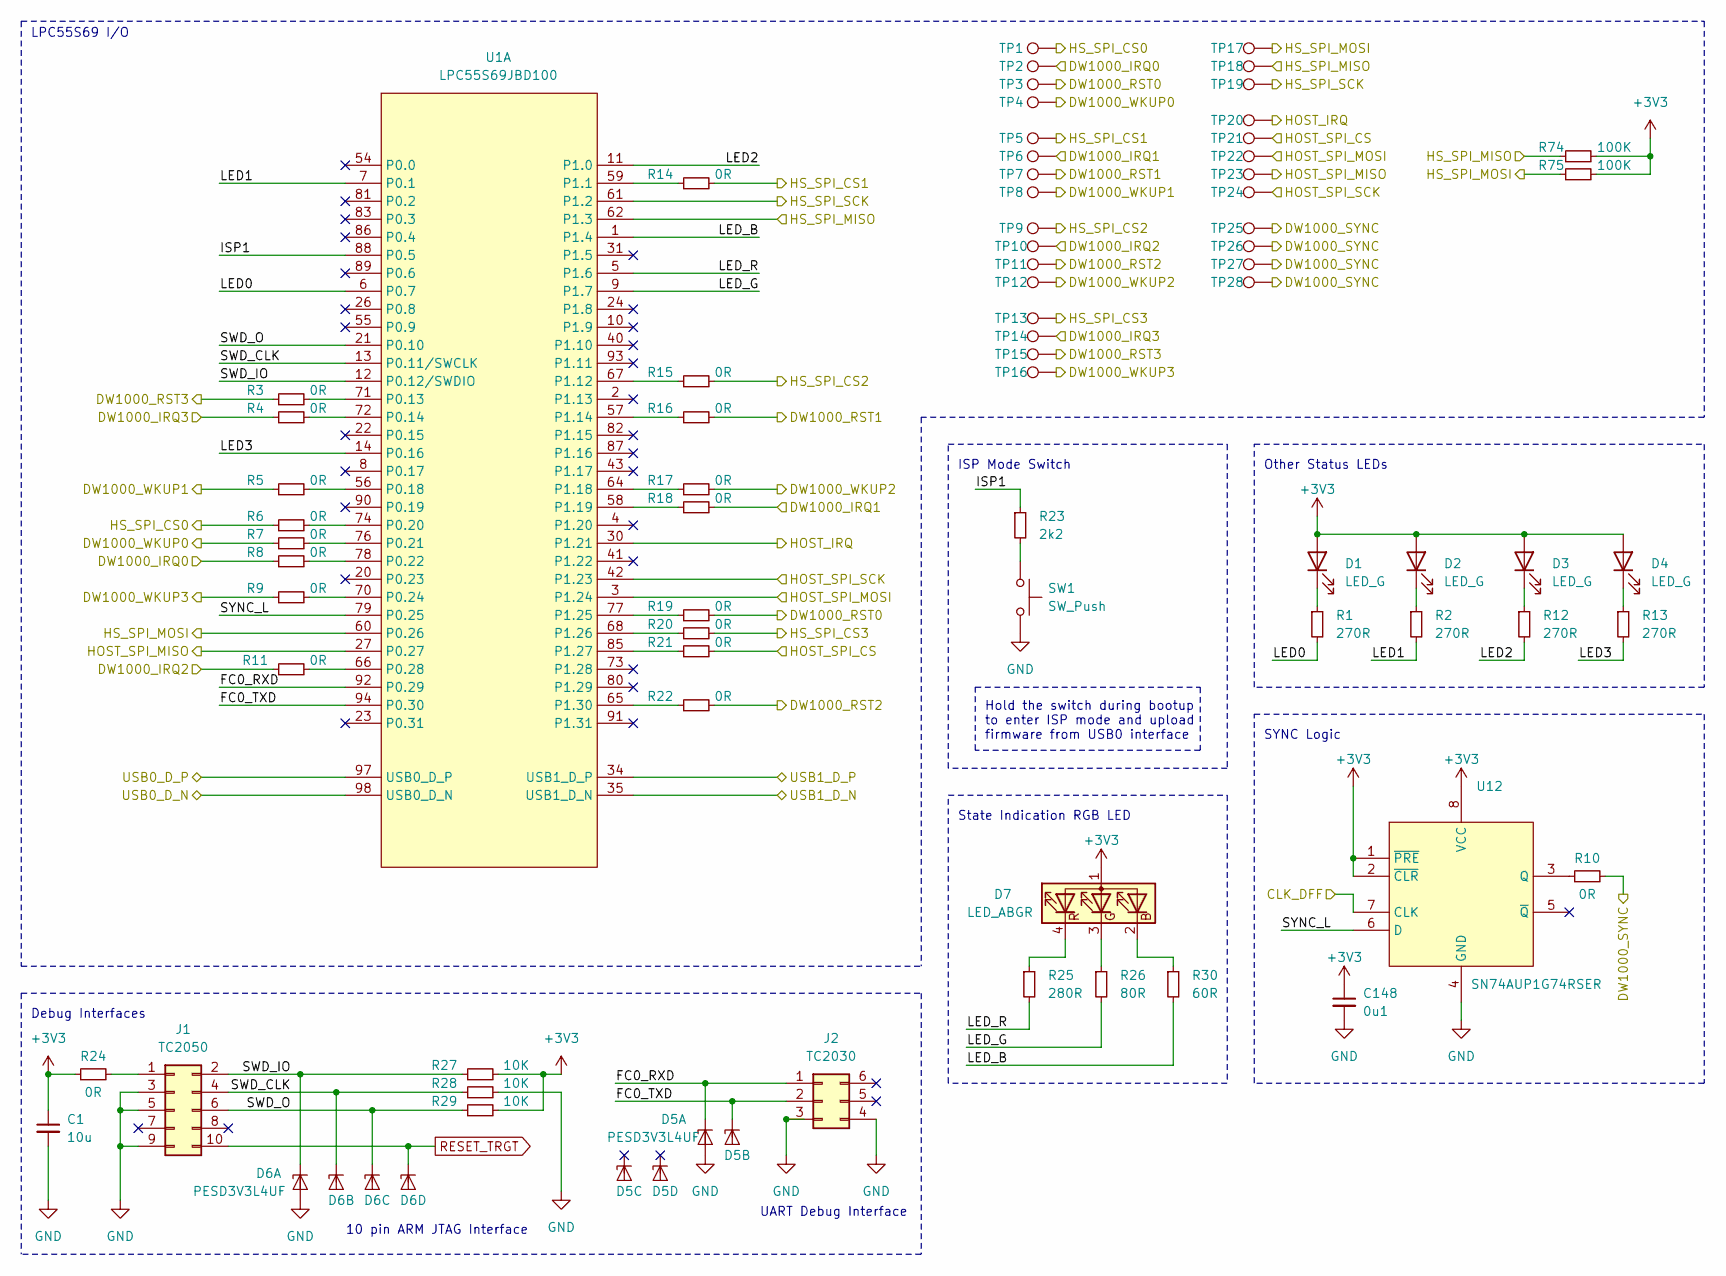
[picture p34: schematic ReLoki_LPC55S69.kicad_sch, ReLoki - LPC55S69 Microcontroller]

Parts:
C1: 10u; C_0603_1608Metric
C148: 0u1; C_0402_1005Metric
D1, D2, D3, D4: LED_G; LED_0603_1608Metric
D5, D6: PESD3V3L4UF; SOT-886
D7: LED_ABGR; LED_Cree-PLCC4_2x2mm_CW
J1: TC2050; TC2050-IDC-NL
J2: TC2030; TC2030-IDC-NL
R1, R2, R12, R13: 270R; R_0402_1005Metric
R3, R4, R5, R6, R7, R8, R9, R10, R11, R14, R15, R16, R17, R18, R19, R20, R21, R22, R24: 0R; R_0402_1005Metric
R23: 2k2; R_0402_1005Metric
R25: 280R; R_0402_1005Metric
R26: 80R; R_0402_1005Metric
R27, R28, R29: 10K; R_0402_1005Metric
R30: 60R; R_0402_1005Metric
R74, R75: 100K; R_0402_1005Metric
SW1: SW_Push; Panasonic_EVQPUL_EVQPUC
TP1, TP2, TP3, TP4, TP5, TP6, TP7, TP8, TP9, TP10, TP11, TP12, TP13, TP14, TP15, TP16, TP17, TP18, TP19, TP20, TP21, TP22, TP23, TP24, TP25, TP26, TP27, TP28: TestPoint; TestPoint_Pad_D1.0mm
U1: LPC55S69JBD100; HLQFP-100_14x14mm_P0.5mm
U12: SN74AUP1G74RSER; UQFN-8-1.55x1.55mm_P0.5mm

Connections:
+3V3: C1.1, C148.1, D1.2 (A), D2.2 (A), D3.2 (A), D4.2 (A), D7.1 (A), R24.1, R27.2, R29.2, R74.2, R75.2, U12.1 (~PRE), U12.2 (~CLR), U12.8 (VCC); also elsewhere on the board
/Host SPI Bus/HOST_IRQ: TP20.1, U1.30 (P1.21); also elsewhere on the board
/Host SPI Bus/HSPI_CLK: TP24.1, U1.42 (P1.23); also elsewhere on the board
/Host SPI Bus/HSPI_CS: R21.2, TP21.1; also elsewhere on the board
/Host SPI Bus/HSPI_MISO: TP23.1, U1.27 (P0.27); also elsewhere on the board
/Host SPI Bus/HSPI_MOSI: TP22.1, U1.3 (P1.24); also elsewhere on the board
/Microcontroller/CLK_DFF: U12.7 (CLK); also elsewhere on the board
/Microcontroller/DW1000_IRQ0: R8.1, TP2.1; also elsewhere on the board
/Microcontroller/DW1000_IRQ1: R18.2, TP6.1; also elsewhere on the board
/Microcontroller/DW1000_IRQ2: R11.1, TP10.1; also elsewhere on the board
/Microcontroller/DW1000_IRQ3: R4.1, TP14.1; also elsewhere on the board
/Microcontroller/DW1000_RST0: R19.2, TP3.1; also elsewhere on the board
/Microcontroller/DW1000_RST1: R16.2, TP7.1; also elsewhere on the board
/Microcontroller/DW1000_RST2: R22.2, TP11.1; also elsewhere on the board
/Microcontroller/DW1000_RST3: R3.1, TP15.1; also elsewhere on the board
/Microcontroller/DW1000_SYNC: R10.2, TP25.1, TP26.1, TP27.1, TP28.1; also elsewhere on the board
/Microcontroller/DW1000_WKUP0: R7.1, TP4.1; also elsewhere on the board
/Microcontroller/DW1000_WKUP1: R5.1, TP8.1; also elsewhere on the board
/Microcontroller/DW1000_WKUP2: R17.2, TP12.1; also elsewhere on the board
/Microcontroller/DW1000_WKUP3: R9.1, TP16.1; also elsewhere on the board
/Microcontroller/FC0_RXD: D5.1 (K1), J2.1, U1.92 (P0.29)
/Microcontroller/FC0_TXD: D5.3 (K2), J2.2, U1.94 (P0.30)
/Microcontroller/HS_SPI_CS0: R6.1, TP1.1; also elsewhere on the board
/Microcontroller/HS_SPI_CS1: R14.2, TP5.1; also elsewhere on the board
/Microcontroller/HS_SPI_CS2: R15.2, TP9.1; also elsewhere on the board
/Microcontroller/HS_SPI_CS3: R20.2, TP13.1; also elsewhere on the board
/Microcontroller/HS_SPI_MISO: R74.1, TP18.1, U1.62 (P1.3); also elsewhere on the board
/Microcontroller/HS_SPI_MOSI: R75.1, TP17.1, U1.60 (P0.26); also elsewhere on the board
/Microcontroller/HS_SPI_SCK: TP19.1, U1.61 (P1.2); also elsewhere on the board
/Microcontroller/ISP1: R23.1, U1.88 (P0.5)
/Microcontroller/LED0: R1.2, U1.6 (P0.7)
/Microcontroller/LED1: R2.2, U1.7 (P0.1)
/Microcontroller/LED2: R12.2, U1.11 (P1.0)
/Microcontroller/LED3: R13.2, U1.14 (P0.16)
/Microcontroller/LED_B: R30.2, U1.1 (P1.4)
/Microcontroller/LED_G: R26.2, U1.9 (P1.7)
/Microcontroller/LED_R: R25.2, U1.5 (P1.6)
/Microcontroller/SWD_CLK: D6.3 (K2), J1.4, R28.1, U1.13 (P0.11/SWCLK)
/Microcontroller/SWD_IO: D6.1 (K1), J1.2, R27.1, U1.12 (P0.12/SWDIO)
/Microcontroller/SWD_O: D6.4 (K3), J1.6, R29.1, U1.21 (P0.10)
/Microcontroller/SYNC_L: U1.79 (P0.25), U12.6 (D)
/Microcontroller/USB0_D_N: U1.98 (USB0_D_N)
/Microcontroller/USB0_D_P: U1.97 (USB0_D_P)
/Microcontroller/USB1_D_N: U1.35 (USB1_D_N); also elsewhere on the board
/Microcontroller/USB1_D_P: U1.34 (USB1_D_P); also elsewhere on the board
GND: C1.2, C148.2, D5.2 (A), D5.5 (A), D6.2 (A), D6.5 (A), J1.3, J1.5, J1.9, J2.3, J2.4, R28.2, SW1.1, U12.4 (GND); also elsewhere on the board
unnamed: D1.1 (K), R1.1
unnamed: D2.1 (K), R2.1
unnamed: D3.1 (K), R12.1
unnamed: D4.1 (K), R13.1
unnamed: D7.2 (BK), R30.1
unnamed: D7.3 (GK), R26.1
unnamed: D7.4 (RK), R25.1
unnamed: J1.1, R24.2
unnamed: R3.2, U1.71 (P0.13)
unnamed: R4.2, U1.72 (P0.14)
unnamed: R5.2, U1.56 (P0.18)
unnamed: R6.2, U1.74 (P0.20)
unnamed: R7.2, U1.76 (P0.21)
unnamed: R8.2, U1.78 (P0.22)
unnamed: R9.2, U1.70 (P0.24)
unnamed: R10.1, U12.3 (Q)
unnamed: R11.2, U1.66 (P0.28)
unnamed: R14.1, U1.59 (P1.1)
unnamed: R15.1, U1.67 (P1.12)
unnamed: R16.1, U1.57 (P1.14)
unnamed: R17.1, U1.64 (P1.18)
unnamed: R18.1, U1.58 (P1.19)
unnamed: R19.1, U1.77 (P1.25)
unnamed: R20.1, U1.68 (P1.26)
unnamed: R21.1, U1.85 (P1.27)
unnamed: R22.1, U1.65 (P1.30)
unnamed: R23.2, SW1.2
RESET_TRGT: D6.6 (K4), J1.10; also elsewhere on the board

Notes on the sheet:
Other Status LEDs
10 pin ARM JTAG Interface
UART Debug Interface
Debug Interfaces
State Indication RGB LED
LPC55S69 I/O
Hold the switch during bootup to enter ISP mode and upload firmware from USB0 interface
SYNC Logic
ISP Mode Switch

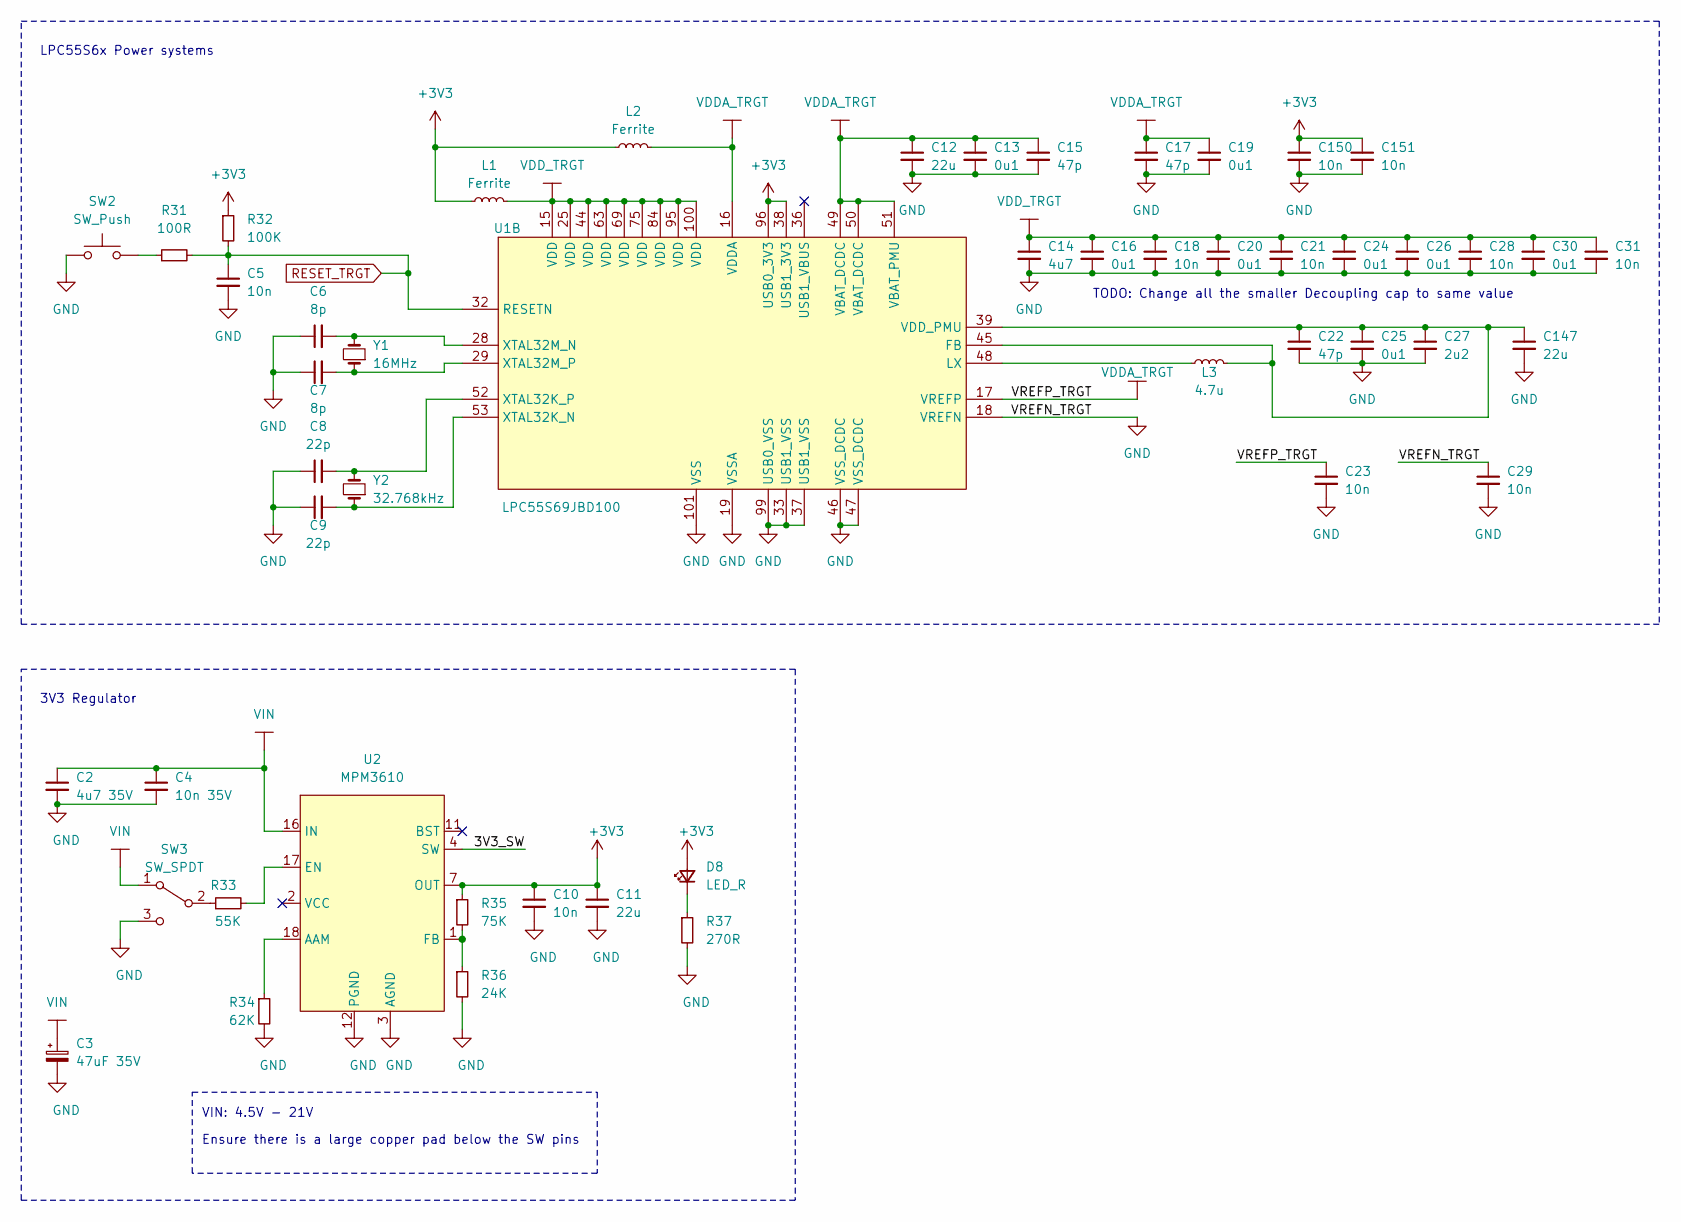
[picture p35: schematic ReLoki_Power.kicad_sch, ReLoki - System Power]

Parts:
C2: 4u7 35V; C_0603_1608Metric
C3: 47uF 35V; C_Elec_5x5.8
C4: 10n 35V; C_0402_1005Metric
C5, C10, C18, C21, C23, C28, C29, C31, C150, C151: 10n; C_0402_1005Metric
C6, C7: 8p; C_0402_1005Metric
C8, C9: 22p; C_0402_1005Metric
C11, C12, C147: 22u; C_0603_1608Metric
C13, C16, C19, C20, C24, C25, C26, C30: 0u1; C_0402_1005Metric
C14: 4u7; C_0603_1608Metric
C15, C17, C22: 47p; C_0402_1005Metric
C27: 2u2; C_0603_1608Metric
D8: LED_R; LED_0603_1608Metric
L1, L2: Ferrite; L_0402_1005Metric_Pad0.77x0.64mm_HandSolder
L3: 4.7u; L_0603_1608Metric
R31: 100R; R_0402_1005Metric
R32: 100K; R_0402_1005Metric
R33: 55K; R_0402_1005Metric
R34: 62K; R_0402_1005Metric
R35: 75K; R_0402_1005Metric
R36: 24K; R_0402_1005Metric
R37: 270R; R_0402_1005Metric
SW2: SW_Push; Panasonic_EVQPUL_EVQPUC
SW3: SW_SPDT; SW_SPDT_PCM12
U1: LPC55S69JBD100; HLQFP-100_14x14mm_P0.5mm
U2: MPM3610; MPM3610_QFN-20_5x3mm
Y1: 16MHz; Crystal_SMD_Kyocera_CX3225G-2Pin_3.2x2.5mm
Y2: 32.768kHz; Crystal_SMD_2012-2Pin_2.0x1.2mm

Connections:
+3V3: C10.1, C11.1, C150.1, C151.1, D8.2 (A), L1.1, L2.1, R32.1, R35.1, U1.38 (USB1_3V3), U1.96 (USB0_3V3), U2.7 (OUT), U2.8 (OUT), U2.9 (OUT); also elsewhere on the board
/Power/3V3_SW: U2.4 (SW), U2.5 (SW), U2.6 (SW)
GND: C2.2, C3.2, C4.2, C5.2, C6.1, C7.1, C8.1, C9.1, C10.2, C11.2, C12.2, C13.2, C14.2, C15.2, C16.2, C17.2, C18.2, C19.2, C20.2, C21.2, C22.2, C23.2, C24.2, C25.2, C26.2, C27.2, C28.2, C29.1, C29.2, C30.2, C31.2, C147.2, C150.2, C151.2, R34.2, R36.2, R37.2, SW2.1, SW3.3 (C), U1.18 (VREFN), U1.19 (VSSA), U1.33 (USB1_VSS), U1.37 (USB1_VSS), U1.46 (VSS_DCDC), U1.47 (VSS_DCDC), U1.99 (USB0_VSS), U1.101 (VSS), U2.3 (AGND), U2.12 (PGND), U2.13 (PGND), U2.14 (PGND); also elsewhere on the board
unnamed: C6.2, U1.28 (XTAL32M_N), Y1.2
unnamed: C7.2, U1.29 (XTAL32M_P), Y1.1
unnamed: C8.2, U1.52 (XTAL32K_P), Y2.2
unnamed: C9.2, U1.53 (XTAL32K_N), Y2.1
unnamed: C22.1, C25.1, C27.1, C147.1, L3.2, U1.39 (VDD_PMU), U1.45 (FB)
unnamed: D8.1 (K), R37.1
unnamed: L3.1, U1.48 (LX)
unnamed: R31.1, SW2.2
unnamed: R33.1, SW3.2 (B)
unnamed: R33.2, U2.17 (EN)
unnamed: R34.1, U2.18 (AAM)
unnamed: R35.2, R36.1, U2.1 (FB)
RESET_TRGT: C5.1, R31.2, R32.2, U1.32 (RESETN); also elsewhere on the board
VDDA_TRGT: C12.1, C13.1, C15.1, C17.1, C19.1, C23.1, L2.2, U1.16 (VDDA), U1.17 (VREFP), U1.49 (VBAT_DCDC), U1.50 (VBAT_DCDC), U1.51 (VBAT_PMU)
VDD_TRGT: C14.1, C16.1, C18.1, C20.1, C21.1, C24.1, C26.1, C28.1, C30.1, C31.1, L1.2, U1.15 (VDD), U1.25 (VDD), U1.44 (VDD), U1.63 (VDD), U1.69 (VDD), U1.75 (VDD), U1.84 (VDD), U1.95 (VDD), U1.100 (VDD)
VIN: C2.1, C3.1, C4.1, SW3.1 (A), U2.16 (IN); also elsewhere on the board

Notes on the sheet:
3V3 Regulator
LPC55S6x Power systems
TODO: Change all the smaller Decoupling cap to same value
Ensure there is a large copper pad below the SW pins
VIN: 4.5V - 21V

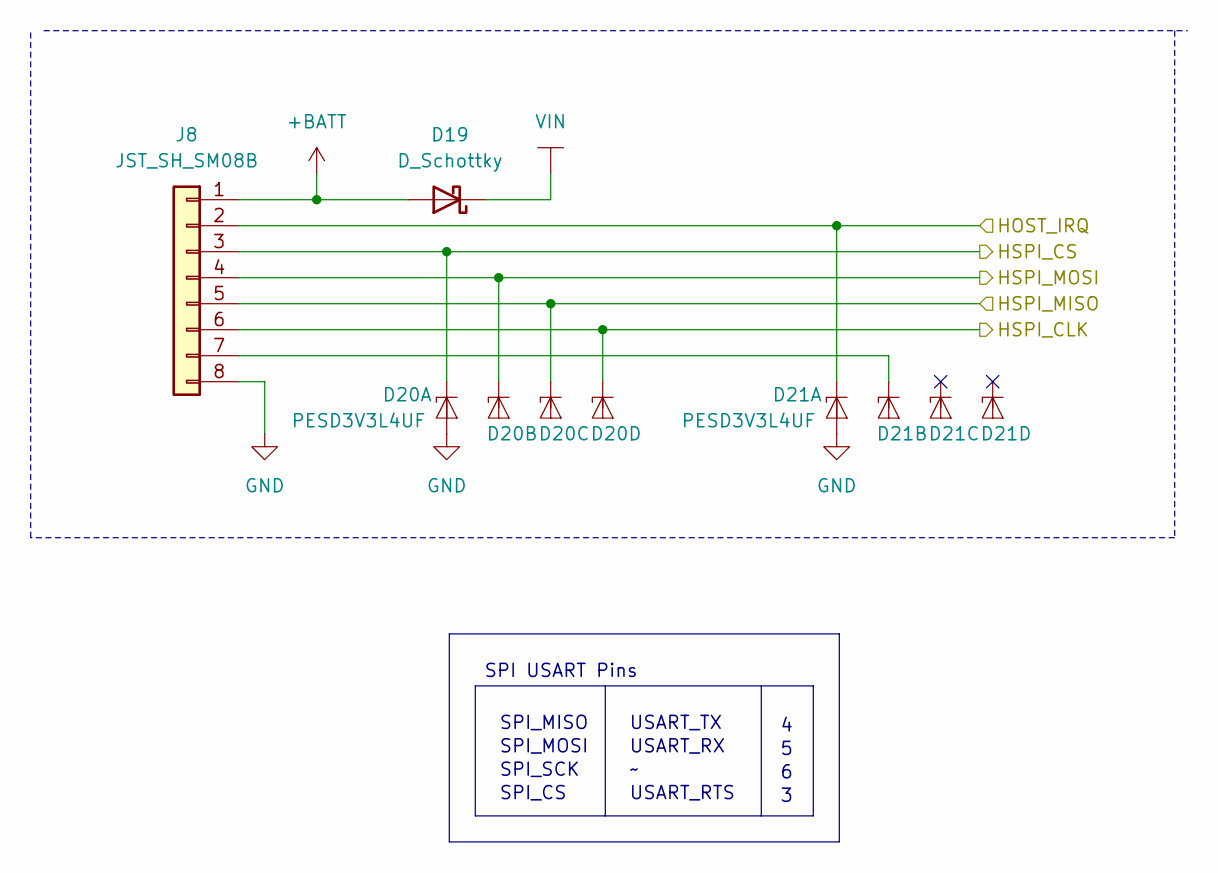
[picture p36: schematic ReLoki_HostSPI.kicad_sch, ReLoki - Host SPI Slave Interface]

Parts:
D19: D_Schottky; D_SOD-123F
D20, D21: PESD3V3L4UF; SOT-886
J8: JST_SH_SM08B; JST_SH_SM08B-SRSS-TB_1x08-1MP_P1.00mm_Horizontal

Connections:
+BATT: D19.2 (A), J8.1
/Host SPI Bus/HOST_IRQ: D21.1 (K1), J8.2; also elsewhere on the board
/Host SPI Bus/HSPI_CLK: D20.6 (K4), J8.6; also elsewhere on the board
/Host SPI Bus/HSPI_CS: D20.1 (K1), J8.3; also elsewhere on the board
/Host SPI Bus/HSPI_MISO: D20.4 (K3), J8.5; also elsewhere on the board
/Host SPI Bus/HSPI_MOSI: D20.3 (K2), J8.4; also elsewhere on the board
GND: D20.2 (A), D20.5 (A), D21.2 (A), D21.5 (A), J8.8; also elsewhere on the board
unnamed: D21.3 (K2), J8.7
VIN: D19.1 (K); also elsewhere on the board

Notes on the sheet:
SPI_MOSI
USART_RTS
SPI_SCK
USART_RX
SPI_CS
SPI_MISO
USART_TX
SPI USART Pins

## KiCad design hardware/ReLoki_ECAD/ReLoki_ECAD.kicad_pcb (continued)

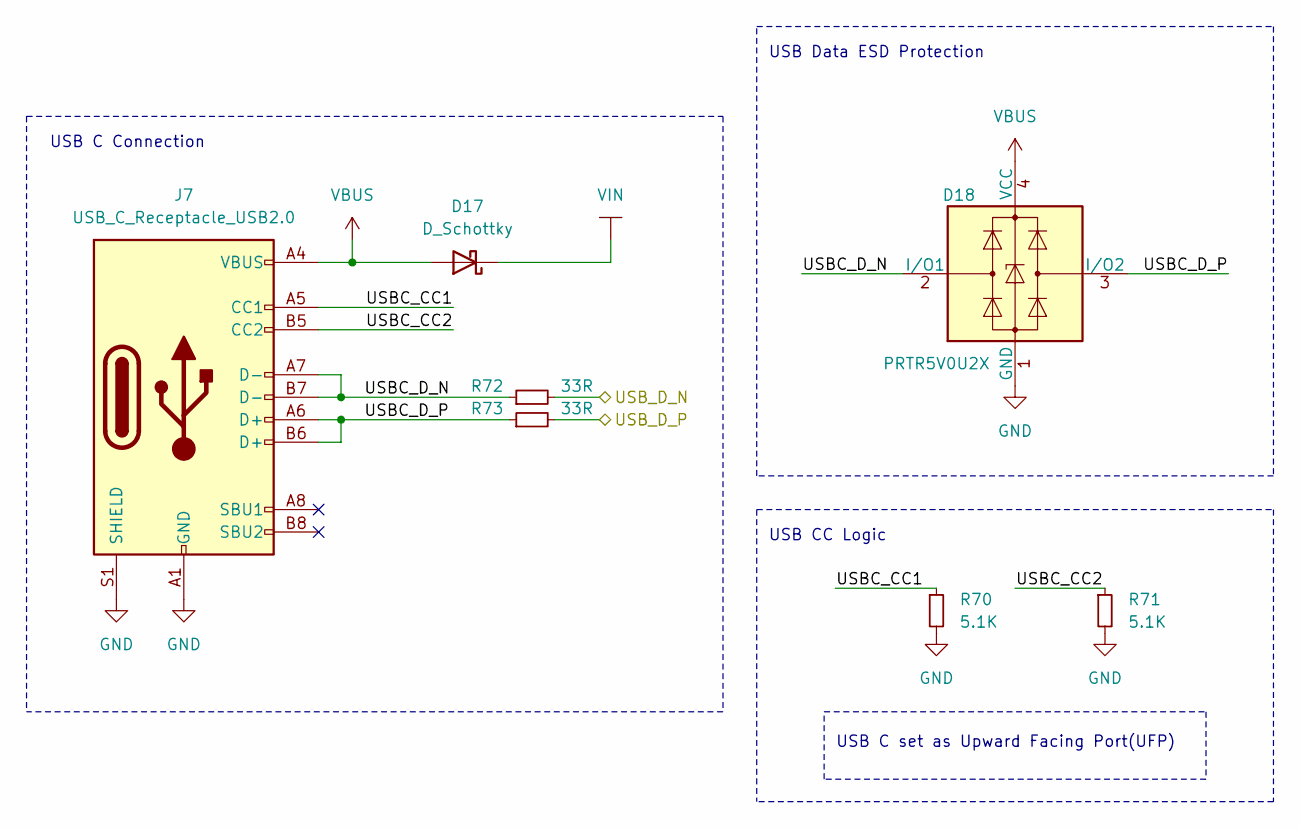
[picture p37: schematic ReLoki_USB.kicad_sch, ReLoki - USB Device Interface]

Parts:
D17: D_Schottky; D_SOD-123F
D18: PRTR5V0U2X; SOT-143
J7: USB_C_Receptacle_USB2.0; USB_C_Receptacle_XKB_U262-16XN-4BVC11
R70, R71: 5.1K; R_0402_1005Metric
R72, R73: 33R; R_0402_1005Metric

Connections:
/Microcontroller/USB1_D_N: R72.2; also elsewhere on the board
/Microcontroller/USB1_D_P: R73.2; also elsewhere on the board
/USB-C/USBC_CC1: J7.A5 (CC1), R70.1
/USB-C/USBC_CC2: J7.B5 (CC2), R71.1
/USB-C/USBC_D_N: D18.2 (I/O1), J7.A7 (D-), J7.B7 (D-), R72.1
/USB-C/USBC_D_P: D18.3 (I/O2), J7.A6 (D+), J7.B6 (D+), R73.1
GND: D18.1 (GND), J7.A1 (GND), J7.A12 (GND), J7.B1 (GND), J7.B12 (GND), J7.S1 (SHIELD), R70.2, R71.2; also elsewhere on the board
VBUS: D17.2 (A), D18.4 (VCC), J7.A4 (VBUS), J7.A9 (VBUS), J7.B4 (VBUS), J7.B9 (VBUS)
VIN: D17.1 (K); also elsewhere on the board

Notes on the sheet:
USB Data ESD Protection
USB C set as Upward Facing Port(UFP)
USB CC Logic
USB C Connection

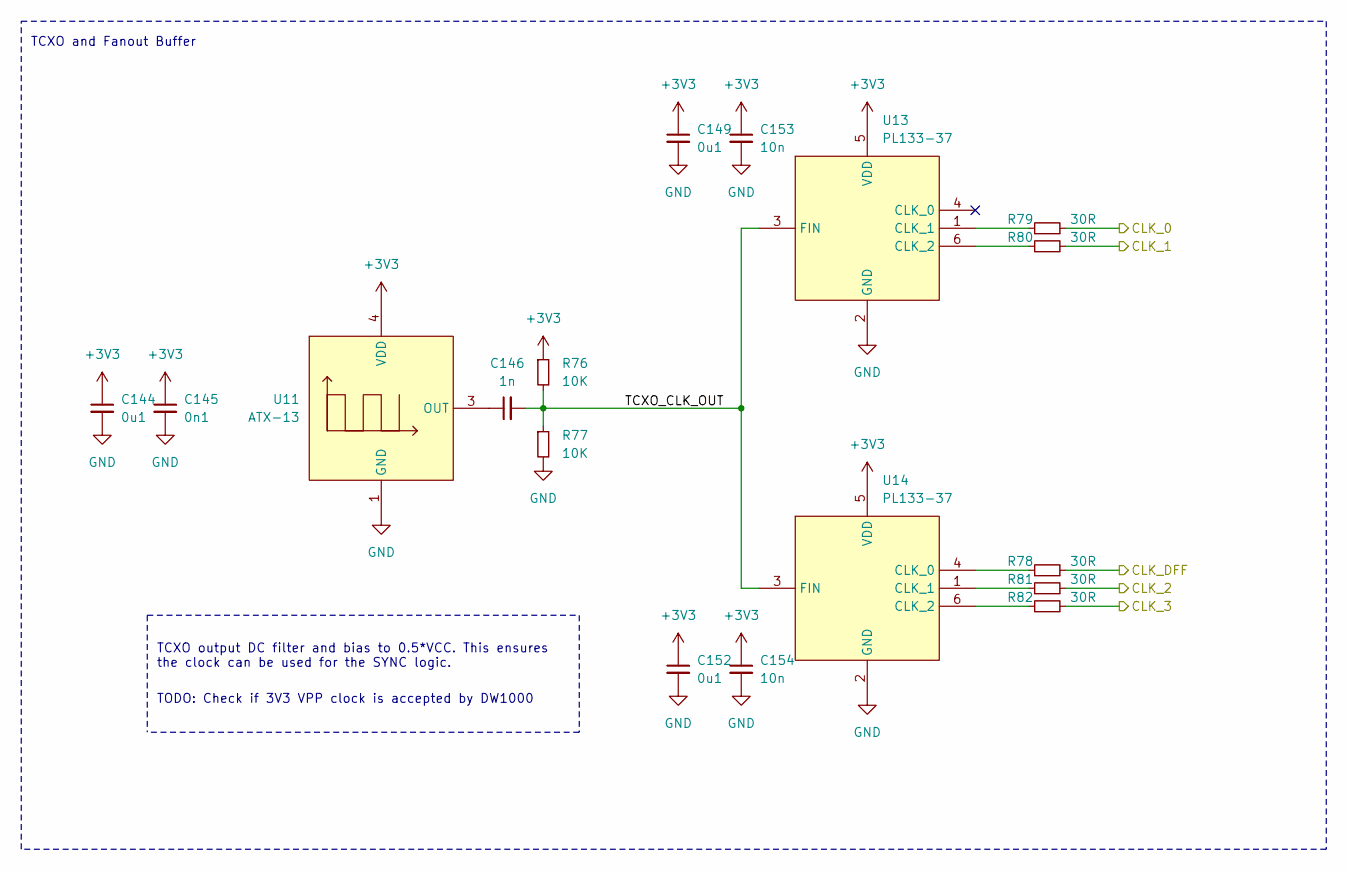
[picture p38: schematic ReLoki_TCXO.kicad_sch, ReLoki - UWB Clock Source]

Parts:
C144, C149, C152: 0u1; C_0402_1005Metric
C145: 0n1; C_0402_1005Metric
C146: 1n; C_0402_1005Metric
C153, C154: 10n; C_0402_1005Metric
R76, R77: 10K; R_0402_1005Metric
R78, R79, R80, R81, R82: 30R; R_0402_1005Metric
U11: ATX-13; Oscillator_SMD_Abracon_ATX13-4Pin_2.0x1.6mm
U13, U14: PL133-37; SOT-23-6

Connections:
+3V3: C144.1, C145.1, C149.1, C152.1, C153.1, C154.1, R76.1, U11.4 (VDD), U13.5 (VDD), U14.5 (VDD); also elsewhere on the board
/Microcontroller/CLK_DFF: R78.2; also elsewhere on the board
/TCXO/CLK_0: R79.2; also elsewhere on the board
/TCXO/CLK_1: R80.2; also elsewhere on the board
/TCXO/CLK_2: R81.2; also elsewhere on the board
/TCXO/CLK_3: R82.2; also elsewhere on the board
/TCXO/TCXO_CLK_OUT: C146.2, R76.2, R77.1, U13.3 (FIN), U14.3 (FIN)
GND: C144.2, C145.2, C149.2, C152.2, C153.2, C154.2, R77.2, U11.1 (GND), U11.2 (GND), U13.2 (GND), U14.2 (GND); also elsewhere on the board
unnamed: C146.1, U11.3 (OUT)
unnamed: R78.1, U14.4 (CLK_0)
unnamed: R79.1, U13.1 (CLK_1)
unnamed: R80.1, U13.6 (CLK_2)
unnamed: R81.1, U14.1 (CLK_1)
unnamed: R82.1, U14.6 (CLK_2)

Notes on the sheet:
TCXO output DC filter and bias to 0.5*VCC. This ensures the clock can be used for the SYNC logic.
TCXO and Fanout Buffer
TODO: Check if 3V3 VPP clock is accepted by DW1000

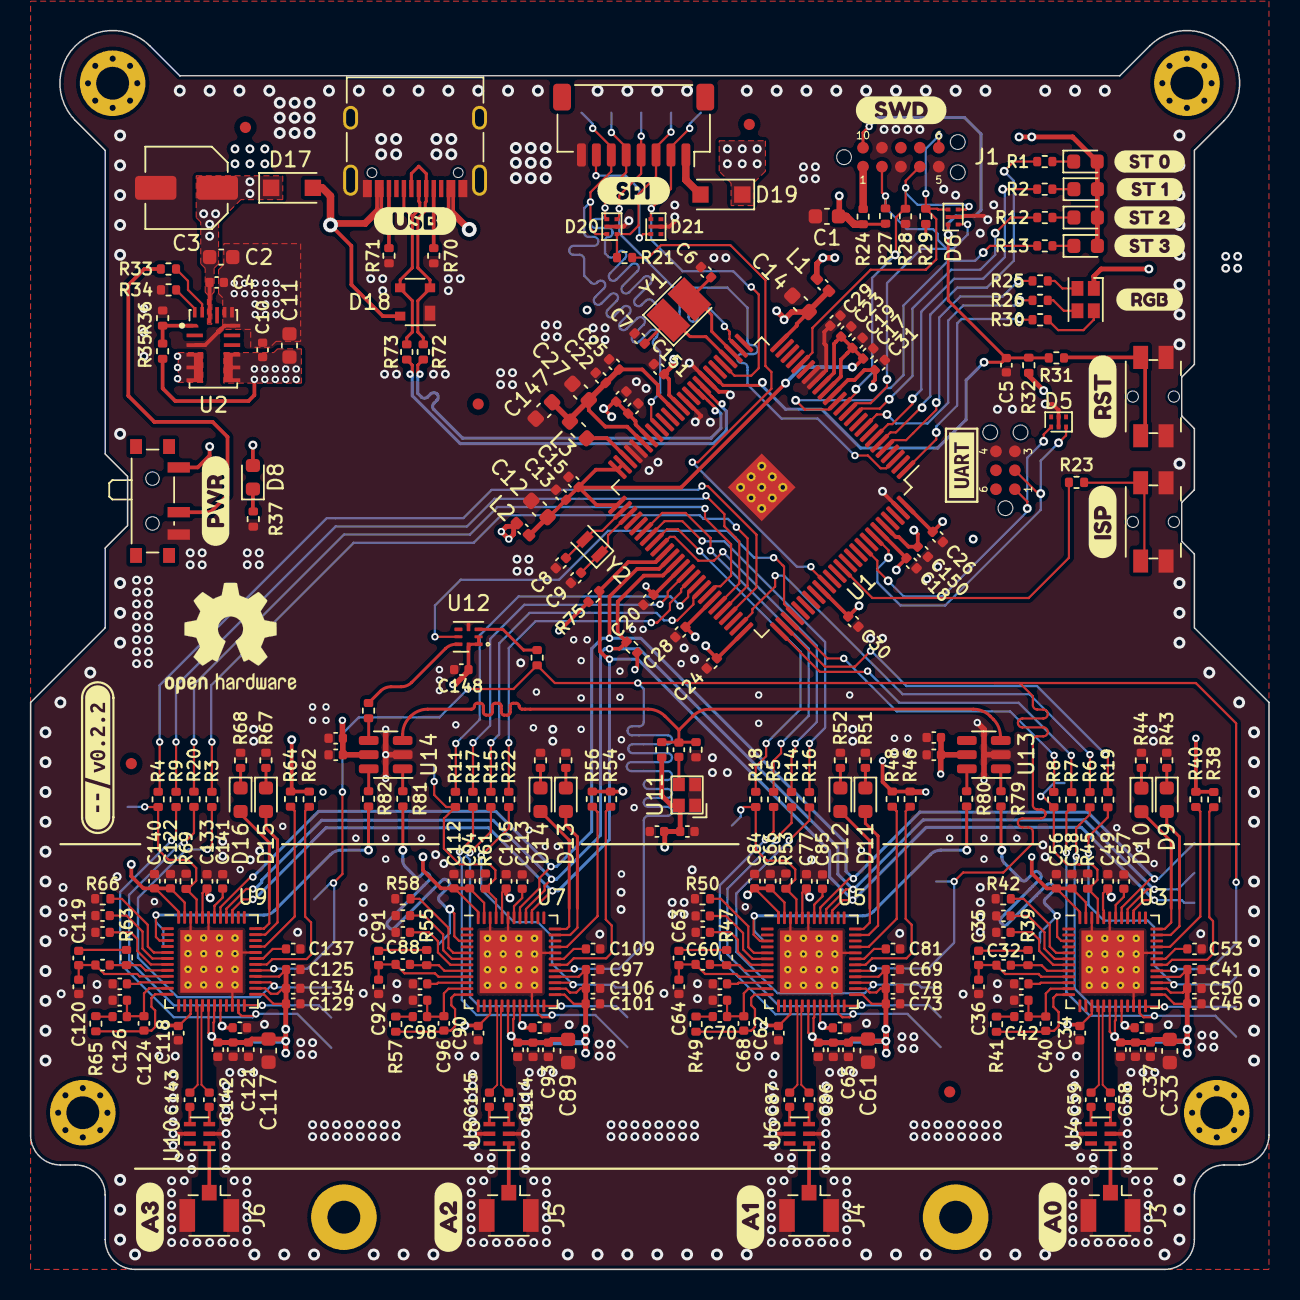
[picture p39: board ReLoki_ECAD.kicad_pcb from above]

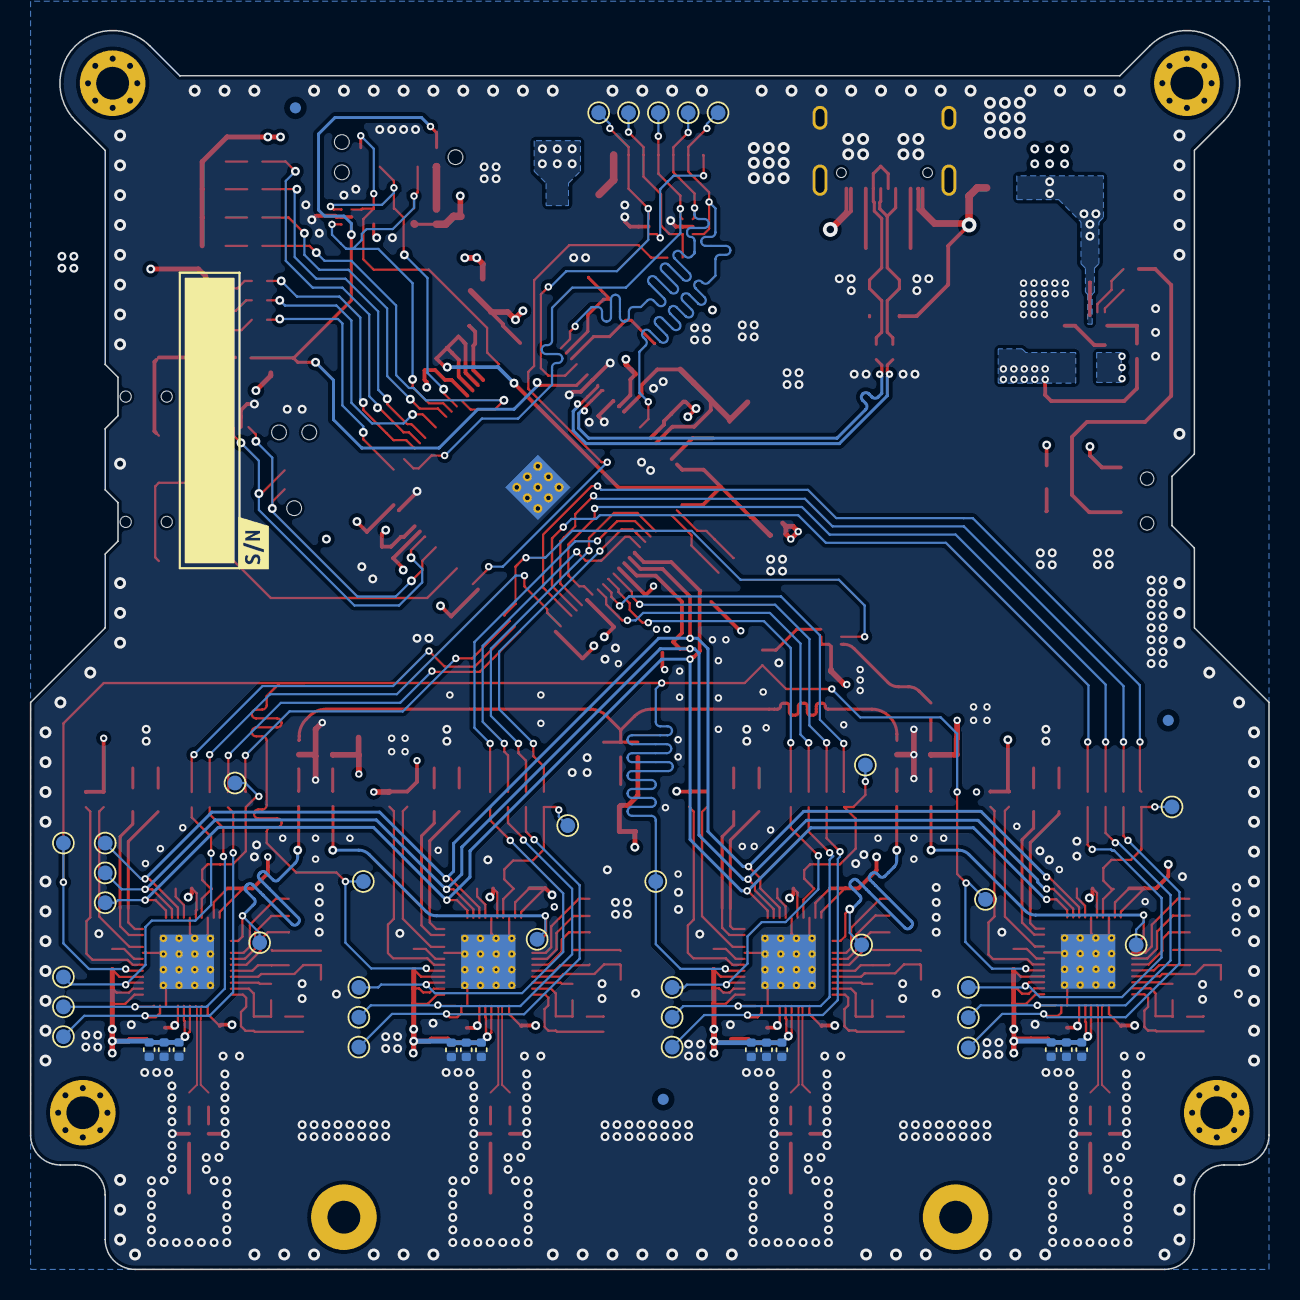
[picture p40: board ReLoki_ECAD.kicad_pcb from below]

Board: 4 copper layers, 83.0 x 83.0 mm, 352 parts (48 on the bottom side), 202 nets.

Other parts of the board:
kibuzzard-6352BF52: G***; kibuzzard-6352BF52
kibuzzard-6352BF92: G***; kibuzzard-6352BF92
kibuzzard-6352C04F: G***; kibuzzard-6352C04F
kibuzzard-6352C008: G***; kibuzzard-6352C008
kibuzzard-6352C032: G***; kibuzzard-6352C032
kibuzzard-6352C089: G***; kibuzzard-6352C089
kibuzzard-6352CA9B: G***; kibuzzard-6352CA9B
kibuzzard-6352CA75: G***; kibuzzard-6352CA75
kibuzzard-6352CA94: G***; kibuzzard-6352CA94
kibuzzard-6352CAA2: G***; kibuzzard-6352CAA2
kibuzzard-6352EB6B: G***; kibuzzard-6352EB6B
kibuzzard-6352EB8E: G***; kibuzzard-6352EB8E
kibuzzard-6352EB70: G***; kibuzzard-6352EB70
kibuzzard-6352EB77: G***; kibuzzard-6352EB77
kibuzzard-6352EB82: G***; kibuzzard-6352EB82
kibuzzard-66328E0B: G***; kibuzzard-66328E0B
kibuzzard-66328EE8: G***; kibuzzard-66328EE8
kibuzzard-66328F53: G***; kibuzzard-66328F53
kibuzzard-66328FDF: G***; kibuzzard-66328FDF
